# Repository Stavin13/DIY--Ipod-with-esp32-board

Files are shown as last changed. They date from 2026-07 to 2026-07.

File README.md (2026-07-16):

# ESP32-S3 iPod Music Player

A custom-built portable music player with modern touch interface and physical controls.

## Hardware Specifications

- **MCU**: ESP32-S3 (16MB Flash, 8MB PSRAM)
- **Display**: 2.8" ILI9341 capacitive touch (240x320px)
- **Storage**: 256GB microSD card
- **Audio**: USB-C (PCM2912A codec) + 3.5mm jack
- **Power**: USB-C PD (IP2723T) + 18650 LiPo (3500mAh)
- **Input**: Rotary encoder (KY-040) + capacitive touch
- **Connectivity**: Bluetooth 5.0 A2DP

## Key Features

- USB-C Power Delivery (15W charging)
- Simultaneous charging and digital audio output
- Bluetooth wireless streaming
- Touch + rotary encoder navigation
- 24-bit/96kHz audio quality
- 6-8 hours battery life
- OTA updates

## Development Phases

1. **Phase 1**: Core Hardware Setup
2. **Phase 2**: Basic Software (Display, SD, Audio, Encoder)
3. **Phase 3**: Advanced Features (USB-C, Bluetooth, Touch)
4. **Phase 4**: Polish (Album Art, Animations, EQ)

## Budget: ₹3,450 (~$45 USD)

## Timeline: 12 weeks

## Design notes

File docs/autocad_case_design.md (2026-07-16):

# AutoCAD Case Design Tutorial - ESP32-S3 iPod

## Software Options

### **AutoCAD (Professional)**
- **Best for**: Precise 2D drawings, technical documentation
- **Cost**: 
  - **Students**: FREE (3-year license)
  - **Commercial**: ₹15,000/year (subscription)
- **Learning curve**: Moderate to steep
- **Get it**: education.autodesk.com with student email

### **Fusion 360 (Recommended for 3D)**
- **Best for**: 3D modeling, parametric design
- **Cost**: 
  - **Students**: FREE (3-year license)
  - **Personal**: FREE (limited features)
  - **Commercial**: $545/year
- **Learning curve**: Easier than AutoCAD for 3D

### **Free Alternatives**
- **FreeCAD**: Open source, similar to Fusion 360
- **Tinkercad**: Browser-based, very beginner friendly
- **SketchUp**: Easy 3D modeling

## How to Get Free Student Licenses

### **Autodesk Education (AutoCAD + Fusion 360)**

#### **Requirements:**
- **Valid student email** (.edu or institution email)
- **Student ID** or enrollment verification
- **Academic institution** (college, university, trade school)

#### **Steps to Get Free Access:**
1. **Visit**: education.autodesk.com
2. **Create account** with student email
3. **Verify student status** (upload student ID)
4. **Download software**:
   - AutoCAD (2D/3D design)
   - Fusion 360 (3D modeling)
   - Inventor (3D mechanical design)
   - Maya (3D animation)
   - 3ds Max (3D modeling)

#### **What You Get:**
- **3-year license** (renewable)
- **Full professional version** (not limited)
- **All features unlocked**
- **Commercial-grade tools**
- **Free updates**

### **Alternative Student Programs**

#### **SolidWorks Student Edition**
- **Cost**: ₹3,000-5,000/year for students
- **Features**: Full professional CAD suite
- **Best for**: Mechanical engineering projects

#### **Onshape (Browser-based)**
- **Cost**: Free for students and public projects
- **Features**: Cloud-based CAD, collaboration
- **Best for**: Team projects, no installation needed

## Software Comparison for Your iPod Case

### **AutoCAD (Free for Students)**
#### **Pros:**
✅ **Industry standard** - Widely used professionally
✅ **Precise 2D drafting** - Perfect technical drawings
✅ **3D capabilities** - Can create 3D models
✅ **Free for students** - No cost barrier
✅ **Extensive tutorials** - Lots of learning resources

#### **Cons:**
❌ **Steep learning curve** - Takes time to master
❌ **Complex interface** - Many tools and options
❌ **Better for 2D** - 3D modeling is more complex

#### **Best for Your Project:**
- Creating **technical drawings** with precise dimensions
- **2D profiles** that can be exported to other 3D software
- **Professional documentation** of your design

### **Fusion 360 (Free for Students)**
#### **Pros:**
✅ **Modern 3D modeling** - Intuitive parametric design
✅ **Integrated workflow** - Sketch → Model → Simulate → Manufacture
✅ **Built-in 3D printing** - Direct STL export
✅ **Cloud-based** - Access from anywhere
✅ **Easier learning curve** - More user-friendly

#### **Cons:**
❌ **Internet required** - Cloud-based software
❌ **Less precise 2D** - Not as good for technical drawings

#### **Best for Your Project:**
- **3D modeling** the actual case
- **Parametric design** - Easy to modify dimensions
- **3D printing preparation** - Built-in tools

## Recommended Workflow (Using Both)

### **Phase 1: Planning in AutoCAD**
1. **Create precise 2D drawings**
   - Front view with exact dimensions
   - Side view with component layout
   - Bottom view with port positions
2. **Technical documentation**
   - Dimension drawings
   - Assembly instructions
   - Bill of materials

### **Phase 2: 3D Modeling in Fusion 360**
1. **Import 2D profiles** from AutoCAD
2. **Create 3D model** using sketches
3. **Add features** (fillets, chamfers, etc.)
4. **Test fit** with component models
5. **Export STL** for 3D printing

### **Phase 3: Manufacturing**
1. **3D print** prototype from Fusion 360
2. **Test fit** with actual components
3. **Iterate design** based on testing
4. **Final production** files

## Getting Started Steps

### **1. Get Student Licenses (Free)**
```
Visit: education.autodesk.com
Sign up with: your student email
Download: AutoCAD + Fusion 360
Verify: student status (may take 24-48 hours)
```

### **2. Learn the Basics**
#### **AutoCAD (2-3 hours)**
- Basic drawing commands (LINE, RECTANGLE, CIRCLE)
- Modification tools (MOVE, COPY, FILLET)
- Dimensioning and layers
- 2D layout of your iPod case

#### **Fusion 360 (3-4 hours)**
- Sketching basics
- Extrude and revolve features
- Assembly and constraints
- 3D modeling your case

### **3. Design Your Case**
#### **Week 1: AutoCAD**
- Measure all components precisely
- Create 2D technical drawings
- Plan internal layout

#### **Week 2: Fusion 360**
- Build 3D model from 2D drawings
- Add all features and cutouts
- Export STL for printing

## Learning Resources

### **AutoCAD Tutorials**
- **Autodesk University** (free courses)
- **YouTube**: "AutoCAD Basics" by Autodesk
- **LinkedIn Learning**: AutoCAD courses
- **Local colleges**: Often offer CAD courses

### **Fusion 360 Tutorials**
- **Fusion 360 Academy** (official tutorials)
- **YouTube**: "Learn Fusion 360 in 30 Days"
- **Coursera**: Fusion 360 for Beginners
- **Udemy**: Fusion 360 courses (often ₹500-1000)

### **Step 1: Set Up Your Workspace**

#### **Create New Drawing**
```
File → New → acadiso.dwt (metric template)
```

#### **Set Units**
```
Format → Units
- Type: Decimal
- Precision: 0.00
- Insertion scale: Millimeters
```

#### **Set Up Layers**
```
Layer Properties Manager (LA command):
- Layer 1: "OUTLINE" (Red, 0.5mm line)
- Layer 2: "DIMENSIONS" (Blue, 0.25mm line)  
- Layer 3: "COMPONENTS" (Green, 0.35mm line)
- Layer 4: "CUTOUTS" (Magenta, 0.5mm line)
- Layer 5: "CENTERLINES" (Yellow, dashed)
```

### **Step 2: Create the Basic Outline**

#### **Draw Main Rectangle**
```
Command: RECTANGLE (REC)
First corner: 0,0
Other corner: 70,110
```

#### **Add Rounded Corners**
```
Command: FILLET (F)
Radius: 8
Select first line: [click top edge]
Select second line: [click right edge]
Repeat for all 4 corners
```

### **Step 3: Add Component Cutouts**

#### **Display Cutout (Front View)**
```
Command: RECTANGLE
First corner: 10,25
Other corner: 60,85
(Creates 50×60mm display opening)

Command: FILLET
Radius: 2
Apply to all corners of display rectangle
```

#### **USB-C Port (Bottom View)**
```
Command: RECTANGLE  
First corner: 30,0
Other corner: 40,5
(Creates 10×5mm USB-C cutout)

Command: FILLET
Radius: 1
Apply to top corners only
```

#### **Power Button (Bottom View)**
```
Command: CIRCLE
Center: 55,2.5
Radius: 2
(Creates 4mm diameter button hole)
```

#### **SD Card Slot (Side View)**
```
Command: RECTANGLE
First corner: 70,40
Other corner: 75,55
(Creates 5×15mm SD slot)
```

### **Step 4: Add Internal Component Layout**

#### **Switch to "COMPONENTS" Layer**
```
Layer Properties → Set "COMPONENTS" as current
```

#### **ESP32-S3 Footprint**
```
Command: RECTANGLE
First corner: 15,15
Other corner: 40,35
(25×20mm ESP32 module)
```

#### **Display Module**
```
Command: RECTANGLE
First corner: 8,22
Other corner: 62,88
(54×66mm display module)
```

#### **Battery Compartment**
```
Command: CIRCLE
Center: 35,70
Radius: 9
(18mm diameter for 18650 battery)

Command: RECTANGLE
First corner: 26,70
Other corner: 44,95
(18×25mm battery length)
```

#### **USB-C PD Board**
```
Command: RECTANGLE
First corner: 45,15
Other corner: 65,35
(20×20mm PD board)
```

### **Step 5: Create Cross-Section Views**

#### **Side Cross-Section**
```
Command: LINE
Draw vertical line at X=35 (centerline)

Show internal stack:
- Front cover: 0-1mm
- Display: 1-4mm  
- PCB space: 4-6mm
- Components: 6-9mm
- Battery: 9-12mm
- Back cover: 12-15mm
```

### **Step 6: Add Dimensions**

#### **Switch to "DIMENSIONS" Layer**
```
Layer Properties → Set "DIMENSIONS" as current
```

#### **Overall Dimensions**
```
Command: DIMLINEAR (DLI)
- Overall width: 70mm
- Overall height: 110mm
- Overall depth: 15mm
```

#### **Component Dimensions**
```
Command: DIMLINEAR
- Display opening: 50×60mm
- USB-C cutout: 10×5mm
- Button hole: ⌀4mm
- Corner radius: R8mm
```

### **Step 7: Create 3D Model (Optional)**

#### **Extrude the Profile**
```
Command: EXTRUDE (EXT)
Select: Main outline
Height: 15
Taper: 0
```

#### **Subtract Cutouts**
```
Command: SUBTRACT (SU)
Select solids to subtract from: [main body]
Select solids to subtract: [all cutouts]
```

### **Step 8: Create Technical Drawings**

#### **Front View**
```
- Main outline with rounded corners
- Display cutout
- Component positions (dashed lines)
- Dimensions and tolerances
```

#### **Bottom View**
```
- USB-C port cutout
- Power button hole
- Screw hole positions
- Assembly notes
```

#### **Side View**
```
- Internal component stack
- Wall thickness (2mm minimum)
- Ventilation considerations
```

#### **Exploded View**
```
- Front bezel
- Main body
- Internal components
- Back cover
- Assembly sequence
```

## AutoCAD Commands Cheat Sheet

### **Essential Drawing Commands**
```
LINE (L)        - Draw lines
RECTANGLE (REC) - Draw rectangles  
CIRCLE (C)      - Draw circles
ARC (A)         - Draw arcs
POLYLINE (PL)   - Draw connected lines
SPLINE (SPL)    - Draw curves
```

### **Modification Commands**
```
MOVE (M)        - Move objects
COPY (CO)       - Copy objects
ROTATE (RO)     - Rotate objects
SCALE (SC)      - Scale objects
FILLET (F)      - Round corners
CHAMFER (CHA)   - Cut corners
TRIM (TR)       - Trim lines
EXTEND (EX)     - Extend lines
```

### **Precision Tools**
```
OSNAP (F3)      - Object snaps
ORTHO (F8)      - Orthogonal mode
POLAR (F10)     - Polar tracking
OTRACK (F11)    - Object tracking
```

### **View Commands**
```
ZOOM (Z)        - Zoom in/out
PAN (P)         - Pan view
REGEN (RE)      - Regenerate display
```

## Design Tips for 3D Printing

### **Wall Thickness**
- **Minimum**: 1.5mm for structural walls
- **Recommended**: 2-3mm for durability
- **Thick areas**: 4-5mm around screw holes

### **Tolerances**
- **Tight fit**: +0.1mm clearance
- **Sliding fit**: +0.2mm clearance  
- **Loose fit**: +0.3mm clearance
- **Threaded holes**: Tap size -0.2mm

### **Support Considerations**
- **Overhangs**: Keep under 45° angle
- **Bridges**: Maximum 5mm without support
- **Holes**: Vertical holes print better than horizontal

### **Assembly Features**
```
Snap-fit clips:   0.5mm deflection
Screw bosses:     M3 screws, 5mm diameter boss
Press-fit pins:   0.1mm interference fit
Living hinges:    0.8mm thickness
```

## Export for 3D Printing

### **From AutoCAD to STL**
```
1. Create 3D solid model
2. Command: 3DPRINT
3. Select objects
4. Choose STL format
5. Set units to millimeters
6. Export to file
```

### **Alternative Workflow**
```
AutoCAD → Export DWG → Import to Fusion 360 → Create 3D model → Export STL
```

## File Organization

### **Recommended File Structure**
```
iPod_Case_Project/
├── Drawings/
│   ├── iPod_Front_View.dwg
│   ├── iPod_Side_View.dwg
│   ├── iPod_Bottom_View.dwg
│   └── iPod_Assembly.dwg
├── 3D_Models/
│   ├── Front_Bezel.dwg
│   ├── Main_Body.dwg
│   └── Back_Cover.dwg
├── Export/
│   ├── Technical_Drawings.pdf
│   └── 3D_Models.stl
└── Reference/
    ├── Component_Datasheets.pdf
    └── Measurement_Photos.jpg
```

## Next Steps

1. **Practice basic commands** with simple shapes
2. **Measure your actual components** for accurate dimensions
3. **Create 2D technical drawings** first
4. **Build 3D model** from 2D profiles
5. **Export STL files** for 3D printing
6. **Test print** a small section first

Would you like me to create specific AutoCAD command sequences for any particular part of the case design?

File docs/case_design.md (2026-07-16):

# 3D Case Design - ESP32-S3 iPod

## Overall Design Philosophy

**Modern iPod Classic** - Clean, minimalist design inspired by the iconic iPod but with contemporary touches like USB-C and a larger color display.

## Dimensions & Form Factor

### **Overall Size**
```
Width:  70mm (2.75")
Height: 110mm (4.33") 
Depth:  15mm (0.59")
Weight: ~150g (with battery)
```

### **Comparison to Original iPod**
- **iPod Classic**: 62×104×10mm
- **Our iPod**: 70×110×15mm (slightly larger for modern components)

## Front Face Design

```
┌─────────────────────────────────┐ ← 70mm wide
│  ┌─────────────────────────┐   │
│  │                         │   │ ← 2.8" Display
│  │     240×320 Display     │   │   (60×45mm active area)
│  │                         │   │
│  │                         │   │
│  └─────────────────────────┘   │
│                                 │
│        ┌─────────────┐         │ ← Rotary Encoder
│        │      ●      │         │   (if included)
│        │   ┌─────┐   │         │
│        │   │  ○  │   │         │ ← Center button
│        │   └─────┘   │         │
│        └─────────────┘         │
│                                 │
│  ESP32-S3 iPod                 │ ← Branding
└─────────────────────────────────┘ ← 110mm tall
```

## Side Views & Ports

### **Left Side**
```
┌─────────────────┐
│                 │ ← Clean, no ports
│                 │
│                 │
│                 │
└─────────────────┘
```

### **Right Side**  
```
┌─────────────────┐
│                 │
│    ┌──┐         │ ← MicroSD slot
│    └──┘         │   (spring-loaded)
│                 │
└─────────────────┘
```

### **Bottom Edge (Single USB-C)**
```
┌─────────────────────────────────┐
│           ⚡        ○           │
│         USB-C    Power          │
│    (Audio/Charge) Button        │
└─────────────────────────────────┘
```

**Much cleaner!** Just like modern smartphones and tablets.

### **Top Edge**
```
┌─────────────────────────────────┐
│                                 │ ← Clean, minimal
└─────────────────────────────────┘
```

## Internal Layout (Cross-Section)

### **Layer Stack (Front to Back)**
```
Front Glass/Acrylic (1mm)
├─ Display Module (3mm)
├─ Main PCB/Breadboard (2mm)
├─ ESP32-S3 + Components (3mm)
├─ USB-C PD Board (2mm)
├─ 18650 Battery (18mm diameter)
└─ Back Cover (2mm)

Total Depth: ~15mm
```

### **Component Arrangement**
```
Top View (Internal):
┌─────────────────────────────────┐
│ ┌─────────────────────────┐     │
│ │      Display PCB        │     │
│ └─────────────────────────┘     │
│                                 │
│ ┌──────┐  ┌─────────┐          │
│ │ESP32 │  │USB-C PD │          │
│ │ S3   │  │ Board   │          │
│ └──────┘  └─────────┘          │
│                                 │
│ ┌─────────────────────────┐     │
│ │    18650 Battery        │     │
│ │    (3500mAh)           │     │
│ └─────────────────────────┘     │
│                                 │
│ ┌────┐                         │
│ │ SD │  ┌─────────────┐        │
│ │Card│  │  Encoder    │        │
│ └────┘  │  (optional) │        │
│         └─────────────┘        │
└─────────────────────────────────┘
```

## Single USB-C Design Benefits

### **Ultra-Clean Aesthetic** ✨
- **Minimalist bottom edge** - Just one port + power button
- **Symmetrical design** - USB-C centered, power button offset
- **Modern look** - Like iPhone, iPad, MacBook design language
- **No confusion** - One port does everything

### **User Experience**
```
Plug in charger     → Device charges
Plug in headphones  → Audio plays  
Plug in computer    → File transfer
Nothing plugged in  → Battery mode
```

### **Case Design Advantages**
- **Simpler manufacturing** - Fewer cutouts to machine
- **Better structural integrity** - Less material removed
- **Easier sealing** - Fewer openings for dust/water
- **More space inside** - Room for bigger battery or components

### **Port Layout Options**

#### **Option A: Centered USB-C**
```
┌─────────────────────────────────┐
│        ⚡           ○          │
│      USB-C       Power         │
└─────────────────────────────────┘
```

#### **Option B: Off-Center (More Balanced)**
```
┌─────────────────────────────────┐
│     ⚡              ○          │
│   USB-C          Power         │
└─────────────────────────────────┘
```

#### **Option C: Corner Placement**
```
┌─────────────────────────────────┐
│ ⚡                        ○    │
│USB-C                   Power   │
└─────────────────────────────────┘
```

### **Version 1: Touch + Encoder (Classic iPod Style)**
```
Front Face:
┌─────────────────────────────────┐
│  ┌─────────────────────────┐   │
│  │    Touch Display        │   │
│  └─────────────────────────┘   │
│                                 │
│        ┌─────────────┐         │
│        │  Scroll     │         │ ← iPod-style
│        │   Wheel     │         │   click wheel
│        │     ●       │         │
│        └─────────────┘         │
└─────────────────────────────────┘
```

### **Version 2: Touch Only (Modern Style)**
```
Front Face:
┌─────────────────────────────────┐
│  ┌─────────────────────────┐   │
│  │                         │   │
│  │    Large Touch          │   │ ← Bigger display
│  │     Display             │   │   area
│  │                         │   │
│  │                         │   │
│  └─────────────────────────┘   │
│                                 │
│  ┌─┐ ┌─┐ ┌─┐                  │ ← Capacitive
│  │◀│ │●│ │▶│                  │   touch buttons
│  └─┘ └─┘ └─┘                  │
└─────────────────────────────────┘
```

### **Version 3: Minimal (Ultra-Clean)**
```
Front Face:
┌─────────────────────────────────┐
│                                 │
│  ┌─────────────────────────┐   │
│  │                         │   │
│  │     Full Touch          │   │ ← Edge-to-edge
│  │     Display             │   │   display
│  │                         │   │
│  │                         │   │
│  └─────────────────────────┘   │
│                                 │
└─────────────────────────────────┘
```

## Material & Finish Options

### **Budget Version (₹200)**
- **Material**: PLA plastic (3D printed)
- **Finish**: Matte black or white
- **Features**: Basic functionality, simple design

### **Premium Version (₹500)**
- **Material**: ABS plastic with post-processing
- **Finish**: Glossy white (iPod classic style)
- **Features**: Smooth finish, better fit and finish

### **Luxury Version (₹1000)**
- **Material**: Aluminum (CNC machined) or high-quality resin
- **Finish**: Anodized aluminum or polished resin
- **Features**: Premium feel, perfect fit, professional appearance

## Color Options

### **Classic iPod Colors**
- **iPod White** - Glossy white with silver accents
- **Space Gray** - Matte dark gray
- **Product Red** - Glossy red finish
- **Rose Gold** - Light pink/gold metallic

### **Modern Colors**
- **Midnight Black** - Deep matte black
- **Ocean Blue** - Deep blue with metallic finish
- **Forest Green** - Dark green matte
- **Sunset Orange** - Vibrant orange

## Assembly Features

### **Easy Assembly Design**
```
┌─────────────────────────────────┐
│ Front Bezel (clips on)          │
├─────────────────────────────────┤
│ Main Body (screws together)     │
├─────────────────────────────────┤
│ Back Cover (removable)          │
└─────────────────────────────────┘
```

### **Access Points**
- **Battery compartment** - Removable back cover
- **SD card slot** - Side access with spring mechanism
- **USB-C ports** - Bottom cutouts with proper clearance
- **Display** - Front bezel with gasket seal

## Special Features

### **Display Protection**
- **Tempered glass** or **acrylic window** (₹100)
- **Anti-glare coating** option
- **Oleophobic coating** for fingerprint resistance

### **Ergonomics**
- **Rounded edges** for comfortable grip
- **Textured back** for better grip
- **Balanced weight distribution**
- **Pocket-friendly size**

### **Cooling**
- **Ventilation slots** (hidden in design)
- **Heat dissipation channels** for ESP32
- **Thermal pads** for hot components

## 3D Printing Specifications

### **Print Settings**
```
Layer Height: 0.2mm
Infill: 20-30%
Supports: Yes (for overhangs)
Print Speed: 50mm/s
Nozzle Temp: 210°C (PLA) / 250°C (ABS)
Bed Temp: 60°C (PLA) / 100°C (ABS)
```

### **Post-Processing**
1. **Remove supports** carefully
2. **Sand smooth** (220 → 400 → 800 grit)
3. **Prime and paint** (if desired)
4. **Apply clear coat** for durability

## Cost Breakdown

### **DIY 3D Printing**
- **Filament cost**: ₹50-100
- **Print time**: 8-12 hours
- **Post-processing**: 2-4 hours
- **Total**: ₹50-100 + time

### **Professional 3D Printing Service**
- **Basic PLA**: ₹200-300
- **Premium ABS**: ₹400-600
- **Resin (high detail)**: ₹600-1000

### **CNC Aluminum** (Ultimate)
- **Material + machining**: ₹2000-5000
- **Anodizing**: ₹500-1000
- **Total**: ₹2500-6000

## Files Provided

When you're ready to build, I can provide:
- **3D CAD files** (.step, .stl)
- **Technical drawings** with dimensions
- **Assembly instructions** with photos
- **Bill of materials** for hardware (screws, etc.)
- **Print settings** optimized for different printers

The case design balances the iconic iPod aesthetic with modern functionality - clean, minimal, but with all the ports and features you need for a contemporary music player!

Which style appeals to you most? The classic iPod look with the scroll wheel, or a more modern touch-only design?

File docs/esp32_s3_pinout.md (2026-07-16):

# ESP32-S3-N16R8 Pinout & iPod Pin Usag

## ESP32-S3-N16R8 Complete Pinout

```
                    ESP32-S3-N16R8 DevKit-C
                    ┌─────────────────────┐
                    │                     │
                    │        USB-C        │
                    │                     │
    3V3  ●──────────┤ 3V3             EN  ├──────────● EN
    GND  ●──────────┤ GND            IO0  ├──────────● GPIO0 (Boot)
    TX   ●──────────┤ TX             IO1  ├──────────● GPIO1 🎵 ENCODER_CLK
    RX   ●──────────┤ RX             IO2  ├──────────● GPIO2 🎵 ENCODER_DT
    GPIO1●──────────┤ IO1            IO42 ├──────────● GPIO42
    GPIO2●──────────┤ IO2            IO41 ├──────────● GPIO41
    GPIO42●─────────┤ IO42           IO40 ├──────────● GPIO40
    GPIO41●─────────┤ IO41           IO39 ├──────────● GPIO39 🔋 POWER_ENABLE
    GPIO40●─────────┤ IO40           IO38 ├──────────● GPIO38 💾 SD_SCLK
    GPIO39●─────────┤ IO39           IO37 ├──────────● GPIO37 💾 SD_MISO
    GPIO38●─────────┤ IO38           IO36 ├──────────● GPIO36 💾 SD_MOSI
    GPIO37●─────────┤ IO37           IO35 ├──────────● GPIO35 💾 SD_CS
    GPIO36●─────────┤ IO36           IO0  ├──────────● GPIO0 (Boot)
    GPIO35●─────────┤ IO35           IO45 ├──────────● GPIO45
    GPIO0 ●─────────┤ IO0            IO48 ├──────────● GPIO48
    GPIO45●─────────┤ IO45           IO47 ├──────────● GPIO47
    GPIO48●─────────┤ IO48           IO21 ├──────────● GPIO21 🔋 CHARGE_STATUS
    GPIO47●─────────┤ IO47           IO14 ├──────────● GPIO14
    GPIO21●─────────┤ IO21           IO13 ├──────────● GPIO13 📺 TFT_MISO
    GPIO14●─────────┤ IO14           IO12 ├──────────● GPIO12 📺 TFT_SCLK
    GPIO13●─────────┤ IO13           IO11 ├──────────● GPIO11 📺 TFT_MOSI
    GPIO12●─────────┤ IO12           IO10 ├──────────● GPIO10 📺 TFT_CS
    GPIO11●─────────┤ IO11           IO9  ├──────────● GPIO9  📺 TFT_DC
    GPIO10●─────────┤ IO10           IO46 ├──────────● GPIO46
    GPIO9 ●─────────┤ IO9            IO3  ├──────────● GPIO3  👆 TOUCH_IRQ
    GPIO46●─────────┤ IO46           IO8  ├──────────● GPIO8  📺 TFT_RST
    GPIO3 ●─────────┤ IO3            IO18 ├──────────● GPIO18 🎧 USB_AUDIO_DP
    GPIO8 ●─────────┤ IO8            IO17 ├──────────● GPIO17 🎧 USB_AUDIO_EN
    GPIO18●─────────┤ IO18           IO16 ├──────────● GPIO16
    GPIO17●─────────┤ IO17           IO15 ├──────────● GPIO15
    GPIO16●─────────┤ IO16           IO7  ├──────────● GPIO7  👆 TOUCH_CLK
    GPIO15●─────────┤ IO15           IO6  ├──────────● GPIO6  👆 TOUCH_CS
    GPIO7 ●─────────┤ IO7            IO5  ├──────────● GPIO5  👆 TOUCH_DIN
    GPIO6 ●─────────┤ IO6            IO4  ├──────────● GPIO4  👆 TOUCH_DO
    GPIO5 ●─────────┤ IO5            GND  ├──────────● GND
    GPIO4 ●─────────┤ IO4            5V   ├──────────● 5V
                    │                     │
                    └─────────────────────┘
```

## iPod Project Pin Assignments (Pure Touch Interface)

### 📺 TFT Display with Built-in Touch (ILI9341 + XPT2046) - Single Module
```
ESP32-S3    Function    Display Pin    Description
GPIO10  →   TFT_CS   →  CS            Display Chip Select
GPIO9   →   TFT_DC   →  DC/RS         Display Data/Command
GPIO8   →   TFT_RST  →  RST           Display Reset
GPIO11  →   TFT_MOSI →  SDA/MOSI      Display Data Out
GPIO12  →   TFT_SCLK →  SCL/SCLK      Display Clock
GPIO13  →   TFT_MISO →  SDO/MISO      Display Data In (optional)
GPIO6   →   TOUCH_CS →  T_CS          Touch Chip Select
GPIO7   →   TOUCH_CLK→  T_CLK         Touch Clock
GPIO5   →   TOUCH_DIN→  T_DIN         Touch Data In
GPIO4   →   TOUCH_DO →  T_DO          Touch Data Out
GPIO3   →   TOUCH_IRQ→  T_IRQ         Touch Interrupt (optional)
3.3V    →   VCC      →  VCC           Power
3.3V    →   LED      →  LED           Backlight
GND     →   GND      →  GND           Ground
```

### 💾 SD Card Module - SPI3
```
ESP32-S3    Function    SD Module     Description
GPIO35  →   SD_CS    →  CS           Chip Select
GPIO36  →   SD_MOSI  →  MOSI/CMD     Data Out
GPIO37  →   SD_MISO  →  MISO/DAT0    Data In
GPIO38  →   SD_SCLK  →  SCLK/CLK     Clock
3.3V    →   VCC      →  VCC          Power
GND     →   GND      →  GND          Ground
```

### 🎧 USB-C Audio & Power
```
ESP32-S3    Function           Description
GPIO18  →   USB_AUDIO_DP    →  USB Data Plus
GPIO19  →   USB_AUDIO_DN    →  USB Data Minus (built-in)
GPIO17  →   USB_AUDIO_EN    →  Audio Enable Control
GPIO20  →   USB_VBUS_DET    →  USB Power Detection
```

### 🔋 Power Management
```
ESP32-S3    Function           Description
GPIO39  →   POWER_ENABLE    →  Main Power Control
GPIO21  →   CHARGE_STATUS   →  Battery Charge Status
GPIO22  →   BATTERY_ADC     →  Battery Voltage Monitor
```

## Pin Usage Summary

### Used Pins (18 total):
- **GPIO3**: Touch IRQ (optional)
- **GPIO4**: Touch DO
- **GPIO5**: Touch DIN
- **GPIO6**: Touch CS
- **GPIO7**: Touch CLK
- **GPIO8**: TFT Reset
- **GPIO9**: TFT DC
- **GPIO10**: TFT CS
- **GPIO11**: TFT MOSI
- **GPIO12**: TFT SCLK
- **GPIO13**: TFT MISO (optional)
- **GPIO17**: USB Audio Enable
- **GPIO18**: USB Audio DP
- **GPIO19**: USB Audio DN (built-in)
- **GPIO20**: USB VBUS Detect
- **GPIO21**: Charge Status
- **GPIO22**: Battery ADC
- **GPIO35**: SD CS
- **GPIO36**: SD MOSI
- **GPIO37**: SD MISO
- **GPIO38**: SD SCLK
- **GPIO39**: Power Enable

### Available Pins (27 remaining):
- **GPIO0-2**: Available for future expansion
- **GPIO14-16**: Available for I2C devices, LEDs, sensors
- **GPIO40-48**: Available for additional features
- **Massive expansion potential**: Accelerometer, gyroscope, ambient light sensor, wireless charging, etc.

## Important Notes

### ⚠️ Special Pins:
- **GPIO0**: Boot pin - hold LOW during boot to enter download mode
- **GPIO19**: Built-in USB D- (can't be changed)
- **GPIO20**: Built-in USB D+ (can't be changed)
- **GPIO43, GPIO44**: Built-in UART (TX/RX)

### 🔧 Component Count:
- **ESP32-S3**: Main controller
- **TFT Display with Touch**: Single integrated module (your MSP2806)
- **SD Card Module**: Music storage
- **USB-C Components**: Power and audio
- **Battery System**: Power management

### 💡 Pure Touch Interface Benefits:
- **Zero physical buttons** - Completely touch-controlled
- **Single display module** - Built-in touch eliminates separate touch controller
- **Maximum simplicity** - Minimal component count
- **Modern UX** - Full gesture support (swipe, tap, long press)
- **Clean design** - No external buttons or encoders
- **Maximum GPIO availability** - 27 pins free for expansion

This pinout gives you the ultimate minimalist touchscreen iPod - just ESP32-S3, your existing display with built-in touch, SD card, and USB-C. Maximum simplicity with maximum functionality!

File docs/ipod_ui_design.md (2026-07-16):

# iPod UI Design Guide

## 🎨 UI Overview

I've created two versions of the iPod UI for your ESP32-S3:

### **Simple Version** (`src/ipod_ui_simple.cpp`)
- ✅ **Easy to test** - Basic functionality
- ✅ **4 main screens** - Home, Library, Now Playing, Settings
- ✅ **Touch navigation** - Tap to navigate
- ✅ **Clean design** - iPod-inspired interface

### **Advanced Version** (`src/ipod_ui_main.cpp`)
- 🚀 **Full featured** - Complete iPod experience
- 🚀 **8 screens** - Home, Library, Artists, Albums, Songs, Playlists, Now Playing, Settings
- 🚀 **Advanced controls** - Progress bars, volume control, context menus
- 🚀 **Status bar** - Time, battery, iPod branding

## 📱 Screen Layout

```
┌─────────────────────────────────┐ ← Status Bar (20px)
│ iPod        12:34        100% ⚡ │
├─────────────────────────────────┤
│                                 │
│                                 │ ← Content Area (260px)
│         Main Content            │
│                                 │
│                                 │
├─────────────────────────────────┤
│ Back │ Home │ Menu │ Playing    │ ← Navigation Bar (40px)
└─────────────────────────────────┘
```

## 🎯 Screen Flow

```
Home Screen
├── Music Library
│   ├── Artists → Artist Songs
│   ├── Albums → Album Songs  
│   ├── Songs → Now Playing
│   └── Playlists → Playlist Songs
├── Now Playing
│   ├── Play/Pause Controls
│   ├── Previous/Next
│   ├── Progress Bar
│   └── Volume Control
└── Settings
    ├── Display Settings
    ├── Audio Settings
    ├── Touch Calibration
    └── About
```

## 🎨 Color Scheme (iPod Classic Inspired)

```cpp
// Primary Colors
#define COLOR_BG 0x0000          // Black background
#define COLOR_TEXT 0xFFFF        // White text
#define COLOR_ACCENT 0x001F      // Blue accent

// Secondary Colors  
#define COLOR_GRAY 0x8410        // Gray for inactive items
#define COLOR_LIGHT_GRAY 0xC618  // Light gray for borders
#define COLOR_DARK_GRAY 0x4208   // Dark gray for backgrounds

// Status Colors
#define COLOR_GREEN 0x07E0       // Playing, battery good
#define COLOR_RED 0xF800         // Alerts, battery low
#define COLOR_ORANGE 0xFD20      // Warnings, medium battery
```

## 🖱️ Touch Interactions

### **Navigation Gestures:**
- **Tap** - Select item, press button
- **Touch & Hold** - Context menu (advanced version)
- **Swipe** - Scroll through lists (future enhancement)

### **Touch Areas:**

#### **Status Bar (Top 20px):**
- **Left**: iPod logo
- **Center**: Current time
- **Right**: Battery indicator (tap for details)

#### **Content Area (Middle):**
- **Menu Items**: Tap to select and navigate
- **Control Buttons**: Tap to activate
- **Progress Bars**: Tap to set position
- **Volume Bar**: Tap to adjust volume

#### **Navigation Bar (Bottom 40px):**
- **Back**: Return to previous screen
- **Home**: Go to home screen
- **Menu**: Context menu (advanced version)
- **Playing**: Jump to Now Playing screen

## 🎵 Now Playing Screen Features

### **Album Art Area:**
- 120x120 pixel placeholder
- Music note symbol when no art
- Future: Load actual album art from SD card

### **Song Information:**
- Song title (white text)
- Artist name (gray text)
- Album name (gray text, advanced version)

### **Playback Controls:**
- **Previous Button** (<<) - Previous track
- **Play/Pause Button** (>/||) - Toggle playback
- **Next Button** (>>) - Next track

### **Progress Control:**
- Visual progress bar
- Current time / Total time
- Tap to seek (advanced version)

### **Volume Control:**
- Visual volume bar
- Color-coded: Green (low) → Orange (medium) → Red (high)
- Tap to adjust volume level

## 🎛️ Control Feedback

### **Visual Feedback:**
- **Selected items** highlighted in blue
- **Active buttons** show pressed state
- **Progress bars** show current position
- **Status indicators** (playing symbol ♪)

### **Touch Feedback:**
- **Immediate response** to touch
- **Visual confirmation** of selection
- **Screen transitions** between views

## 📊 Sample Data Structure

```cpp
// Music Library Data
const char* artists[] = {
  "The Beatles", "Queen", "Led Zeppelin", "Pink Floyd"
};

const char* songs[] = {
  "Bohemian Rhapsody", "Stairway to Heaven", 
  "Hotel California", "Imagine"
};

// Playback State
struct PlaybackState {
  int currentSong = 0;
  bool isPlaying = false;
  int progress = 0;      // 0-100%
  int volume = 75;       // 0-100%
  bool shuffle = false;
  bool repeat = false;
};
```

## 🚀 Getting Started

### **Step 1: Test Simple Version**
1. Upload `src/ipod_ui_simple.cpp`
2. Calibrate touch if needed
3. Test basic navigation

### **Step 2: Try Advanced Version**
1. Upload `src/ipod_ui_main.cpp`
2. Explore all screens and features
3. Test touch controls

### **Step 3: Customize**
1. Modify colors in color definitions
2. Add your own sample music data
3. Adjust touch sensitivity if needed

## 🎨 Customization Options

### **Colors:**
```cpp
// Change accent color
#define COLOR_ACCENT 0x07E0  // Green instead of blue

// Custom theme colors
#define COLOR_ACCENT 0xF81F  // Magenta theme
#define COLOR_ACCENT 0xFFE0  // Yellow theme
```

### **Layout:**
```cpp
// Adjust bar heights
#define STATUS_BAR_HEIGHT 25    // Taller status bar
#define NAV_BAR_HEIGHT 50       // Taller navigation

// Menu item spacing
int itemHeight = 35;            // More space between items
```

### **Sample Data:**
```cpp
// Add your favorite music
const char* songs[] = {
  "Your Song 1",
  "Your Song 2", 
  "Your Song 3"
};
```

## 🔧 Future Enhancements

### **Phase 1 (Current):**
- ✅ Touch navigation
- ✅ Multiple screens
- ✅ Basic controls
- ✅ Visual feedback

### **Phase 2 (Next):**
- 🔄 SD card music loading
- 🔄 Actual audio playback
- 🔄 Album art display
- 🔄 Gesture recognition

### **Phase 3 (Advanced):**
- 🔄 Smooth animations
- 🔄 Custom fonts
- 🔄 Equalizer visualization
- 🔄 Wireless connectivity

The UI is designed to be modular and expandable - you can easily add new screens, modify existing ones, or integrate with actual audio playback functionality!

## 📱 Screen Previews

### **Home Screen:**
```
┌─────────────────────────┐
│ iPod    12:34    100% ⚡ │
├─────────────────────────┤
│ Music                   │
│                         │
│ > Music Library         │
│   Now Playing           │
│   Playlists            │
│   Artists              │
│   Albums               │
│   Songs                │
│   Settings             │
└─────────────────────────┘
```

### **Now Playing Screen:**
```
┌─────────────────────────┐
│ iPod    12:34    100% ⚡ │
├─────────────────────────┤
│ Now Playing             │
│                         │
│    ┌─────────────┐      │
│    │      ♪      │      │
│    │   Album     │      │
│    │    Art      │      │
│    └─────────────┘      │
│                         │
│ Bohemian Rhapsody       │
│ Queen                   │
│                         │
│ ████████░░░░░░░░ 1:23    │
│                         │
│  <<    ▶️    >>         │
│                         │
│ Volume ████████░░░ 75%  │
└─────────────────────────┘
```

This gives you a complete, functional iPod interface that you can test and expand upon!

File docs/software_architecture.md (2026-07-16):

# Software Architecture

## Overview

The ESP32-S3 iPod software is built using a modular architecture with separate managers for different subsystems. This design allows for easy testing, maintenance, and feature additions.

## Core Managers

### DisplayManager
- **Purpose**: Handles TFT display and LVGL integration
- **Responsibilities**:
  - TFT initialization and configuration
  - LVGL display driver setup
  - Brightness control
  - Sleep/wake functionality
- **Files**: `src/display/display_manager.h/cpp`

### AudioManager
- **Purpose**: Manages audio playback and routing
- **Responsibilities**:
  - I2S audio output
  - MP3/FLAC/WAV decoding
  - Volume control
  - Playback state management
  - Bluetooth A2DP
  - USB audio
- **Files**: `src/audio/audio_manager.h/cpp`

### SDManager
- **Purpose**: Handles file system and music library
- **Responsibilities**:
  - SD card initialization
  - Music file scanning
  - Library organization (artists/albums)
  - File metadata parsing
  - Search functionality
- **Files**: `src/storage/sd_manager.h/cpp`

### InputManager
- **Purpose**: Processes user input from multiple sources
- **Responsibilities**:
  - Rotary encoder handling
  - Capacitive touch processing
  - Input event queuing
  - LVGL input driver
  - Gesture recognition
- **Files**: `src/input/input_manager.h/cpp`

### UIManager
- **Purpose**: Manages user interface and navigation
- **Responsibilities**:
  - Screen management
  - LVGL UI creation
  - Event handling
  - Status updates
  - Theme management
- **Files**: `src/ui/ui_manager.h/cpp`

### PowerManager
- **Purpose**: Handles power management and battery monitoring
- **Responsibilities**:
  - Battery voltage monitoring
  - Charge state detection
  - Power state transitions
  - Sleep/wake control
  - USB-C PD management
- **Files**: `src/power/power_manager.h/cpp`

## Data Flow

```
Input Events -> InputManager -> UIManager -> Audio/Storage Managers
                                    |
Battery/Power -> PowerManager -> UIManager -> Display Updates
                                    |
Audio Data -> SDManager -> AudioManager -> I2S Output
                              |
UI Updates -> UIManager -> DisplayManager -> TFT Display
```

## Key Design Patterns

### Manager Pattern
Each subsystem is encapsulated in a manager class that:
- Provides a clean interface to other components
- Handles initialization and cleanup
- Manages internal state
- Provides update methods for main loop

### Event-Driven Architecture
- Input events are queued and processed asynchronously
- UI updates are triggered by state changes
- Audio playback events drive UI updates

### State Machines
- Audio playback states (stopped/playing/paused)
- Power states (active/idle/sleep)
- UI navigation states

## Configuration

All hardware-specific settings are centralized in `src/config.h`:
- Pin assignments
- Display dimensions
- Audio settings
- File system paths
- UI colors and fonts

## Libraries Used

- **LVGL**: Graphics library for UI
- **TFT_eSPI**: Display driver
- **ESP32-AudioI2S**: Audio processing
- **Arduino-Audio-Tools**: Audio codecs
- **SD**: File system access
- **Wire**: I2C communication

## Build System

Uses PlatformIO for:
- Dependency management
- Cross-platform builds
- Library version control
- Upload and monitoring

## Future Enhancements

### Phase 2 Features
- Album art display
- Equalizer with presets
- Playlist management
- Shuffle/repeat modes

### Phase 3 Features
- Bluetooth A2DP source
- USB audio device mode
- OTA updates
- Web interface

### Phase 4 Features
- Streaming services (Spotify Connect)
- Voice control
- Advanced DSP effects
- Multi-room audio

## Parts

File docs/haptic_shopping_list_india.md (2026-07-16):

# ESP32-S3 iPod Haptic Feedback - Shopping List (India)

## 🛒 **Complete Component List with Indian Suppliers**

### **Core Haptic Components**

#### **1. DRV2605L Haptic Motor Driver Board**
```
Component: DRV2605L Breakout Board
Function: I2C haptic motor controller with 123 built-in effects
Voltage: 3.3V-5V compatible
Current: Up to 250mA output

🇮🇳 Indian Suppliers:
❌ Robu.in: Not available
✅ Amazon.in: ₹800-1200
   - Search: "DRV2605L haptic motor driver"
   - Brands: Adafruit compatible boards
✅ ElectronicsComp.com: ₹900-1100
✅ Electronicscomp.in: ₹850-1050
✅ Ktron.in: ₹950-1150

🌍 International Options:
✅ Adafruit.com: $7.95 + shipping
✅ SparkFun.com: $16.95 + shipping
✅ DigiKey.in: ₹1200-1500 (with customs)
```

#### **2. Linear Resonant Actuator (LRA)**
```
Component: 10mm Coin-type LRA
Specifications:
- Diameter: 10mm
- Height: 3-4mm  
- Resonant Frequency: 150-200Hz
- Operating Voltage: 3.3V
- Force: 0.7-1.2G

🎯 Recommended Models:
1. Precision Microdrives 310-103 (10mm x 3.4mm)
2. Jinlong Machinery C1034B013F (10mm x 3mm)
3. Vybronics VG1040003D (10mm x 4mm)

🇮🇳 Indian Suppliers:
❌ Robu.in: LRAs not available
❌ Most local suppliers: Don't stock LRAs

🌍 International Sources (Best Options):
✅ Precision Microdrives (UK): £3-5 + shipping
   - Website: precisionmicrodrives.com
   - Ships to India: Yes (₹500-800 total)
✅ DigiKey.in: ₹400-600 + GST
   - Part numbers: Various LRA options
✅ Mouser.in: ₹350-550 + GST
✅ AliExpress: ₹200-400 (2-4 weeks shipping)
   - Search: "10mm LRA linear resonant actuator"
   - Quality varies - check reviews

💡 Alternative: Vibration Motor (if LRA unavailable)
✅ Robu.in: ₹50-100
   - 10mm coin vibration motor
   - Less precise than LRA but functional
```

#### **3. Tactile Push Buttons (4x needed)**
```
Component: 6x6x5mm Tactile Switch
Specifications:
- Actuation Force: 160gf
- Travel: 0.25mm
- Life: 1M+ cycles
- Mounting: Through-hole

🇮🇳 Indian Suppliers:
✅ Robu.in: ₹8-15 each
   - Product: "6x6x5mm Tactile Push Button"
   - Pack of 10: ₹80-120
✅ Amazon.in: ₹10-20 each
✅ ElectronicsComp: ₹12-18 each
✅ Ktron.in: ₹10-16 each

Total needed: 4 buttons = ₹40-80
```

### **Display & MCU (Already Have)**
```
✅ ESP32-S3 DevKit: Already owned
✅ MSP2806 Display (2.8" ILI9341): Already owned
```

### **Supporting Components**

#### **4. Breadboard & Prototyping**
```
Half-size Breadboard: ₹80-120
Jumper Wires (M-M, 40pcs): ₹50-80
Jumper Wires (M-F, 40pcs): ₹60-90

🇮🇳 Suppliers:
✅ Robu.in: Complete prototyping kit ₹200-300
✅ Amazon.in: Individual components
✅ Local electronics markets: Cheapest option
```

#### **5. Power & Connectivity**
```
USB-C Cable (if needed): ₹100-200
Micro USB Cable (backup): ₹50-100
Power Bank (portable testing): ₹800-1500

🇮🇳 Suppliers:
✅ Any electronics store
✅ Amazon.in: Wide selection
```

#### **6. Assembly Hardware**
```
M2.5 Screws (8mm, 4pcs): ₹20-40
M3 Screws (6mm, 2pcs): ₹15-30
Double-sided foam tape: ₹50-100
Heat shrink tubing: ₹30-60

🇮🇳 Suppliers:
✅ Local hardware stores
✅ Amazon.in: Hardware kits
✅ Robu.in: Electronics hardware
```

## 💰 **Total Cost Breakdown**

### **Minimum Setup (Basic Haptic)**
```
DRV2605L Board: ₹800-1200
LRA (AliExpress): ₹200-400
Tactile Buttons (4x): ₹40-80
Breadboard Kit: ₹200-300
Hardware: ₹100-200

Total: ₹1,340-2,180 (~₹1,800 average)
```

### **Premium Setup (Best Components)**
```
DRV2605L Board: ₹1,000-1,200
LRA (Precision Microdrives): ₹500-800
Tactile Buttons (4x): ₹60-80
Breadboard Kit: ₹250-350
Hardware: ₹150-250
PCB (custom): ₹300-500

Total: ₹2,260-3,180 (~₹2,700 average)
```

## 🚚 **Ordering Strategy**

### **Phase 1: Local Components (1-2 days)**
```
✅ Order from Robu.in:
- 4x Tactile buttons (6x6x5mm)
- Breadboard and jumper wires
- Basic hardware (screws, tape)

✅ Order from Amazon.in:
- DRV2605L haptic driver board
- USB cables if needed
```

### **Phase 2: International LRA (1-4 weeks)**
```
Option A: Fast but expensive
✅ DigiKey.in or Mouser.in
- 1x 10mm LRA
- 2-5 days delivery
- ₹400-600 + GST

Option B: Economical but slower  
✅ AliExpress
- 2-3x 10mm LRAs (backup)
- 2-4 weeks delivery
- ₹200-400 total
```

### **Phase 3: Backup Plan**
```
If LRA unavailable/delayed:
✅ Use vibration motor from Robu.in
- 10mm coin vibration motor: ₹50-100
- Less precise but functional
- Can upgrade to LRA later
```

## 🔍 **Specific Product Recommendations**

### **DRV2605L Boards on Amazon.in**
```
Search Terms:
- "DRV2605L haptic motor driver"
- "Adafruit DRV2605L"
- "Haptic feedback controller"

Look for:
✅ I2C interface clearly mentioned
✅ 3.3V/5V compatibility
✅ Breakout board format
✅ Good seller ratings (4+ stars)
❌ Avoid: Generic boards without clear specs
```

### **LRA on AliExpress**
```
Search Terms:
- "10mm LRA linear resonant actuator"
- "Coin vibration motor LRA"
- "Haptic feedback actuator 10mm"

Look for:
✅ 10mm diameter, 3-4mm height
✅ 150-200Hz resonant frequency
✅ Wire leads (not solder pads)
✅ Seller with good feedback
❌ Avoid: ERM motors (different technology)
```

## 📦 **Recommended Order Sequence**

### **Week 1: Place Orders**
```
Day 1: Order DRV2605L + buttons from India
Day 2: Order LRA from international supplier
Day 3: Gather existing components (ESP32, display)
```

### **Week 2: Start Development**
```
Day 8: Receive Indian components
Day 9: Build basic circuit, test I2C
Day 10: Upload haptic test code
Day 11-14: Develop UI integration
```

### **Week 3-4: Complete Integration**
```
Day 15-21: Receive LRA
Day 22: Complete haptic system
Day 23-28: Test and refine
```

## 🎯 **Money-Saving Tips**

### **Budget Optimization**
```
💡 Start with vibration motor (₹50) instead of LRA (₹500)
💡 Buy button packs (10pcs) for future projects
💡 Use existing breadboard if available
💡 Order multiple LRAs from AliExpress for backup
💡 Check local electronics markets first
```

### **Quality vs Cost**
```
Spend More On:
✅ DRV2605L board (core functionality)
✅ Quality tactile buttons (user experience)

Save Money On:
✅ Breadboard (any brand works)
✅ Jumper wires (basic ones sufficient)
✅ Hardware screws (local hardware store)
```

## 🚨 **Important Notes**

### **Import Considerations**
```
⚠️ LRA Import: May attract customs duty (18-28%)
⚠️ Delivery Time: International orders 2-4 weeks
⚠️ Minimum Order: Some suppliers have minimum quantities
⚠️ Shipping Cost: Can double the component cost
```

### **Local Alternatives**
```
💡 Check local electronics markets:
- SP Road, Bangalore
- Lamington Road, Mumbai  
- Nehru Place, Delhi
- Ritchie Street, Chennai

💡 Contact local distributors:
- Many carry specialized components
- Bulk pricing available
- Immediate availability
```

## 🎵 **Final Recommendation**

**Best Approach for India:**
1. **Order DRV2605L + buttons locally** (₹900-1300)
2. **Start development with vibration motor** (₹50 from Robu.in)
3. **Order LRA from AliExpress** (₹200-400, as upgrade)
4. **Test everything with basic motor first**
5. **Upgrade to LRA when it arrives**

This gives you **immediate progress** while waiting for the premium LRA component! 🚀

**Total Budget: ₹1,200-1,800** for a fully functional haptic iPod interface.

The haptic feedback will make your iPod feel **premium and responsive** - every button press will have that satisfying tactile response! 🎯

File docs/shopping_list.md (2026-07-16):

# Complete Hardware Shopping List

## Core Components

### 1. **ESP32-S3 Development Board**
- **Part**: ESP32-S3-DevKitC-1 (16MB Flash, 8MB PSRAM)
- **Price**: ₹800-1200
- **Where**: Amazon, Robu.in, ElectronicsComp
- **Notes**: Make sure it has PSRAM for smooth UI

### 2. **Display Module** ✅ (You have this)
- **Part**: 2.8" ILI9341 TFT Display (240x320)
- **Price**: ₹600-900 (already purchased)
- **Notes**: Your MSP2806 module

### 3. **MicroSD Card Module**
- **Part**: MicroSD Card Reader Module (SPI)
- **Price**: ₹80-150
- **Where**: Amazon, local electronics
- **Notes**: Get one with 3.3V logic level

### 4. **MicroSD Card**
- **Part**: 256GB MicroSD Card (Class 10, U3)
- **Price**: ₹1200-1800
- **Where**: Amazon, Flipkart
- **Brands**: SanDisk, Samsung, Kingston

### 5. **Power & Audio Only**
- **Note**: No additional input components needed!
- **Your display**: Already has built-in touch controller
- **Interface**: 100% touchscreen - no buttons, no encoder, no extra modules

## Power System

### 6. **18650 Battery**
- **Part**: 18650 Li-ion Battery (3500mAh, Protected)
- **Price**: ₹400-600
- **Where**: Amazon, battery stores
- **Brands**: Panasonic, Samsung, LG

### 7. **18650 Battery Holder**
- **Part**: 18650 Single Cell Holder with Wires
- **Price**: ₹50-100
- **Where**: Amazon, local electronics

### 8. **USB-C Charging Module**
- **Part**: TP4056 USB-C Charging Board with Protection
- **Price**: ₹150-250
- **Where**: Amazon, AliExpress
- **Notes**: Must have over-discharge protection

## USB-C Audio System (Replaces 3.5mm jack)

### 9. **USB-C Connector Breakout**
- **Part**: USB-C Female Breakout Board
- **Price**: ₹100-200
- **Where**: Amazon, AliExpress
- **Notes**: Need access to D+, D-, VBUS, GND, CC pins

### 10. **USB Audio DAC IC**
- **Part**: PCM2912A USB Audio Codec IC
- **Price**: ₹300-500
- **Where**: Mouser, DigiKey, AliExpress
- **Alternative**: Use USB-C to 3.5mm DAC dongle (₹200-400)

### 11. **Audio Amplifier** (Optional - for built-in speaker)
- **Part**: MAX98357A I2S Audio Amplifier
- **Price**: ₹200-300
- **Where**: Amazon, AliExpress
- **Notes**: Only if you want internal speaker

## Additional Components

### 12. **Voltage Regulators**
- **Part**: AMS1117-3.3V Linear Regulator
- **Price**: ₹30-50 each
- **Quantity**: 2 pieces
- **Where**: Local electronics, Amazon

### 13. **Capacitors**
- **Parts**: 
  - 100nF Ceramic (10 pieces) - ₹20
  - 10µF Electrolytic (5 pieces) - ₹30
  - 22µF Electrolytic (2 pieces) - ₹20
- **Total**: ₹70
- **Where**: Local electronics

### 14. **Resistors**
- **Parts**: 
  - 10kΩ (5 pieces) - Pull-ups
  - 4.7kΩ (2 pieces) - I2C pull-ups
  - 1kΩ (3 pieces) - LEDs
- **Price**: ₹30-50
- **Where**: Local electronics

### 15. **Breadboard/PCB**
- **Option A**: Large Breadboard (₹200-300)
- **Option B**: Perfboard/Veroboard (₹100-150)
- **Option C**: Custom PCB (₹500-1000)

### 16. **Jumper Wires**
- **Part**: Male-Male, Male-Female Jumper Wires
- **Price**: ₹100-200
- **Where**: Amazon, local electronics

### 17. **Case/Enclosure**
- **Option A**: 3D Print Custom Case (₹200-400)
- **Option B**: Plastic Project Box (₹150-300)
- **Where**: Local electronics, 3D printing service

## USB-C Audio Options

### **Option 1: Simple USB-C DAC Dongle (Recommended)**
- **Part**: USB-C to 3.5mm DAC Adapter
- **Price**: ₹200-400
- **Pros**: Plug and play, high quality, compact
- **Cons**: External dongle required

### **Option 2: Integrated USB-C Audio**
- **Parts**: PCM2912A + USB-C connector + supporting components
- **Price**: ₹600-1000
- **Pros**: Built-in, professional
- **Cons**: Complex circuit, harder to implement

## Total Cost Breakdown

### **Minimalist Version (₹2,600-3,300)**
```
ESP32-S3 DevKit:        ₹800
Display (owned):        ₹0    ← Your MSP2806 with built-in touch
SD Module:              ₹100
256GB SD Card:          ₹1200
18650 Battery:          ₹500
Battery Holder:         ₹80
USB-C Charging:         ₹200
USB-C DAC Dongle:       ₹300
Components:             ₹200
Breadboard:             ₹200
Case:                   ₹200
------------------------
Total:                  ₹3,580
```

### **Premium Version (₹4,000-5,000)**
```
All above components plus:
Custom PCB:             ₹800
Premium case:           ₹400
Internal speaker:       ₹300
Premium battery:        ₹200
Wireless charging:      ₹400
------------------------
Total:                  ₹5,680
```

## Shopping Strategy

### **Phase 1: Core Functionality (₹1,300)**
1. ESP32-S3 DevKit
2. SD Card module + card
3. Basic components
4. Your display already has touch!

### **Phase 2: Power System (₹800)**
1. 18650 battery + holder
2. USB-C charging module
3. Voltage regulators

### **Phase 3: Audio & Case (₹600)**
1. USB-C DAC solution
2. Case/enclosure
3. Final assembly

## Where to Buy (India)

### **Online Stores**
- **Amazon India**: ESP32, SD cards, batteries, cases
- **Robu.in**: ESP32 modules, sensors, development boards
- **ElectronicsComp**: Electronic components, ICs
- **Flipkart**: SD cards, accessories
- **AliExpress**: Specialized modules (longer shipping)

### **Local Stores**
- **SP Road, Bangalore**: Electronics components
- **Lamington Road, Mumbai**: Electronics market
- **Nehru Place, Delhi**: Electronics hub
- **Ritchie Street, Chennai**: Electronics components

### **Specialized Suppliers**
- **Mouser/DigiKey**: High-quality ICs (for PCM2912A)
- **Element14**: Professional components
- **Digi-Key India**: Electronic components

## USB-C Audio Implementation

### **Simple Approach (Recommended)**
```
ESP32-S3 → USB-C Port (Data) → USB-C DAC Dongle → Headphones
         ↓
    USB-C Port (Power) → Charging Circuit → Battery
```

### **Advanced Approach**
```
ESP32-S3 → USB-C Controller → Audio DAC → Headphones
         ↓                 ↓
    Power Management ← USB-C PD Controller
```

The simple approach using a USB-C DAC dongle is much easier to implement and gives you professional audio quality immediately!

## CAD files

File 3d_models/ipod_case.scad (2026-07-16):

/*
ESP32-S3 iPod Case - OpenSCAD Model
Generate STL files for 3D printing
*/

// =====================================================
// PARAMETERS - Adjust these for your specific needs
// =====================================================

// Case dimensions
case_length = 110;
case_width = 65;
case_height = 18;
wall_thickness = 2;

// Display dimensions (MSP2806)
display_length = 52;
display_width = 39;
display_recess = 1;
display_offset_y = 15; // Distance from top

// ESP32-S3 dimensions
esp32_length = 55;
esp32_width = 25.5;
esp32_height = 15;

// Rotary encoder
encoder_diameter = 20;
encoder_hole = 7;
encoder_offset_y = 25; // Distance from display

// Button positions (relative to encoder center)
button_diameter = 4;
button_spacing = 15; // Distance from encoder center

// USB-C cutout
usb_width = 10;
usb_height = 4.5;

// =====================================================
// MAIN ASSEMBLY
// =====================================================

// Uncomment the part you want to generate:
top_shell();
//bottom_shell();

// =====================================================
// TOP SHELL (Front with display and buttons)
// =====================================================

module top_shell() {
    difference() {
        // Main shell body
        shell_body();
        
        // Display window
        translate([case_width/2 - display_width/2, display_offset_y, case_height - display_recess]) {
            cube([display_width, display_length, display_recess + 1]);
        }
        
        // Rotary encoder hole
        translate([case_width/2, display_offset_y + display_length + encoder_offset_y, -1]) {
            cylinder(d=encoder_hole, h=case_height + 2);
        }
        
        // Button holes
        button_positions();
        
        // Snap-fit receptacles
        snap_fit_holes();
    }
    
    // Display mounting posts
    display_mounting_posts();
    
    // Encoder mounting ring
    encoder_mounting_ring();
}

// =====================================================
// BOTTOM SHELL (Back with component mounts)
// =====================================================

module bottom_shell() {
    difference() {
        // Main shell body
        shell_body();
        
        // USB-C cutout
        translate([case_width/2 - usb_width/2, -1, case_height - usb_height - 2]) {
            cube([usb_width, wall_thickness + 2, usb_height]);
        }
        
        // Ventilation holes
        ventilation_holes();
        
        // Component cavity
        translate([wall_thickness, wall_thickness, wall_thickness]) {
            cube([case_width - 2*wall_thickness, case_length - 2*wall_thickness, case_height]);
        }
    }
    
    // ESP32-S3 mounting channel
    esp32_mount();
    
    // Snap-fit tabs
    snap_fit_tabs();
    
    // Alignment posts
    alignment_posts();
}

// =====================================================
// BASIC SHELL SHAPE
// =====================================================

module shell_body() {
    // Rounded rectangle shell
    hull() {
        translate([5, 5, 0]) cylinder(r=5, h=case_height);
        translate([case_width-5, 5, 0]) cylinder(r=5, h=case_height);
        translate([5, case_length-5, 0]) cylinder(r=5, h=case_height);
        translate([case_width-5, case_length-5, 0]) cylinder(r=5, h=case_height);
    }
}

// =====================================================
// DISPLAY MOUNTING
// =====================================================

module display_mounting_posts() {
    // 4 mounting posts for M2.5 screws
    post_positions = [
        [case_width/2 - 25, display_offset_y + 5],
        [case_width/2 + 25, display_offset_y + 5],
        [case_width/2 - 25, display_offset_y + display_length - 5],
        [case_width/2 + 25, display_offset_y + display_length - 5]
    ];
    
    for (pos = post_positions) {
        translate([pos[0], pos[1], wall_thickness]) {
            difference() {
                cylinder(d=4.5, h=4);
                cylinder(d=2, h=5); // M2.5 hole
            }
        }
    }
}

// =====================================================
// ROTARY ENCODER MOUNTING
// =====================================================

module encoder_mounting_ring() {
    translate([case_width/2, display_offset_y + display_length + encoder_offset_y, wall_thickness]) {
        difference() {
            cylinder(d=encoder_diameter, h=1);
            cylinder(d=encoder_hole, h=2);
        }
    }
}

// =====================================================
// BUTTON POSITIONS
// =====================================================

module button_positions() {
    encoder_center_x = case_width/2;
    encoder_center_y = display_offset_y + display_length + encoder_offset_y;
    
    // Menu button (top-left)
    translate([encoder_center_x - button_spacing, encoder_center_y - button_spacing, -1]) {
        cylinder(d=button_diameter, h=case_height + 2);
    }
    
    // Play button (top-right)
    translate([encoder_center_x + button_spacing, encoder_center_y - button_spacing, -1]) {
        cylinder(d=button_diameter, h=case_height + 2);
    }
    
    // Previous button (left)
    translate([encoder_center_x - button_spacing*1.3, encoder_center_y, -1]) {
        cylinder(d=button_diameter, h=case_height + 2);
    }
    
    // Next button (right)
    translate([encoder_center_x + button_spacing*1.3, encoder_center_y, -1]) {
        cylinder(d=button_diameter, h=case_height + 2);
    }
}

// =====================================================
// ESP32-S3 MOUNTING
// =====================================================

module esp32_mount() {
    // Friction fit channel for ESP32-S3
    translate([case_width/2 - esp32_width/2 - 1, case_length - esp32_length - 10, wall_thickness]) {
        difference() {
            cube([esp32_width + 2, esp32_length + 2, esp32_height/2]);
            translate([1, 1, -1]) {
                cube([esp32_width, esp32_length, esp32_height/2 + 2]);
            }
        }
    }
}

// =====================================================
// SNAP-FIT MECHANISM
// =====================================================

module snap_fit_tabs() {
    // 4 snap-fit tabs around perimeter
    tab_positions = [
        [case_width/2, 5, 0],
        [case_width/2, case_length-5, 0],
        [5, case_length/2, 90],
        [case_width-5, case_length/2, 90]
    ];
    
    for (pos = tab_positions) {
        translate([pos[0], pos[1], case_height/2]) {
            rotate([0, 0, pos[2]]) {
                snap_fit_tab();
            }
        }
    }
}

module snap_fit_tab() {
    translate([0, 0, 0]) {
        cube([8, 1, 4], center=true);
        translate([0, 1.5, 0]) {
            cube([6, 1, 3], center=true);
        }
    }
}

module snap_fit_holes() {
    // Corresponding holes for snap-fit tabs
    tab_positions = [
        [case_width/2, 5, 0],
        [case_width/2, case_length-5, 0],
        [5, case_length/2, 90],
        [case_width-5, case_length/2, 90]
    ];
    
    for (pos = tab_positions) {
        translate([pos[0], pos[1], case_height/2 - 2]) {
            rotate([0, 0, pos[2]]) {
                cube([10, 3, 6], center=true);
            }
        }
    }
}

// =====================================================
// ALIGNMENT POSTS
// =====================================================

module alignment_posts() {
    // 2 alignment posts to prevent misalignment
    translate([15, 15, case_height - 5]) {
        cylinder(d=3, h=5);
    }
    translate([case_width-15, case_length-15, case_height - 5]) {
        cylinder(d=3, h=5);
    }
}

// =====================================================
// VENTILATION
// =====================================================

module ventilation_holes() {
    // 4 ventilation holes in back panel
    hole_positions = [
        [15, case_length - 15],
        [case_width - 15, case_length - 15],
        [15, case_length - 35],
        [case_width - 15, case_length - 35]
    ];
    
    for (pos = hole_positions) {
        translate([pos[0], pos[1], -1]) {
            cylinder(d=3, h=wall_thickness + 2);
        }
    }
}

// =====================================================
// UTILITY FUNCTIONS
// =====================================================

// Rounded cube
module rounded_cube(size, radius) {
    hull() {
        translate([radius, radius, 0]) 
            cylinder(r=radius, h=size[2]);
        translate([size[0]-radius, radius, 0]) 
            cylinder(r=radius, h=size[2]);
        translate([radius, size[1]-radius, 0]) 
            cylinder(r=radius, h=size[2]);
        translate([size[0]-radius, size[1]-radius, 0]) 
            cylinder(r=radius, h=size[2]);
    }
}

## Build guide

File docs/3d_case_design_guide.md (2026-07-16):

# ESP32-S3 iPod Case - 3D Design Guide

## 📐 **Component Measurements & Specifications**

### **ESP32-S3 DevKit Dimensions:**
```
Length: 55.0mm
Width:  25.5mm  
Height: 8.0mm (without headers)
Height: 15.0mm (with headers soldered)

USB-C Port: 
- Width: 8.5mm
- Height: 3.2mm
- Position: Center of short edge

Mounting Holes: None (use friction fit or clips)
```

### **MSP2806 Display (2.8" ILI9341) Dimensions:**
```
PCB Size:
Length: 56.0mm
Width:  40.0mm
Height: 3.2mm (PCB only)
Height: 8.5mm (with components)

Display Area:
Length: 49.0mm
Width:  36.8mm
Diagonal: 2.8" (71.1mm)

Mounting Holes: 4x M2.5 holes
- Hole spacing: 50.0mm x 34.0mm
- Hole diameter: 2.5mm
- Corner radius from PCB edge: 3.0mm
```

### **KY-040 Rotary Encoder Dimensions:**
```
PCB Size:
Length: 26.0mm
Width:  18.0mm
Height: 15.0mm (with knob)

Shaft:
Diameter: 6.0mm
Length: 15.0mm (protruding)
Knob diameter: 15.0mm

Mounting: 2x M3 holes or friction fit
```

### **Tactile Push Buttons (6x6x5mm):**
```
Body: 6.0mm x 6.0mm x 5.0mm
Button cap: 3.5mm diameter
Travel: 0.25mm
Mounting: Through-hole or surface mount
```

## 🎨 **iPod-Inspired Case Design**

### **Overall Case Dimensions:**
```
External Dimensions:
Length: 110.0mm (classic iPod proportions)
Width:  65.0mm
Depth:  18.0mm

Internal Cavity:
Length: 106.0mm
Width:  61.0mm  
Depth:  15.0mm

Wall Thickness: 2.0mm (minimum for 3D printing)
```

### **Front Panel Layout:**
```
Display Window:
- Position: Centered, 15mm from top
- Size: 52.0mm x 39.0mm (2mm margin around display)
- Depth: 1.0mm recess for flush mounting

Haptic Button Layout:
- Menu: Top-left, 20mm from display (6x6mm tactile)
- Play: Top-right, 20mm from display (6x6mm tactile)  
- Prev: Bottom-left, 15mm from bottom (6x6mm tactile)
- Next: Bottom-right, 15mm from bottom (6x6mm tactile)
- Button holes: 4.0mm diameter with 0.5mm chamfer

LRA Mounting Area:
- Position: Center bottom, between Prev/Next buttons
- Recess: 12mm diameter x 5mm deep
- Isolation: Foam padding around perimeter
- Access: Small hole for wire routing
```

### **Back Panel:**
```
ESP32-S3 Access:
- USB-C cutout: 10.0mm x 4.5mm
- Position: Top edge, centered
- Programming access window: 30mm x 15mm (optional)

Ventilation:
- 4x 3mm holes for airflow
- Positioned away from components

Text/Branding Area:
- 40mm x 20mm flat area for labels
- Position: Lower back panel
```

## 🔧 **3D Modeling Specifications**

### **Fusion 360 / SolidWorks Parameters:**
```
Units: Millimeters (mm)
Tolerance: ±0.2mm for fit parts
Print Resolution: 0.2mm layer height
Infill: 20% minimum
Support: Required for overhangs >45°
```

### **Key Design Features:**

#### **1. Two-Part Shell Design:**
```
Top Shell (Front):
- Display window with 1mm recess
- Button holes with 0.5mm chamfer
- Encoder hole with retention ring
- Snap-fit tabs (4x around perimeter)

Bottom Shell (Back):
- Component mounting posts
- USB-C access cutout
- Ventilation holes
- Snap-fit receptacles
```

#### **2. Component Mounting System:**
```
ESP32-S3 Mount:
- Friction fit channel: 26.0mm x 56.0mm x 9.0mm
- Side walls: 1.5mm thick
- Entry chamfer: 45° x 1mm

Display Mount:
- 4x M2.5 mounting posts
- Post height: 4.0mm
- Post diameter: 4.5mm (outer), 2.0mm (inner)
- Countersink: 1.0mm for screw heads

DRV2605L Mount:
- PCB recess: 20.0mm x 15.0mm x 2.0mm deep
- Snap-fit clips: 2x flexible tabs
- Wire routing channel: 3.0mm wide

LRA Mount:
- Circular recess: 12.0mm diameter x 5.0mm deep
- Isolation ring: Foam padding groove
- Wire channel: 2.0mm diameter to DRV2605L
- Vibration isolation: Suspended mounting

Button Mounts:
- Through-holes: 4.0mm diameter
- Countersink: 6.5mm diameter x 1.0mm deep
- Internal clearance: 8.0mm x 8.0mm x 6.0mm
- Tactile feedback: Direct contact with case
```

#### **3. Assembly Features:**
```
Snap-Fit Tabs:
- Tab width: 8.0mm
- Tab thickness: 1.0mm
- Deflection: 2.0mm
- Retention force: ~5N

Alignment Posts:
- 2x cylindrical posts: 3.0mm diameter x 5.0mm height
- Matching holes in opposite shell
- Prevents misalignment during assembly

Cable Management:
- Internal channels: 3.0mm wide x 2.0mm deep
- Rounded corners: 1.0mm radius
- Strain relief for USB cable
```

## 📏 **Detailed Technical Drawings**

### **Front View (Top Shell):**
```
    ┌─────────────────────────────────────────────────────────────┐
    │                         65.0mm                              │
    │  ┌─────────────────────────────────────────────────────┐    │
    │  │                                                     │    │ 15.0mm
    │  │              Display Window                         │    │
    │  │              52.0 x 39.0mm                         │    │
    │  │                                                     │    │
    │  └─────────────────────────────────────────────────────┘    │
    │                                                             │
    │           ○ Menu                    Play ○                  │ 20.0mm
    │                                                             │
    │                                                             │
    │      ○ Prev        [LRA Mount]         Next ○              │ 15.0mm
    │                   (12mm recess)                            │
    │                                                             │
    └─────────────────────────────────────────────────────────────┘
                              110.0mm
```

### **Side View (Cross-Section):**
```
    ┌─────────────────────────────────────────────────────────────┐
    │  Display (8.5mm)                                           │ 2.0mm
    │  ┌─────────────┐                                           │
    │  │             │    ESP32-S3 (15.0mm)                      │
    │  │             │    ┌─────────────┐                        │
    │  │             │    │             │                        │ 15.0mm
    │  │             │    │             │                        │
    │  │             │    │             │                        │
    │  └─────────────┘    └─────────────┘                        │
    └─────────────────────────────────────────────────────────────┘ 2.0mm
                              110.0mm                    Total: 18.0mm
```

### **Back View (Bottom Shell):**
```
    ┌─────────────────────────────────────────────────────────────┐
    │                    USB-C Cutout                            │
    │                   ┌─────────────┐                          │
    │                   │  10x4.5mm   │                          │
    │                   └─────────────┘                          │
    │                                                             │
    │  ○     ESP32-S3 Programming Access     ○                   │
    │        (Optional 30x15mm window)                           │
    │                                                             │
    │                                                             │
    │  ○           Ventilation Holes          ○                  │
    │              (4x 3mm diameter)                             │
    │                                                             │
    │                   iPod ESP32-S3                            │
    │                  Custom Build v1.0                         │
    └─────────────────────────────────────────────────────────────┘
```

## 🖨️ **3D Printing Guidelines**

### **Print Settings:**
```
Layer Height: 0.2mm (0.15mm for fine details)
Infill: 20% (gyroid or cubic)
Print Speed: 50mm/s (30mm/s for first layer)
Nozzle Temperature: 210°C (PLA) / 240°C (PETG)
Bed Temperature: 60°C (PLA) / 80°C (PETG)
```

### **Support Requirements:**
```
Top Shell:
- Supports needed for button holes
- Support angle: 45°
- Support density: 15%

Bottom Shell:
- Supports for mounting posts
- Minimal supports for USB cutout
- Support interface: 0.2mm gap
```

### **Post-Processing:**
```
1. Remove supports carefully
2. Test-fit all components before assembly
3. Light sanding on snap-fit tabs if tight
4. Drill out holes if undersized:
   - Display mounting: 2.5mm drill
   - Encoder shaft: 7.0mm drill
   - Button holes: 4.0mm drill
```

## 📦 **Assembly Instructions**

### **Component Installation Order:**
```
1. Install ESP32-S3 in bottom shell
2. Route wires through internal channels
3. Mount display to top shell with M2.5 screws
4. Install rotary encoder (friction fit or screws)
5. Install tactile buttons in holes
6. Connect all wiring
7. Test functionality
8. Snap shells together
```

### **Hardware Required:**
```
- 4x M2.5 x 8mm screws (display mounting)
- 2x M3 x 6mm screws (encoder mounting, optional)
- Heat-set inserts (optional, for removable assembly)
```

## 🎨 **Design Variations**

### **Classic iPod Style:**
- Rounded corners (5mm radius)
- White or silver finish
- Minimalist button layout
- Apple-inspired proportions

### **Modern Style:**
- Sharp edges
- Black matte finish
- LED-illuminated buttons
- USB-C visible on side

### **Retro Style:**
- Thick bezels
- Textured surface
- Vintage color schemes
- Physical volume wheel

## 📁 **File Formats to Export**

### **For 3D Printing:**
```
- STL files (high resolution, 0.1mm tolerance)
- 3MF files (with print settings embedded)
```

### **For Sharing/Modification:**
```
- STEP files (universal CAD format)
- Fusion 360 .f3d files
- SolidWorks .sldprt files
```

### **For Documentation:**
```
- Technical drawings (PDF)
- Assembly instructions (PDF with images)
- Bill of materials (Excel/CSV)
```

## 🔧 **Design Tips**

### **For Beginners:**
1. **Start simple** - Basic rectangular case first
2. **Test fit frequently** - Print small test pieces
3. **Add tolerances** - Components should slide in easily
4. **Consider assembly** - How will you put it together?

### **Advanced Features:**
1. **Heat-set inserts** - For removable assembly
2. **Living hinges** - For flip-open design
3. **Gaskets** - For water resistance
4. **Light pipes** - For LED indicators

This comprehensive guide gives you everything needed to create a professional-looking iPod case! The measurements are based on standard component sizes and proven 3D printing practices. 🎯

Would you like me to create specific CAD files or focus on any particular aspect of the design?

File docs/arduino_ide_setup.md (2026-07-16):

# Arduino IDE Setup for ESP32-S3 iPod

## Step 1: Install ESP32 Board Package

### 1.1 Add ESP32 Board Manager URL
1. Open Arduino IDE
2. Go to **File → Preferences**
3. In "Additional Board Manager URLs", add:
   ```
   https://espressif.github.io/arduino-esp32/package_esp32_index.json
   ```
4. Click **OK**

### 1.2 Install ESP32 Boards
1. Go to **Tools → Board → Boards Manager**
2. Search for "ESP32"
3. Install **"esp32" by Espressif Systems** (latest version)
4. Wait for installation to complete

### 1.3 Select Your Board
1. Go to **Tools → Board → ESP32 Arduino**
2. Select **"ESP32S3 Dev Module"**
3. Configure board settings:
   - **CPU Frequency**: 240MHz
   - **Flash Mode**: QIO
   - **Flash Size**: 16MB
   - **Partition Scheme**: Huge APP (3MB No OTA/1MB SPIFFS)
   - **PSRAM**: Enabled

## Step 2: Install Required Libraries

### 2.1 Open Library Manager
1. Go to **Tools → Manage Libraries**
2. Search and install each library below

### 2.2 Install These Libraries (in order):

#### **Library 1: Adafruit BusIO**
- Search: "Adafruit BusIO"
- Install: **"Adafruit BusIO" by Adafruit**
- Version: Latest

#### **Library 2: Adafruit GFX Library**
- Search: "Adafruit GFX"
- Install: **"Adafruit GFX Library" by Adafruit**
- Version: Latest

#### **Library 3: Adafruit ILI9341**
- Search: "Adafruit ILI9341"
- Install: **"Adafruit ILI9341" by Adafruit**
- Version: Latest

#### **Library 4: XPT2046 Touchscreen**
- Search: "XPT2046"
- Install: **"XPT2046_Touchscreen" by Paul Stoffregen**
- Version: Latest

### 2.3 Verify Installation
After installing, you should see these in **Sketch → Include Library**:
- ✅ Adafruit GFX Library
- ✅ Adafruit ILI9341
- ✅ XPT2046_Touchscreen
- ✅ Adafruit BusIO

## Step 3: Upload Test Code

### 3.1 Create New Sketch
1. **File → New** (create new sketch)
2. Copy the contents of `src/arduino_display_test.cpp`
3. Paste into the Arduino IDE
4. **File → Save As** → Name it "ESP32_iPod_Test"

### 3.2 Connect ESP32-S3
1. Connect ESP32-S3 to computer via USB-C cable
2. **Tools → Port** → Select your ESP32 port (usually `/dev/cu.usbmodem...` on Mac)

### 3.3 Upload Code
1. Click **Upload** button (→)
2. If upload fails, hold **BOOT** button on ESP32-S3 while clicking upload
3. Wait for "Done uploading" message

### 3.4 Open Serial Monitor
1. **Tools → Serial Monitor**
2. Set baud rate to **115200**
3. You should see initialization messages

## Step 4: Wiring Your Display

### 4.1 Power Off ESP32-S3
Disconnect USB cable before wiring

### 4.2 Connect Display to ESP32-S3
```
ESP32-S3    →    MSP2806 Display
GPIO10      →    CS
GPIO9       →    DC
GPIO8       →    RST
GPIO11      →    SDA/MOSI
GPIO12      →    SCL/SCLK
GPIO13      →    SDO/MISO (optional)
GPIO6       →    T_CS
GPIO7       →    T_CLK
GPIO5       →    T_DIN
GPIO4       →    T_DO
GPIO3       →    T_IRQ (optional)
3.3V        →    VCC
3.3V        →    LED (backlight)
GND         →    GND
```

### 4.3 Double-Check Connections
- **Power**: 3.3V and GND connected
- **Display SPI**: CS, DC, RST, MOSI, SCLK
- **Touch SPI**: T_CS, T_CLK, T_DIN, T_DO

## Step 5: Test Your Setup

### 5.1 Power On
1. Reconnect USB cable
2. ESP32-S3 should boot
3. Display backlight should turn on

### 5.2 Expected Results
**Serial Monitor should show:**
```
=== ESP32-S3 iPod Display Test ===
MSP2806 - 2.8" ILI9341 + Touch

Wiring Check:
ESP32-S3 → MSP2806
...

Initializing display...
Display initialized!
Initializing touch...
Touch initialized!
Running display tests...
```

**Display should show:**
1. **Color screens**: Black → Red → Green → Blue
2. **Text**: "ESP32-S3 iPod Test" with status messages
3. **Shapes**: Rectangles, circles, lines
4. **Color bars**: 6 colored vertical bars
5. **iPod interface**: Mock music player interface

### 5.3 Touch Test
- Touch anywhere on screen
- Should see red circles where you touch
- Serial Monitor shows touch coordinates

## 🚨 Troubleshooting

### Issue 1: Upload Failed
```
Failed to connect to ESP32-S3
```
**Solutions:**
- Hold **BOOT** button while clicking upload
- Try different USB cable (data cable, not charge-only)
- Check port selection in Tools → Port

### Issue 2: Library Not Found
```
fatal error: Adafruit_ILI9341.h: No such file or directory
```
**Solutions:**
- Install libraries via Library Manager (Step 2)
- Restart Arduino IDE after installing
- Check library installation in Sketch → Include Library

### Issue 3: White Screen Only
```
Display shows backlight but no content
```
**Solutions:**
- Check wiring connections
- Verify 3.3V power supply
- Try different jumper wires
- Check breadboard connections

### Issue 4: Compilation Errors
```
Multiple definition errors
```
**Solutions:**
- Use only one .cpp file at a time
- Don't mix Arduino IDE with PlatformIO files
- Create fresh sketch with only the test code

### Issue 5: Touch Not Working
```
Touch coordinates not showing
```
**Solutions:**
- Check touch wiring (T_CS, T_CLK, T_DIN, T_DO)
- Verify XPT2046_Touchscreen library installed
- Try touching different areas of screen

## 📋 Quick Checklist

Before asking for help, verify:
- ✅ ESP32 board package installed
- ✅ All 4 libraries installed via Library Manager
- ✅ Board set to "ESP32S3 Dev Module"
- ✅ Port selected correctly
- ✅ All wiring connections secure
- ✅ 3.3V power connected to VCC and LED
- ✅ GND connected properly
- ✅ Serial Monitor at 115200 baud

## 🎯 Success Indicators

**You're ready for the next step when:**
- Display shows colors and text clearly
- Touch responds with red circles
- Serial Monitor shows "All tests complete!"
- No compilation or upload errors

Once this basic test works, you can move on to the full iPod software!

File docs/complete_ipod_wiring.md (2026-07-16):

# 🎵 Complete iPod Wiring Guide
## ESP32-S3 + Display + TTP229 + SD Card + Audio + Battery

---

## 📦 **Components You Need**

1. **ESP32-S3-N16R8** DevKit
2. **MSP2806 Display** (2.8" ILI9341)
3. **TTP229 16-Key Touch Module**
4. **SD Card Module** (SPI)
5. **PCM5102 DAC Module** (I2S audio)
6. **TP4056 USB-C Charging Module**
7. **3.7V LiPo Battery** (2000-3000mAh)
8. **3.5mm Headphone Jack**
9. **Jumper wires**

---

## 🔌 **Complete Pin Mapping**

### **Power Distribution**
```
TP4056 Module:
  USB-C Input → Charging
  B+ → Battery Positive
  B- → Battery Negative
  OUT+ → ESP32 5V/VIN
  OUT- → Common GND

Battery:
  3.7V LiPo (2000mAh+)
  Red → TP4056 B+
  Black → TP4056 B-
```

### **ESP32-S3 Connections**

#### **Display (MSP2806) - SPI**
```
Display Pin    ESP32-S3 Pin    Function
-----------    ------------    --------
VCC            3.3V            Power
GND            GND             Ground
CS             GPIO10          Chip Select
RST            GPIO8           Reset
DC             GPIO9           Data/Command
SDA/MOSI       GPIO11          SPI Data Out
SCL/SCLK       GPIO12          SPI Clock
SDO/MISO       GPIO13          SPI Data In
LED            3.3V            Backlight
```

#### **TTP229 Touch - Serial Mode**
```
TTP229 Pin     ESP32-S3 Pin    Function
----------     ------------    --------
VCC            3.3V            Power
GND            GND             Ground
SCL            GPIO2           Clock
SDO            GPIO1           Data
```

#### **SD Card Module - SPI (Shared with Display)**
```
SD Card Pin    ESP32-S3 Pin    Function
-----------    ------------    --------
VCC            3.3V            Power
GND            GND             Ground
CS             GPIO5           Chip Select
MOSI           GPIO11          SPI Data Out (shared)
SCK            GPIO12          SPI Clock (shared)
MISO           GPIO13          SPI Data In (shared)
```

#### **PCM5102 DAC - I2S Audio**
```
PCM5102 Pin    ESP32-S3 Pin    Function
-----------    ------------    --------
VCC            3.3V            Power
GND            GND             Ground
BCK            GPIO4           Bit Clock
DIN            GPIO3           Data In
LCK            GPIO6           Left/Right Clock
SCK            GND             System Clock (tie to GND)
FMT            GND             Format (I2S mode)
XMT            3.3V            Mute control (HIGH = unmuted)
```

#### **Headphone Jack**
```
PCM5102 → 3.5mm Jack:
  LOUT → Left Channel (Tip)
  ROUT → Right Channel (Ring)
  GND  → Ground (Sleeve)
```

---

## 📊 **GPIO Pin Summary**

```
ESP32-S3 Pin Usage:
━━━━━━━━━━━━━━━━━━━━━━━━━━━━━━━━━━━━━━━━━━━━
GPIO1  - TTP229 SDO (Touch Data)
GPIO2  - TTP229 SCL (Touch Clock)
GPIO3  - PCM5102 DIN (Audio Data)
GPIO4  - PCM5102 BCK (Audio Bit Clock)
GPIO5  - SD Card CS (Chip Select)
GPIO6  - PCM5102 LCK (Audio L/R Clock)
GPIO8  - Display RST (Reset)
GPIO9  - Display DC (Data/Command)
GPIO10 - Display CS (Chip Select)
GPIO11 - SPI MOSI (Display + SD Card)
GPIO12 - SPI SCK (Display + SD Card)
GPIO13 - SPI MISO (Display + SD Card)
━━━━━━━━━━━━━━━━━━━━━━━━━━━━━━━━━━━━━━━━━━━━
Total: 13 GPIO pins used
```

---

## 🎨 **Visual Wiring Diagram**

```
                    ┌─────────────────────────────────┐
                    │       ESP32-S3 DevKit           │
                    │                                 │
    ┌───────────────┤ 3.3V (multiple connections)    │
    │               │ GND  (common ground)            │
    │               │                                 │
    │               │ GPIO1  ←─────────────────────┐  │
    │               │ GPIO2  ←───────────────────┐ │  │
    │               │ GPIO3  ─────────────────┐  │ │  │
    │               │ GPIO4  ───────────────┐ │  │ │  │
    │               │ GPIO5  ─────────────┐ │ │  │ │  │
    │               │ GPIO6  ───────────┐ │ │ │  │ │  │
    │               │ GPIO8  ─────────┐ │ │ │ │  │ │  │
    │               │ GPIO9  ───────┐ │ │ │ │ │  │ │  │
    │               │ GPIO10 ─────┐ │ │ │ │ │ │  │ │  │
    │               │ GPIO11 ───┐ │ │ │ │ │ │ │  │ │  │
    │               │ GPIO12 ─┐ │ │ │ │ │ │ │ │  │ │  │
    │               │ GPIO13 ┐│ │ │ │ │ │ │ │ │  │ │  │
    │               │        ││ │ │ │ │ │ │ │ │  │ │  │
    │               │ VIN ←──┼┼─┼─┼─┼─┼─┼─┼─┼─┼──┼─┼──┤
    │               └────────┼┼─┼─┼─┼─┼─┼─┼─┼─┼──┼─┼──┘
    │                        ││ │ │ │ │ │ │ │ │  │ │
    │  ┌─────────────────────┼┼─┼─┼─┼─┼─┼─┼─┼─┼──┘ │
    │  │  ┌──────────────────┼┼─┼─┼─┼─┼─┼─┼─┼─┘    │
    │  │  │  ┌───────────────┼┼─┼─┼─┼─┼─┼─┼─┘      │
    │  │  │  │  ┌────────────┼┼─┼─┼─┼─┼─┼─┘        │
    │  │  │  │  │  ┌─────────┼┼─┼─┼─┼─┼─┘          │
    │  │  │  │  │  │  ┌──────┼┼─┼─┼─┼─┘            │
    │  │  │  │  │  │  │  ┌───┼┼─┼─┼─┘              │
    │  │  │  │  │  │  │  │   ││ │ │                │
    │  │  │  │  │  │  │  │   ││ │ │                │
    ▼  ▼  ▼  ▼  ▼  ▼  ▼  ▼   ▼▼ ▼ ▼                ▼
┌──────────────────────┐  ┌──────────┐  ┌────────────────┐
│   MSP2806 Display    │  │ SD Card  │  │   TTP229 Touch │
│   (2.8" ILI9341)     │  │  Module  │  │   16-Key Pad   │
├──────────────────────┤  ├──────────┤  ├────────────────┤
│ VCC  GND  CS  RST DC │  │VCC GND CS│  │ VCC GND SCL SDO│
│ MOSI SCK MISO LED    │  │MOSI SCK  │  └────────────────┘
└──────────────────────┘  │MISO      │
                          └──────────┘

         ┌──────────────────────────┐
         │   PCM5102 DAC Module     │
         ├──────────────────────────┤
         │ VCC GND BCK DIN LCK      │
         │ SCK FMT XMT LOUT ROUT    │
         └──────────────────────────┘
                    │
                    ▼
         ┌──────────────────────────┐
         │   3.5mm Headphone Jack   │
         │   Tip Ring Sleeve        │
         └──────────────────────────┘

┌────────────────────────────────────────┐
│         Power System                   │
├────────────────────────────────────────┤
│  USB-C → [TP4056] → Battery (3.7V)    │
│              ↓                         │
│          OUT+ OUT-                     │
│              ↓                         │
│          ESP32 VIN                     │
└────────────────────────────────────────┘
```

---

## 🔧 **Step-by-Step Wiring**

### **Step 1: Power System**
```
1. Connect battery to TP4056:
   Battery Red → TP4056 B+
   Battery Black → TP4056 B-

2. Connect TP4056 to ESP32:
   TP4056 OUT+ → ESP32 VIN (or 5V)
   TP4056 OUT- → ESP32 GND

3. Create common ground rail on breadboard
   Connect all GND pins together
```

### **Step 2: Display (Already Working)**
```
Display → ESP32-S3:
  VCC → 3.3V
  GND → GND
  CS → GPIO10
  RST → GPIO8
  DC → GPIO9
  MOSI → GPIO11
  SCK → GPIO12
  MISO → GPIO13
  LED → 3.3V
```

### **Step 3: TTP229 Touch (Already Working)**
```
TTP229 → ESP32-S3:
  VCC → 3.3V
  GND → GND
  SCL → GPIO2
  SDO → GPIO1
```

### **Step 4: SD Card Module**
```
SD Card → ESP32-S3:
  VCC → 3.3V
  GND → GND
  CS → GPIO5
  MOSI → GPIO11 (shared with display)
  SCK → GPIO12 (shared with display)
  MISO → GPIO13 (shared with display)
```

### **Step 5: PCM5102 DAC**
```
PCM5102 → ESP32-S3:
  VCC → 3.3V
  GND → GND
  BCK → GPIO4
  DIN → GPIO3
  LCK → GPIO6
  SCK → GND (tie to ground)
  FMT → GND (I2S mode)
  XMT → 3.3V (unmute)

PCM5102 → Headphone Jack:
  LOUT → Jack Tip (Left)
  ROUT → Jack Ring (Right)
  GND → Jack Sleeve (Ground)
```

---

## ⚠️ **Important Notes**

### **SPI Bus Sharing**
The display and SD card share the same SPI bus (MOSI, SCK, MISO). They use different CS pins:
- Display CS: GPIO10
- SD Card CS: GPIO5

This is normal and works perfectly!

### **Power Considerations**
```
Component Power Draw:
- ESP32-S3: ~80-240mA (WiFi active)
- Display: ~100mA (backlight on)
- SD Card: ~50-100mA (reading)
- DAC: ~10mA
- TTP229: ~3mA
━━━━━━━━━━━━━━━━━━━━━━━━━━━━━━━
Total: ~250-450mA typical

Recommended Battery: 2000-3000mAh
Battery Life: 4-8 hours
```

### **PCM5102 Configuration**
The PCM5102 has configuration pins:
- **SCK → GND**: Use ESP32 as master clock
- **FMT → GND**: I2S format (not left-justified)
- **XMT → 3.3V**: Unmute (always on)

Some PCM5102 modules have these pre-configured with solder bridges on the back.

---

## 💻 **Code Configuration**

Update `src/config.h`:

```cpp
// Display pins (already configured)
#define TFT_CS   10
#define TFT_RST  8
#define TFT_DC   9
#define TFT_MOSI 11
#define TFT_SCLK 12
#define TFT_MISO 13

// TTP229 Touch pins (already configured)
#define TTP_SDO  1
#define TTP_SCL  2

// SD Card pins
#define SD_CS    5
#define SD_MOSI  11  // Shared with display
#define SD_SCK   12  // Shared with display
#define SD_MISO  13  // Shared with display

// I2S Audio pins (PCM5102)
#define I2S_BCLK 4   // Bit clock
#define I2S_LRC  6   // Left/Right clock
#define I2S_DOUT 3   // Data out

// Battery monitoring (optional)
#define BATTERY_PIN 7  // ADC pin for voltage monitoring
```

---

## 🧪 **Testing Each Component**

### **1. Test SD Card**
```cpp
#include <SD.h>
#include <SPI.h>

void setup() {
  Serial.begin(115200);
  
  if (!SD.begin(5)) {  // GPIO5 = CS
    Serial.println("SD Card failed!");
    return;
  }
  
  Serial.println("SD Card OK!");
  Serial.print("Size: ");
  Serial.print(SD.cardSize() / 1024 / 1024);
  Serial.println(" MB");
}
```

### **2. Test Audio (I2S)**
```cpp
#include "driver/i2s.h"

void setup() {
  i2s_config_t i2s_config = {
    .mode = (i2s_mode_t)(I2S_MODE_MASTER | I2S_MODE_TX),
    .sample_rate = 44100,
    .bits_per_sample = I2S_BITS_PER_SAMPLE_16BIT,
    .channel_format = I2S_CHANNEL_FMT_RIGHT_LEFT,
    .communication_format = I2S_COMM_FORMAT_I2S,
    .intr_alloc_flags = ESP_INTR_FLAG_LEVEL1,
    .dma_buf_count = 8,
    .dma_buf_len = 64
  };
  
  i2s_pin_config_t pin_config = {
    .bck_io_num = 4,    // BCK
    .ws_io_num = 6,     // LRC
    .data_out_num = 3,  // DIN
    .data_in_num = -1
  };
  
  i2s_driver_install(I2S_NUM_0, &i2s_config, 0, NULL);
  i2s_set_pin(I2S_NUM_0, &pin_config);
  
  Serial.println("I2S Audio initialized!");
}
```

---

## 📝 **Shopping List (India)**

```
Component              Price (₹)    Link/Store
━━━━━━━━━━━━━━━━━━━━━━━━━━━━━━━━━━━━━━━━━━━━━━━━━━━━
ESP32-S3-N16R8         800-1200     Robu.in, Amazon
MSP2806 Display        400-600      Already have
TTP229 16-Key          300-400      Already have
SD Card Module         50-100       Robu.in, local
PCM5102 DAC            300-500      Robu.in, Amazon
TP4056 USB-C           14-50        Already have
3.7V LiPo 2500mAh      300-500      Robu.in, Amazon
3.5mm Jack             10-20        Local electronics
Jumper Wires (40pcs)   50-100       Local/Amazon
━━━━━━━━━━━━━━━━━━━━━━━━━━━━━━━━━━━━━━━━━━━━━━━━━━━━
Total (new items):     ~₹700-1200
```

---

## 🎯 **Final Checklist**

Before powering on:

**Power:**
- [ ] Battery connected to TP4056 (correct polarity!)
- [ ] TP4056 OUT+ to ESP32 VIN
- [ ] All GND connected together

**Display:**
- [ ] All 9 wires connected
- [ ] CS on GPIO10

**Touch:**
- [ ] SCL on GPIO2
- [ ] SDO on GPIO1

**SD Card:**
- [ ] CS on GPIO5
- [ ] MOSI/SCK/MISO shared with display

**Audio:**
- [ ] BCK on GPIO4
- [ ] DIN on GPIO3
- [ ] LCK on GPIO6
- [ ] SCK tied to GND
- [ ] FMT tied to GND
- [ ] XMT tied to 3.3V

**Safety:**
- [ ] No short circuits
- [ ] Battery polarity correct
- [ ] All connections secure

---

## 🚀 **You're Ready!**

You now have a complete iPod with:
- ✅ Touch gesture control (16 keys)
- ✅ Color display
- ✅ SD card for music storage
- ✅ High-quality audio output
- ✅ Rechargeable battery
- ✅ USB-C charging

Enjoy your custom iPod! 🎵

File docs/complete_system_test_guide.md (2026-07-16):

# 🎵 Complete iPod System Test Guide
## Full Integration: Display + Touch + SD Card + Audio Ready

---

## 📋 **What This Tests**

This is the **complete integrated system** that brings everything together:

✅ **ILI9341 Display** - Full color UI with iPod interface  
✅ **TTP229 16-Key Touch** - Gesture controls and navigation  
✅ **SD Card Module** - Music library scanning and file management  
✅ **Audio System Ready** - I2S output prepared for DAC module  
✅ **Complete UI** - Home, Library, Now Playing, SD Info screens  

---

## 🔌 **Hardware Requirements**

### Components Needed:
1. **ESP32-S3-N16R8** DevKit
2. **MSP2806 Display** (2.8" ILI9341) - Already working
3. **TTP229 16-Key Touch Module** - Already working
4. **MicroSD Card Module** - Your new module
5. **16GB MicroSD Card** - Formatted as FAT32
6. **Jumper wires**

### Complete Wiring:
```
Display (ILI9341):
  VCC  → 3.3V
  GND  → GND
  CS   → GPIO10
  RST  → GPIO8
  DC   → GPIO9
  MOSI → GPIO11
  SCK  → GPIO12
  MISO → GPIO13
  LED  → 3.3V

TTP229 Touch:
  VCC  → 3.3V
  GND  → GND
  SCL  → GPIO2
  SDO  → GPIO1

SD Card Module:
  VCC  → 3.3V
  GND  → GND
  CS   → GPIO5
  MOSI → GPIO11 (shared with display)
  SCK  → GPIO12 (shared with display)
  MISO → GPIO13 (shared with display)
```

---

## 💾 **SD Card Preparation**

### Step 1: Format Card
```
Format: FAT32
Size: 16GB (or 32GB)
Label: IPOD (optional)
```

**Windows:** Right-click drive → Format → FAT32  
**Mac:** Disk Utility → Erase → MS-DOS (FAT)  
**Linux:** `sudo mkfs.vfat -F 32 /dev/sdX1`

### Step 2: Add Music Files
Create this folder structure:
```
SD Card Root:
├── Music/
│   ├── Artist - Song1.mp3
│   ├── Artist - Song2.mp3
│   └── Artist - Song3.mp3
└── (or any folder structure you like)
```

### Supported Formats:
- ✅ `.mp3` - MP3 audio
- ✅ `.wav` - WAV audio
- ✅ `.flac` - FLAC lossless
- ✅ `.m4a` - AAC audio

### File Naming Tips:
```
Good formats:
- "Artist - Title.mp3"
- "Song Name.mp3"
- "01 - Track Name.mp3"

The system will parse:
- "Queen - Bohemian Rhapsody.mp3"
  → Artist: Queen
  → Title: Bohemian Rhapsody
```

---

## 🚀 **Upload and Test**

### Step 1: Update platformio.ini
Make sure you have the required libraries:
```ini
lib_deps = 
    bodmer/TFT_eSPI@^2.5.43
```

### Step 2: Compile and Upload
```bash
# In PlatformIO
pio run -t upload -t monitor

# Or use the PlatformIO IDE upload button
```

### Step 3: Watch Serial Monitor
You should see:
```
╔════════════════════════════════════════╗
║  Complete iPod System Test            ║
║  Display + Touch + SD + Audio Ready    ║
╚════════════════════════════════════════╝

🔧 Initializing components...

📺 Display... ✅
👆 TTP229 Touch... ✅
💾 SD Card... ✅
   Type: SDHC
   Size: 15360 MB
   Used: 245 MB / 15360 MB

📂 Scanning for music files...
   🎵 Bohemian Rhapsody
   🎵 Stairway to Heaven
   🎵 Hotel California
✅ Found 3 music files

✅ System Ready!
```

---

## 🎮 **Touch Controls**

### 16-Key Layout:
```
┌────┬────┬────┬────┐
│ 1  │ 2  │ 3  │ 4  │
├────┼────┼────┼────┤
│ 5  │ 6  │ 7  │ 8  │
├────┼────┼────┼────┤
│ 9  │ 10 │ 11 │ 12 │
├────┼────┼────┼────┤
│ 13 │ 14 │ 15 │ 16 │
└────┴────┴────┴────┘
```

### Key Functions:
```
Key 1:  Menu/Back
Key 2:  Navigate Up
Key 3:  Volume Up
Key 4:  Play/Pause

Key 6:  Previous Track
Key 7:  Next Track
Key 8:  SD Card Info

Key 10: Navigate Down
Key 11: Select/Enter

Key 15: Volume Down

Long Press (any key): Back to Menu
```

---

## 📱 **UI Screens**

### 1. Home Screen
```
┌─────────────────────────┐
│ iPod        Complete    │
│                         │
│  ► Music Library        │
│    Now Playing          │
│    SD Card Info         │
│                         │
│ Songs: 12               │
│ Vol: 50%                │
│ Key 1:Menu 11:Select    │
└─────────────────────────┘
```

### 2. Music Library
```
┌─────────────────────────┐
│ Library                 │
│ 12 songs                │
├─────────────────────────┤
│ ► Bohemian Rhapsody     │
│   Queen                 │
│   4.2 MB                │
│                         │
│   Stairway to Heaven    │
│   Led Zeppelin          │
│   5.8 MB                │
├─────────────────────────┤
│ 2/10:Nav 11:Play 1:Back │
└─────────────────────────┘
```

### 3. Now Playing
```
┌─────────────────────────┐
│ Now Playing             │
├─────────────────────────┤
│   ┌─────────────┐       │
│   │             │       │
│   │      ♪      │       │
│   │             │       │
│   └─────────────┘       │
│                         │
│ Bohemian Rhapsody       │
│ Queen                   │
│                         │
│ Playing        Vol:50%  │
│ Track 1/12              │
│ 4.2 MB                  │
├─────────────────────────┤
│ 4:Play 6/7:Prev/Next    │
└─────────────────────────┘
```

### 4. SD Card Info
```
┌─────────────────────────┐
│ SD Card                 │
├─────────────────────────┤
│ Card Type:    SDHC      │
│ Total Size:   15360 MB  │
│ Used:         245 MB    │
│ Free:         15115 MB  │
│                         │
│ Usage:                  │
│ ┌──────────────────┐    │
│ │█░░░░░░░░░░░░░░░░│1.6%│
│ └──────────────────┘    │
│                         │
│ Music Files:  12        │
│ Supported:              │
│ .mp3 .wav .flac .m4a    │
├─────────────────────────┤
│ Press 1 for Menu        │
└─────────────────────────┘
```

---

## 🧪 **Testing Checklist**

### Display Test:
- [ ] Splash screen appears
- [ ] Home menu displays
- [ ] Text is readable
- [ ] Colors are correct
- [ ] Screen updates on touch

### Touch Test:
- [ ] Key 2 navigates up
- [ ] Key 10 navigates down
- [ ] Key 11 selects items
- [ ] Key 1 goes back
- [ ] Long press works
- [ ] All 16 keys respond

### SD Card Test:
- [ ] Card detected on boot
- [ ] Card type displayed correctly
- [ ] Size shown accurately
- [ ] Music files found
- [ ] File names parsed correctly
- [ ] Artist/title extracted

### Navigation Test:
- [ ] Can browse library
- [ ] Scrolling works
- [ ] Selection highlights
- [ ] Can enter/exit screens
- [ ] Back button works

### Music Control Test:
- [ ] Can select songs
- [ ] Play/pause toggles
- [ ] Next/previous track works
- [ ] Track info displays
- [ ] Volume controls work

---

## 🐛 **Troubleshooting**

### Problem: "SD Card initialization failed"
**Solutions:**
1. Check wiring (especially CS on GPIO5)
2. Ensure card is inserted fully
3. Verify card is FAT32 formatted
4. Try a different SD card
5. Check 3.3V power connection

### Problem: "No music files found"
**Solutions:**
1. Check file extensions (.mp3, .wav, .flac, .m4a)
2. Files must be in root or subdirectories
3. File names should be ASCII (no special characters)
4. Try copying files again
5. Check SD card isn't write-protected

### Problem: Touch not responding
**Solutions:**
1. Verify TTP229 wiring (GPIO1, GPIO2)
2. Check serial monitor for key presses
3. Ensure TTP229 is powered (3.3V)
4. Try different keys
5. Check for loose connections

### Problem: Display shows garbage
**Solutions:**
1. Check TFT_eSPI User_Setup.h configuration
2. Verify display wiring
3. Ensure SPI pins are correct
4. Check display power (3.3V)
5. Try lower SPI speed

### Problem: System crashes/reboots
**Solutions:**
1. Check power supply (needs 500mA+)
2. Verify all GND connections
3. Check for short circuits
4. Reduce SPI speed
5. Check PSRAM settings in platformio.ini

---

## 🎯 **What's Working**

After successful upload, you should have:

✅ **Full iPod UI** - Beautiful color interface  
✅ **Touch Navigation** - 16-key gesture controls  
✅ **Music Library** - Automatic scanning and organization  
✅ **File Management** - Browse songs, artists, file info  
✅ **Playback Controls** - Play/pause, next/prev, volume  
✅ **SD Card Info** - Storage stats and usage  
✅ **System Integration** - All components working together  

---

## 🔜 **Next Steps: Audio Playback**

This system is **audio-ready**. To add actual playback:

### Option 1: I2S DAC (Recommended)
Add a PCM5102 or MAX98357A DAC module:
```cpp
#include "Audio.h"

Audio audio;

void setup() {
  // ... existing code ...
  
  // Initialize I2S audio
  audio.setPinout(I2S_BCLK, I2S_LRC, I2S_DOUT);
  audio.setVolume(volume);
}

void playTrack(int index) {
  String filename = musicLibrary[index].filename;
  audio.connecttoFS(SD, filename.c_str());
}
```

### Option 2: USB Audio
Use ESP32-S3's built-in USB for audio output to computer/speakers.

### Option 3: Bluetooth
Stream audio via Bluetooth A2DP to wireless speakers/headphones.

---

## 📊 **Performance**

**Expected behavior:**
- Boot time: ~2-3 seconds
- SD scan: ~1 second per 100 files
- Touch response: <50ms
- Screen refresh: ~60fps
- Memory usage: ~200KB RAM

**Capacity:**
- 16GB card: ~4,000 songs (128kbps MP3)
- 32GB card: ~8,000 songs
- Library limit: ~1,000 files (RAM dependent)

---

## 🎉 **Success!**

If everything works, you now have a **fully functional iPod** with:
- Beautiful touch interface
- Music library management
- SD card storage
- Ready for audio playback

This is the foundation for a complete music player. Add audio decoding next, and you'll have a real working iPod!

---

## 💡 **Tips**

1. **Organize your music** - Use folders for artists/albums
2. **Use good file names** - "Artist - Title.mp3" format
3. **Keep library under 500 songs** - For best performance
4. **Use 128-256kbps MP3** - Balance quality and size
5. **Backup your SD card** - Before making changes

Enjoy your custom iPod! 🎵

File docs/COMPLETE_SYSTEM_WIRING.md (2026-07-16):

# 🔌 Complete ESP32-S3 iPod System Wiring Guide
## ESP32-S3 + TFT Display + SD Card + 16-Key Keypad

---

## 📦 **Components Required**

1. **ESP32-S3 DevKit** (main controller)
2. **MSP2806 Display** (2.8" ILI9341 TFT with touch)
3. **SD Card Module** (separate SPI module)
4. **TTP229 16-Key Touch Keypad** (capacitive touch)
5. **Breadboard** (for prototyping)
6. **Jumper Wires** (approximately 25 wires)
7. **USB-C Cable** (for power and programming)

---

## 🎯 **Quick Pin Summary**

```
╔═══════════════════════════════════════════════════════════════╗
║  Component        Pin Name    ESP32-S3 GPIO    Function       ║
╠═══════════════════════════════════════════════════════════════╣
║  TFT Display      CS          GPIO10           Chip Select    ║
║  (VSPI Bus)       DC          GPIO9            Data/Command   ║
║                   RST         GPIO8            Reset          ║
║                   MOSI        GPIO11           SPI Data Out   ║
║                   SCK         GPIO12           SPI Clock      ║
║                   MISO        GPIO13           SPI Data In    ║
║                   LED         3.3V             Backlight      ║
║                   VCC         3.3V             Power          ║
║                   GND         GND              Ground         ║
╠═══════════════════════════════════════════════════════════════╣
║  SD Card Module   CS          GPIO15           Chip Select    ║
║  (HSPI Bus)       MOSI        GPIO35           SPI Data Out   ║
║                   SCK         GPIO36           SPI Clock      ║
║                   MISO        GPIO37           SPI Data In    ║
║                   VCC         3.3V             Power          ║
║                   GND         GND              Ground         ║
╠═══════════════════════════════════════════════════════════════╣
║  TTP229 Keypad    SCL         GPIO2            I2C Clock      ║
║  (I2C Bus)        SDO         GPIO1            I2C Data       ║
║                   VCC         3.3V             Power          ║
║                   GND         GND              Ground         ║
╚═══════════════════════════════════════════════════════════════╝

Total GPIO Pins Used: 12
Total Wires: 25 (including power/ground)
```

---

## 🔌 **Detailed Connection Tables**

### **1. TFT Display (MSP2806) - 9 Wires**

```
Display Pin    →    ESP32-S3 Pin    Wire Color    Notes
───────────────────────────────────────────────────────────────
VCC            →    3.3V            Red           Power supply
GND            →    GND             Black         Ground
CS             →    GPIO10          Orange        Chip Select
RST            →    GPIO8           White         Reset (required!)
DC             →    GPIO9           Gray          Data/Command
SDA/MOSI       →    GPIO11          Blue          SPI Data Out
SCL/SCLK       →    GPIO12          Purple        SPI Clock
SDO/MISO       →    GPIO13          Brown         SPI Data In
LED            →    3.3V            Red           Backlight (always on)
```

**Important Notes:**
- Uses default VSPI bus (SPI2)
- RST pin MUST be connected (not optional)
- LED to 3.3V for full brightness
- MISO is optional but recommended

---

### **2. SD Card Module - 6 Wires**

```
SD Card Pin    →    ESP32-S3 Pin    Wire Color    Notes
───────────────────────────────────────────────────────────────
VCC            →    3.3V            Red           3.3V only!
GND            →    GND             Black         Ground
CS             →    GPIO15          Yellow        Chip Select
MOSI           →    GPIO35          Green         SPI Data Out
SCK            →    GPIO36          Blue          SPI Clock
MISO           →    GPIO37          White         SPI Data In
```

**Important Notes:**
- Uses HSPI bus (SPI3) - separate from display!
- Must use 3.3V (NOT 5V!)
- Different pins than display to avoid conflicts
- All 6 wires required for SD card operation

---

### **3. TTP229 16-Key Keypad - 4 Wires**

```
TTP229 Pin     →    ESP32-S3 Pin    Wire Color    Notes
───────────────────────────────────────────────────────────────
VCC            →    3.3V            Red           Power supply
GND            →    GND             Black         Ground
SCL            →    GPIO2           Yellow        I2C Clock
SDO            →    GPIO1           Green         I2C Data (SDA)
```

**Important Notes:**
- Uses I2C bus (Wire)
- I2C address: 0x57
- GPIO1/GPIO2 are standard I2C pins for ESP32-S3
- Built-in pull-up resistors (no external needed)

---

## 🎨 **Visual Wiring Diagram**

```
                         ESP32-S3 DevKit
                         
                           [USB-C Port]
              ┌────────────────────────────────────┐
              │                                    │
Power Rails:  │  3.3V ●─────────────────────┐      │
              │                             │      │
              │  GND  ●───────────────┐     │      │
              │                       │     │      │
I2C (Keypad): │  IO1  ●─────────┐     │     │      │
              │  IO2  ●───────┐ │     │     │      │
              │               │ │     │     │      │
Display:      │  IO8  ●─────┐ │ │     │     │      │
              │  IO9  ●───┐ │ │ │     │     │      │
              │  IO10 ●─┐ │ │ │ │     │     │      │
              │  IO11 ●─│─│─│─│─│─────│─────│───┐  │
              │  IO12 ●─│─│─│─│─│─────│─────│─┐ │  │
              │  IO13 ●─│─│─│─│─│─────│─────│─│─│─┐│
              │         │ │ │ │ │     │     │ │ │ ││
SD Card:      │  IO15 ●─│─│─│─│─│─────│─────│─│─│─││
              │  IO35 ●─│─│─│─│─│─────│─────│─│─│─││
              │  IO36 ●─│─│─│─│─│─────│─────│─│─│─││
              │  IO37 ●─│─│─│─│─│─────│─────│─│─│─││
              │         │ │ │ │ │     │     │ │ │ ││
              └─────────┼─┼─┼─┼─┼─────┼─────┼─┼─┼─┼┼
                        │ │ │ │ │     │     │ │ │ ││
                        │ │ │ │ │     │     │ │ │ ││
        ┌───────────────┘ │ │ │ │     │     │ │ │ ││
        │   ┌─────────────┘ │ │ │     │     │ │ │ ││
        │   │               │ │ │     │     │ │ │ ││
        ▼   ▼               ▼ ▼ ▼     ▼     ▼ ▼ ▼ ▼▼
    ┌─────────────┐   ┌──────────┐   ┌────────────────┐
    │  TTP229     │   │ MSP2806  │   │   SD Card      │
    │  16-Key     │   │ Display  │   │   Module       │
    │  Keypad     │   │ 2.8" TFT │   │                │
    ├─────────────┤   ├──────────┤   ├────────────────┤
    │ VCC  GND    │   │ VCC  GND │   │ VCC  GND       │
    │ SCL  SDO    │   │ CS   RST │   │ CS   MOSI      │
    │             │   │ DC   MOSI│   │ SCK  MISO      │
    │ [1][2][3][4]│   │ SCK  MISO│   │                │
    │ [5][6][7][8]│   │ LED      │   │                │
    │ [9][10][11] │   │          │   │                │
    │ [13][14][15]│   │          │   │                │
    └─────────────┘   └──────────┘   └────────────────┘
         I2C Bus         VSPI Bus         HSPI Bus
```

---

## 📐 **Breadboard Layout**

```
                    Breadboard Top View
                    
    Power Rails (Left Side):
    [+] ←─── ESP32-S3 3.3V (Red wire)
    [-] ←─── ESP32-S3 GND (Black wire)

    Component Placement:
    
    ┌────────────────────────────────────────────────────┐
    │                                                    │
    │  [+] Power Rail                                    │
    │  [-] Ground Rail                                   │
    │                                                    │
    │  ┌──────────┐         ┌──────────┐                │
    │  │ TTP229   │         │ SD Card  │                │
    │  │ Keypad   │         │ Module   │                │
    │  └──────────┘         └──────────┘                │
    │                                                    │
    │                                                    │
    │  ┌────────────────────────────────┐               │
    │  │      ESP32-S3 DevKit           │               │
    │  │         [USB-C]                │               │
    │  └────────────────────────────────┘               │
    │                                                    │
    │                                                    │
    │  ┌────────────────────────────────┐               │
    │  │     MSP2806 Display            │               │
    │  │     (2.8" TFT Screen)          │               │
    │  └────────────────────────────────┘               │
    │                                                    │
    └────────────────────────────────────────────────────┘
    
    Wire Routing Tips:
    - Keep I2C wires (keypad) short and twisted together
    - Route display wires on one side
    - Route SD card wires on opposite side
    - Use breadboard power rails for all VCC/GND connections
```

---

## 🔧 **Step-by-Step Wiring Instructions**

### **Phase 1: Power Distribution (5 minutes)**

1. **Connect ESP32-S3 to breadboard power rails:**
   ```
   ESP32-S3 3.3V → Breadboard + rail (Red wire)
   ESP32-S3 GND  → Breadboard - rail (Black wire)
   ```

2. **Verify power rails:**
   - Use multimeter to check 3.3V on + rail
   - Check continuity on - rail

---

### **Phase 2: TFT Display (10 minutes)**

3. **Connect display power:**
   ```
   Display VCC → Breadboard + rail (Red)
   Display GND → Breadboard - rail (Black)
   Display LED → Breadboard + rail (Red) - backlight
   ```

4. **Connect display SPI signals:**
   ```
   Display CS   → ESP32-S3 GPIO10 (Orange)
   Display RST  → ESP32-S3 GPIO8  (White)
   Display DC   → ESP32-S3 GPIO9  (Gray)
   Display MOSI → ESP32-S3 GPIO11 (Blue)
   Display SCK  → ESP32-S3 GPIO12 (Purple)
   Display MISO → ESP32-S3 GPIO13 (Brown)
   ```

5. **Test display:**
   - Power on ESP32-S3
   - Display backlight should illuminate
   - If no light, check LED connection

---

### **Phase 3: SD Card Module (5 minutes)**

6. **Connect SD card power:**
   ```
   SD VCC → Breadboard + rail (Red)
   SD GND → Breadboard - rail (Black)
   ```

7. **Connect SD card SPI signals (HSPI bus):**
   ```
   SD CS   → ESP32-S3 GPIO15 (Yellow)
   SD MOSI → ESP32-S3 GPIO35 (Green)
   SD SCK  → ESP32-S3 GPIO36 (Blue)
   SD MISO → ESP32-S3 GPIO37 (White)
   ```

8. **Insert SD card:**
   - Format as FAT32
   - Insert into module
   - Ensure card clicks into place

---

### **Phase 4: TTP229 Keypad (5 minutes)**

9. **Connect keypad power:**
   ```
   TTP229 VCC → Breadboard + rail (Red)
   TTP229 GND → Breadboard - rail (Black)
   ```

10. **Connect keypad I2C signals:**
    ```
    TTP229 SCL → ESP32-S3 GPIO2 (Yellow)
    TTP229 SDO → ESP32-S3 GPIO1 (Green)
    ```

11. **Verify keypad:**
    - Check for power LED (if present)
    - Touch pads should be clean and dry

---

## ✅ **Connection Verification Checklist**

### **Before Powering On:**

**Power Connections:**
- [ ] ESP32-S3 3.3V connected to breadboard + rail
- [ ] ESP32-S3 GND connected to breadboard - rail
- [ ] All component VCC pins connected to + rail
- [ ] All component GND pins connected to - rail
- [ ] No short circuits between + and - rails

**TFT Display (9 wires):**
- [ ] VCC → 3.3V
- [ ] GND → GND
- [ ] LED → 3.3V (backlight)
- [ ] CS → GPIO10
- [ ] RST → GPIO8
- [ ] DC → GPIO9
- [ ] MOSI → GPIO11
- [ ] SCK → GPIO12
- [ ] MISO → GPIO13

**SD Card Module (6 wires):**
- [ ] VCC → 3.3V (NOT 5V!)
- [ ] GND → GND
- [ ] CS → GPIO15
- [ ] MOSI → GPIO35
- [ ] SCK → GPIO36
- [ ] MISO → GPIO37
- [ ] SD card inserted and formatted (FAT32)

**TTP229 Keypad (4 wires):**
- [ ] VCC → 3.3V
- [ ] GND → GND
- [ ] SCL → GPIO2
- [ ] SDO → GPIO1

**Final Checks:**
- [ ] All connections secure (no loose wires)
- [ ] Correct GPIO pins used
- [ ] No crossed wires
- [ ] Multimeter check: 3.3V on power rails
- [ ] Visual inspection complete

---

## 🧪 **Testing Procedure**

### **Test 1: Power Test**
```
1. Connect USB-C to ESP32-S3
2. Check display backlight (should glow)
3. Check keypad power LED (if equipped)
4. Measure voltage on breadboard rails (should be 3.3V)
```

### **Test 2: Display Test**
```
Upload: src/tft_espi_test.cpp

Expected Output:
- Display shows color bars
- Text appears clearly
- No flickering or artifacts

If blank: Check RST, DC, CS connections
If white: Check MOSI, SCK connections
```

### **Test 3: SD Card Test**
```
Upload: src/hspi_sd_test.cpp

Expected Serial Output:
✅ SD Card initialized
   Type: SDHC
   Size: XXXXX MB
   Files found: X

If fails: Check CS, MOSI, SCK, MISO connections
If "Card Mount Failed": Check power and card format
```

### **Test 4: Keypad Test**
```
Upload: src/ttp229_simple_test.cpp

Expected Serial Output:
✅ TTP229 module found at 0x57
✅ I2C initialized on GPIO1/GPIO2

Touch any key:
👆 Key X pressed

If not found: Check SCL/SDO connections
If wrong keys: Verify I2C address (0x57)
```

### **Test 5: Complete System Test**
```
Upload: src/complete_ipod_hspi.cpp

Expected Result:
- Display shows iPod interface
- Touch keys to navigate
- SD card music files listed
- All components working together

This confirms everything is wired correctly!
```

---

## 🚨 **Troubleshooting Guide**

### **Display Issues**

**Problem: Display backlight off**
```
Check:
1. LED pin connected to 3.3V
2. VCC connected to 3.3V
3. GND connected properly
4. Try different USB cable (power issue)
```

**Problem: Display white/blank**
```
Check:
1. RST pin connected to GPIO8 (critical!)
2. DC pin connected to GPIO9
3. CS pin connected to GPIO10
4. MOSI/SCK connections
5. Upload correct test code
```

**Problem: Display garbled/artifacts**
```
Check:
1. Loose connections on SPI pins
2. Wires too long (keep < 15cm)
3. Power supply stable
4. Correct pin definitions in code
```

---

### **SD Card Issues**

**Problem: "Card Mount Failed"**
```
Check:
1. SD card formatted as FAT32
2. Card inserted correctly (clicks in)
3. VCC is 3.3V (NOT 5V!)
4. All 6 wires connected
5. CS pin on GPIO15
```

**Problem: "Card Not Found"**
```
Check:
1. HSPI pins correct (35, 36, 37)
2. Not using display SPI pins (11, 12, 13)
3. CS pin not floating
4. Card module has power
5. Try different SD card
```

**Problem: Files not reading**
```
Check:
1. Card formatted as FAT32 (not exFAT)
2. Files in root directory
3. Filenames 8.3 format or long name support
4. Card not corrupted
5. Sufficient power supply
```

---

### **Keypad Issues**

**Problem: "TTP229 not found"**
```
Check:
1. VCC connected to 3.3V (NOT 5V!)
2. GND connected properly
3. SCL on GPIO2 (not GPIO1)
4. SDO on GPIO1 (not GPIO2)
5. I2C address is 0x57
```

**Problem: Keys not responding**
```
Check:
1. Touch pads clean and dry
2. Firm touch required
3. Module has power LED on
4. I2C communication working (check serial)
5. No interference from other devices
```

**Problem: Wrong keys detected**
```
Check:
1. I2C address correct (0x57)
2. Module in correct mode (16-key)
3. Jumpers on module (if present)
4. Code key mapping correct
5. Serial output for actual key numbers
```

---

### **General Issues**

**Problem: ESP32-S3 won't boot**
```
Check:
1. No short circuits
2. Power supply adequate (500mA+)
3. USB cable good quality
4. No pins shorted to ground
5. Try without peripherals connected
```

**Problem: Intermittent failures**
```
Check:
1. All connections secure
2. Breadboard contacts clean
3. Wires not damaged
4. Power supply stable
5. No loose jumper wires
```

**Problem: Multiple components not working**
```
Check:
1. Power rails have 3.3V
2. Ground connections solid
3. No pin conflicts
4. Correct code uploaded
5. Serial monitor for error messages
```

---

## 💡 **Pro Tips**

### **For Reliable Connections:**
```
✅ Use solid-core wire for breadboard (22-24 AWG)
✅ Keep all wires under 15cm length
✅ Twist I2C wires together (reduces noise)
✅ Use breadboard power rails for distribution
✅ Double-check every connection before power-on
✅ Take photos of your wiring for reference
```

### **For Clean Wiring:**
```
✅ Use color-coded wires consistently
✅ Route wires neatly along breadboard edges
✅ Label wires with tape if needed
✅ Keep similar signals grouped together
✅ Avoid crossing wires when possible
```

### **For Best Performance:**
```
✅ Use quality jumper wires (not cheap ones)
✅ Ensure good breadboard contact
✅ Keep high-speed signals (SPI) short
✅ Separate power wires from signal wires
✅ Use common ground point
✅ Check connections with multimeter
```

### **For Easy Debugging:**
```
✅ Test one component at a time
✅ Use serial monitor for diagnostics
✅ Keep test code simple initially
✅ Document any wiring changes
✅ Mark working configurations
```

---

## 📊 **Bus Architecture**

```
ESP32-S3 Bus Usage:
━━━━━━━━━━━━━━━━━━━━━━━━━━━━━━━━━━━━━━━━━━━━━━━━━━━━━━━━━━

I2C Bus (Wire):
  GPIO1  - SDA (TTP229 SDO)
  GPIO2  - SCL (TTP229 SCL)
  Speed: 100kHz (standard mode)
  Devices: TTP229 Keypad (0x57)

VSPI Bus (SPI2) - Default SPI:
  GPIO11 - MOSI (Display SDA)
  GPIO12 - SCK  (Display SCL)
  GPIO13 - MISO (Display SDO)
  GPIO10 - CS   (Display CS)
  Speed: 40MHz
  Devices: ILI9341 Display

HSPI Bus (SPI3) - Secondary SPI:
  GPIO35 - MOSI (SD Card MOSI)
  GPIO36 - SCK  (SD Card SCK)
  GPIO37 - MISO (SD Card MISO)
  GPIO15 - CS   (SD Card CS)
  Speed: 20MHz
  Devices: SD Card Module

Additional Pins:
  GPIO8  - Display Reset
  GPIO9  - Display Data/Command

━━━━━━━━━━━━━━━━━━━━━━━━━━━━━━━━━━━━━━━━━━━━━━━━━━━━━━━━━━

Why This Configuration?
✅ No pin conflicts between components
✅ Separate SPI buses prevent interference
✅ Standard I2C pins for keypad
✅ All pins available on ESP32-S3
✅ Optimal performance for each bus
```

---

## 📦 **Bill of Materials**

### **Required Components:**
```
□ ESP32-S3 DevKit (1x)                    ~$10-15
□ MSP2806 Display 2.8" ILI9341 (1x)       ~$8-12
□ SD Card Module (SPI interface) (1x)     ~$2-5
□ TTP229 16-Key Touch Keypad (1x)         ~$5-8
□ Breadboard 830 points (1x)              ~$3-5
□ Jumper wires M-M 20cm (30x)             ~$3-5
□ USB-C cable (1x)                        ~$3-5
□ MicroSD card 8-32GB (1x)                ~$5-10

Total Cost: ~$40-65
```

### **Optional Tools:**
```
□ Multimeter (for testing)                ~$15-30
□ Wire stripper/cutter                    ~$10-15
□ Label maker or tape                     ~$5-10
□ Helping hands/PCB holder                ~$10-20
□ Soldering iron (for permanent build)    ~$20-40
```

---

## 🎯 **Quick Start Summary**

1. **Gather all components** and verify you have everything
2. **Set up breadboard** with power rails connected
3. **Wire display first** (9 wires) and test
4. **Wire SD card** (6 wires) and test
5. **Wire keypad** (4 wires) and test
6. **Upload complete system code** and enjoy!

Total wiring time: ~30 minutes
Total testing time: ~15 minutes

---

## 🚀 **Next Steps**

After successful wiring:

1. **Upload complete system:** `src/complete_ipod_hspi.cpp`
2. **Add music files** to SD card (MP3 format)
3. **Test all features:** navigation, playback, gestures
4. **Design enclosure:** See `docs/case_design.md`
5. **Create PCB:** See `docs/pcb_design_guide.md`

---

## 📝 **Configuration File**

Your `src/config.h` should match these pin assignments:

```cpp
// Display - VSPI Bus
#define TFT_CS 10
#define TFT_DC 9
#define TFT_RST 8
#define TFT_MOSI 11
#define TFT_SCLK 12
#define TFT_MISO 13

// SD Card - HSPI Bus
#define SD_CS 15
#define SD_MOSI 35
#define SD_SCK 36
#define SD_MISO 37

// TTP229 Keypad - I2C Bus
#define I2C_SDA 1
#define I2C_SCL 2
#define TTP229_ADDR 0x57
```

---

## ✨ **You're All Set!**

With these connections, you have a complete iPod system:
- ✅ 2.8" color touchscreen display
- ✅ SD card for music storage
- ✅ 16-key capacitive touch keypad
- ✅ Gesture recognition
- ✅ Full iPod interface

Total: **25 wires, 12 GPIO pins, 3 buses**

Now go build something awesome! 🎵🚀

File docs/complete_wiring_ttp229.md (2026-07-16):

# Complete Wiring Guide - ESP32-S3 + TTP229 + Display

## 🔌 **Complete System Connections**

### **Components:**
1. ESP32-S3 DevKit
2. TTP229 16-Key Touch Module
3. MSP2806 Display (2.8" ILI9341)

---

## 📋 **Quick Connection Summary**

### **TTP229 Touch Module (4 wires)**
```
TTP229 Pin    →    ESP32-S3 Pin
----------         ------------
VCC           →    3.3V
GND           →    GND
SCL           →    GPIO2 (I2C Clock)
SDO           →    GPIO1 (I2C Data/SDA)
```

### **MSP2806 Display (9 wires)**
```
Display Pin   →    ESP32-S3 Pin
-----------        ------------
VCC           →    3.3V
GND           →    GND
CS            →    GPIO10
RST           →    GPIO8
DC            →    GPIO9
SDA/MOSI      →    GPIO11
SCL/SCLK      →    GPIO12
SDO/MISO      →    GPIO13
LED           →    3.3V
```

---

## 🎨 **Visual Wiring Diagram**

```
                    ESP32-S3 DevKit
                    
                      [USB-C Port]
         ┌─────────────────────────────────┐
         │                                 │
         │  3.3V ●─────────────────┐       │
         │   GND ●───────────┐     │       │
         │                   │     │       │
         │  IO21 ●───────┐   │     │       │
         │  IO22 ●─────┐ │   │     │       │
         │             │ │   │     │       │
         │   IO8 ●───┐ │ │   │     │       │
         │   IO9 ●─┐ │ │ │   │     │       │
         │  IO10 ●─│─│─│─│───│─────│───┐   │
         │  IO11 ●─│─│─│─│───│─────│─┐ │   │
         │  IO12 ●─│─│─│─│───│─────│─│─│─┐ │
         │  IO13 ●─│─│─│─│───│─────│─│─│─│─│
         │         │ │ │ │   │     │ │ │ │ │
         └─────────│─│─│─│───│─────│─│─│─│─│
                   │ │ │ │   │     │ │ │ │ │
                   │ │ │ │   │     │ │ │ │ │
    ┌──────────────│─│─│─│───│─────┘ │ │ │ │
    │              │ │ │ │   │       │ │ │ │
    │  TTP229      │ │ │ │   │       │ │ │ │
    │  Module      │ │ │ │   │       │ │ │ │
    │              │ │ │ │   │       │ │ │ │
    │  ┌────────┐  │ │ │ │   │       │ │ │ │
    │  │ Header │  │ │ │ │   │       │ │ │ │
    │  │  Pins  │  │ │ │ │   │       │ │ │ │
    │  └────────┘  │ │ │ │   │       │ │ │ │
    │   │ │ │ │    │ │ │ │   │       │ │ │ │
    │  VCC│ │ │    │ │ │ │   │       │ │ │ │
    │  GND│ │ │    │ │ │ │   │       │ │ │ │
    │  SCL│ │ │    │ │ │ │   │       │ │ │ │
    │  SDO│ │ │    │ │ │ │   │       │ │ │ │
    │     │ │ │    │ │ │ │   │       │ │ │ │
    └─────┼─┼─┼────┘ │ │ │   │       │ │ │ │
          │ │ │      │ │ │   │       │ │ │ │
          │ │ └──────┘ │ │   │       │ │ │ │
          │ └──────────┘ │   │       │ │ │ │
          │              │   │       │ │ │ │
          └──────────────┘   │       │ │ │ │
                             │       │ │ │ │
                             │       │ │ │ │
    ┌────────────────────────┘       │ │ │ │
    │                                │ │ │ │
    │  MSP2806 Display               │ │ │ │
    │  (2.8" ILI9341)                │ │ │ │
    │                                │ │ │ │
    │  ┌──────────────────────┐      │ │ │ │
    │  │                      │      │ │ │ │
    │  │    240 x 320 px      │      │ │ │ │
    │  │      Display         │      │ │ │ │
    │  │                      │      │ │ │ │
    │  └──────────────────────┘      │ │ │ │
    │                                │ │ │ │
    │  Pin Header:                   │ │ │ │
    │  VCC ──────────────────────────┘ │ │ │
    │  GND ────────────────────────────┘ │ │
    │  CS  ──────────────────────────────┘ │
    │  RST ────────────────────────────────┘
    │  DC  ──────────────────────────────┐
    │  SDA ────────────────────────────┐ │
    │  SCL ──────────────────────────┐ │ │
    │  SDO ────────────────────────┐ │ │ │
    │  LED ──────────────────────┐ │ │ │ │
    │                            │ │ │ │ │
    └────────────────────────────┼─┼─┼─┼─┼─┐
                                 │ │ │ │ │ │
                    To 3.3V ─────┘ │ │ │ │ │
                    To GPIO9 ───────┘ │ │ │
                    To GPIO11 ─────────┘ │ │
                    To GPIO12 ───────────┘ │
                    To GPIO13 ─────────────┘
```

---

## 📸 **Breadboard Layout**

```
                    Breadboard View
                    
    Power Rails:
    [+] ←─── ESP32-S3 3.3V
    [-] ←─── ESP32-S3 GND

    TTP229 Module:                    ESP32-S3:
    ┌──────────────┐                 ┌──────────┐
    │   [Header]   │                 │          │
    │   VCC ●──────┼─────────────────┤ 3.3V     │
    │   GND ●──────┼─────────────────┤ GND      │
    │   SCL ●──────┼─────────────────┤ GPIO22   │
    │   SDO ●──────┼─────────────────┤ GPIO21   │
    │              │                 │          │
    │  [1][2][3][4]│                 │          │
    │  [5][6][7][8]│                 │          │
    │  [9][10][11] │                 │          │
    │  [13][14][15]│                 │          │
    └──────────────┘                 └──────────┘

    Display Module:                   ESP32-S3:
    ┌──────────────┐                 ┌──────────┐
    │  [Display]   │                 │          │
    │   VCC ●──────┼─────────────────┤ 3.3V     │
    │   GND ●──────┼─────────────────┤ GND      │
    │   CS  ●──────┼─────────────────┤ GPIO10   │
    │   RST ●──────┼─────────────────┤ GPIO8    │
    │   DC  ●──────┼─────────────────┤ GPIO9    │
    │   SDA ●──────┼─────────────────┤ GPIO11   │
    │   SCL ●──────┼─────────────────┤ GPIO12   │
    │   SDO ●──────┼─────────────────┤ GPIO13   │
    │   LED ●──────┼─────────────────┤ 3.3V     │
    └──────────────┘                 └──────────┘
```

---

## 🔧 **Step-by-Step Wiring Instructions**

### **Step 1: Power Connections**
```
1. Connect ESP32-S3 3.3V to breadboard + rail
2. Connect ESP32-S3 GND to breadboard - rail
3. Connect TTP229 VCC to + rail
4. Connect TTP229 GND to - rail
5. Connect Display VCC to + rail
6. Connect Display GND to - rail
7. Connect Display LED to + rail (backlight)
```

### **Step 2: TTP229 I2C Connections**
```
1. TTP229 SCL → ESP32-S3 GPIO2 (yellow wire)
2. TTP229 SDO → ESP32-S3 GPIO1 (green wire)
```

### **Step 3: Display SPI Connections**
```
1. Display CS   → ESP32-S3 GPIO10 (orange wire)
2. Display RST  → ESP32-S3 GPIO8  (white wire)
3. Display DC   → ESP32-S3 GPIO9  (gray wire)
4. Display SDA  → ESP32-S3 GPIO11 (blue wire)
5. Display SCL  → ESP32-S3 GPIO12 (purple wire)
6. Display SDO  → ESP32-S3 GPIO13 (brown wire)
```

---

## 📊 **Pin Assignment Table**

### **ESP32-S3 Pin Usage**
```
GPIO Pin    Function        Connected To
--------    --------        ------------
GPIO1       I2C SDA         TTP229 SDO
GPIO2       I2C SCL         TTP229 SCL
GPIO8       Display RST     MSP2806 RST
GPIO9       Display DC      MSP2806 DC
GPIO10      Display CS      MSP2806 CS
GPIO11      SPI MOSI        MSP2806 SDA
GPIO12      SPI CLK         MSP2806 SCL
GPIO13      SPI MISO        MSP2806 SDO
3.3V        Power           TTP229 VCC, Display VCC, Display LED
GND         Ground          TTP229 GND, Display GND
```

### **Available GPIO Pins (for future expansion)**
```
GPIO0, GPIO3, GPIO4, GPIO5, GPIO6, GPIO7
GPIO14, GPIO15, GPIO16, GPIO17, GPIO18, GPIO19, GPIO20
GPIO35, GPIO36, GPIO37, GPIO38, GPIO39, GPIO40, GPIO41, GPIO42
GPIO43, GPIO44, GPIO45, GPIO46, GPIO47, GPIO48

Note: GPIO21 and GPIO22 are used for USB on ESP32-S3
```

---

## 🎨 **Color-Coded Wire Recommendations**

```
Power:
  Red    → 3.3V connections
  Black  → GND connections

TTP229 (I2C):
  Yellow → SCL (GPIO2)
  Green  → SDA (GPIO1)

Display (SPI):
  Orange → CS (GPIO10)
  White  → RST (GPIO8)
  Gray   → DC (GPIO9)
  Blue   → MOSI (GPIO11)
  Purple → CLK (GPIO12)
  Brown  → MISO (GPIO13)
```

---

## ✅ **Connection Checklist**

### **Before Powering On:**
```
□ TTP229 VCC connected to 3.3V
□ TTP229 GND connected to GND
□ TTP229 SCL connected to GPIO2
□ TTP229 SDO connected to GPIO1

□ Display VCC connected to 3.3V
□ Display GND connected to GND
□ Display LED connected to 3.3V
□ Display CS connected to GPIO10
□ Display RST connected to GPIO8
□ Display DC connected to GPIO9
□ Display SDA connected to GPIO11
□ Display SCL connected to GPIO12
□ Display SDO connected to GPIO13

□ No short circuits between power and ground
□ All connections are secure
□ Correct GPIO pins used
```

---

## 🔍 **Testing Connections**

### **Test 1: Power Test**
```
1. Connect USB-C to ESP32-S3
2. Check TTP229 power LED (if present)
3. Check Display backlight (should glow)
4. If no backlight, check LED connection
```

### **Test 2: TTP229 I2C Test**
```
1. Upload: src/ttp229_keypad_test.cpp
2. Open Serial Monitor (115200 baud)
3. Should see: "✅ TTP229 module found!"
4. Touch any key (1-16)
5. Should see: "👆 Key X pressed"
```

### **Test 3: Display Test**
```
1. Upload: src/simple_tft_test.cpp
2. Display should show colors
3. If blank: Check RST, DC, CS connections
4. If white: Check SPI connections (MOSI, CLK)
```

### **Test 4: Complete System Test**
```
1. Upload: src/ttp229_gesture_ipod.cpp
2. Display should show iPod interface
3. Touch keys to navigate
4. Try gestures (swipe, scroll)
5. Check Serial Monitor for gesture detection
```

---

## 🚨 **Troubleshooting**

### **TTP229 Not Detected**
```
Problem: "❌ TTP229 not found!"
Check:
1. VCC connected to 3.3V (not 5V!)
2. GND connected properly
3. SCL on GPIO2 (not GPIO1)
4. SDO on GPIO1 (not GPIO2)
5. Module has power LED on (if equipped)
```

### **Display Not Working**
```
Problem: Blank or white screen
Check:
1. LED connected to 3.3V (backlight)
2. VCC connected to 3.3V
3. All SPI pins connected correctly
4. RST not floating (must be connected)
5. Try different USB cable (power issue)
```

### **Touch Not Responding**
```
Problem: Keys don't register
Check:
1. I2C address correct (0x57)
2. Pull-up resistors (usually built-in)
3. Touch pads clean and dry
4. Firmware uploaded correctly
5. Serial Monitor shows I2C communication
```

---

## 💡 **Pro Tips**

### **For Reliable Connections:**
```
✅ Use solid core wire for breadboard
✅ Keep wires short (< 15cm)
✅ Twist I2C wires together (reduce noise)
✅ Use breadboard power rails
✅ Double-check all connections before power-on
```

### **For Clean Wiring:**
```
✅ Use color-coded wires
✅ Route wires neatly
✅ Label wires with tape
✅ Take photos for reference
✅ Document any changes
```

### **For Best Performance:**
```
✅ Keep TTP229 away from display
✅ Use short I2C wires
✅ Ensure good ground connection
✅ Use quality jumper wires
✅ Check for loose connections
```

---

## 📦 **Required Materials**

```
Hardware:
□ ESP32-S3 DevKit (1x)
□ TTP229 16-Key Touch Module (1x)
□ MSP2806 Display 2.8" (1x)
□ Breadboard (1x)
□ Jumper wires M-M (20x)
□ USB-C cable (1x)

Optional:
□ Wire stripper
□ Multimeter
□ Label tape
□ Cable ties
```

---

## 🎯 **Quick Start**

1. **Wire everything** following the diagram above
2. **Double-check** all connections with checklist
3. **Upload test code** `src/ttp229_keypad_test.cpp`
4. **Verify** TTP229 detection in Serial Monitor
5. **Upload gesture code** `src/ttp229_gesture_ipod.cpp`
6. **Try gestures** - swipe, scroll, tap!

That's it! You now have a **complete gesture-controlled iPod** with your TTP229 module! 🎵

The wiring is simple - just **13 wires total** (4 for TTP229, 9 for display), and you're ready to go! 🚀

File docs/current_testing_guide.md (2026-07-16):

# Current Testing Guide - ESP32-S3 iPod Project

## 🎯 Current Status

We've fixed the intermittent touch issues and created an integrated iPod UI. Here's how to test the current state:

## 📋 Testing Sequence

### **Step 1: Test Fixed Touch Configuration**

Upload **`src/touch_config_test_fixed.cpp`** first:

```cpp
// This tests the fixed touch handling with:
// ✅ ESP32 Arduino Core 3.x compatibility (fs::File namespace)
// ✅ Improved debouncing and filtering
// ✅ Touch quality metrics
// ✅ Gesture detection
// ✅ Calibration storage in SPIFFS
```

**Expected Results:**
- ✅ Touch calibration loads/saves properly
- ✅ Touch coordinates are stable and accurate
- ✅ Swipe gestures work (left, right, up, down)
- ✅ Long press detection works
- ✅ No false touches or missed touches

### **Step 2: Run Complete System Test**

Upload **`src/complete_ipod_test.cpp`** for comprehensive validation:

```cpp
// This provides a test suite with:
// 1. Touch Diagnostic (30-second reliability test)
// 2. Touch Calibration
// 3. UI Demo placeholder
// 4. Performance Test
// 5. Complete System Test
```

**Touch Diagnostic Results to Look For:**
- ✅ **Success Rate > 95%**
- ✅ **Average Response Time < 100ms**
- ✅ **Max Consecutive Misses < 5**
- ✅ **Consistent coordinate accuracy**

### **Step 3: Test Integrated iPod UI**

Upload **`src/ipod_ui_integrated.cpp`** for the full experience:

```cpp
// Features:
// ✅ Reliable touch handling with debouncing
// ✅ Gesture support (swipe, long press)
// ✅ Multiple screens (Home, Library, Now Playing, Settings)
// ✅ Visual feedback for all interactions
// ✅ Touch quality indicators
// ✅ Context menus and advanced features
```

## 🔧 Hardware Requirements

### **Wiring (ESP32-S3 + MSP2806):**

```
Display (ILI9341):
ESP32-S3    MSP2806
GPIO10  →   CS
GPIO9   →   DC  
GPIO8   →   RST
GPIO11  →   SDA/MOSI
GPIO12  →   SCL/SCLK
GPIO13  →   SDO/MISO
3.3V    →   VCC
3.3V    →   LED (backlight)
GND     →   GND

Touch (XPT2046):
ESP32-S3    MSP2806
GPIO6   →   T_CS
GPIO7   →   T_CLK
GPIO5   →   T_DIN
GPIO4   →   T_DO
GPIO3   →   T_IRQ (optional)
3.3V    →   VCC (shared)
GND     →   GND (shared)
```

### **Required Files:**

Make sure you have the correct **`User_Setup.h`** in your TFT_eSPI library folder. Use **`src/User_Setup_Complete.h`** as your template.

## 🚀 Quick Start Instructions

### **1. Arduino IDE Setup:**
```bash
1. Install ESP32 board package (version 3.x)
2. Select "ESP32S3 Dev Module" 
3. Set partition scheme to "Default 4MB with spiffs"
4. Install TFT_eSPI library
5. Copy User_Setup_Complete.h to TFT_eSPI/User_Setup.h
```

### **2. Test Sequence:**
```bash
1. Upload touch_config_test_fixed.cpp
   - Verify touch works reliably
   - Calibrate if needed
   
2. Upload complete_ipod_test.cpp  
   - Run diagnostic test (should show >95% success)
   - Run complete system test (all should PASS)
   
3. Upload ipod_ui_integrated.cpp
   - Test all UI screens
   - Verify gestures work
   - Test touch responsiveness
```

## 📊 Success Criteria

### **Touch Performance:**
- ✅ Success rate > 95%
- ✅ Response time < 100ms
- ✅ No dead zones on screen
- ✅ Accurate coordinate mapping
- ✅ Gesture recognition works

### **UI Functionality:**
- ✅ All screens accessible
- ✅ Smooth transitions
- ✅ Visual feedback on touch
- ✅ No UI freezing or crashes
- ✅ Settings and controls work

### **System Stability:**
- ✅ No memory leaks
- ✅ Consistent performance
- ✅ Proper calibration storage
- ✅ Error handling works

## 🔍 Troubleshooting

### **If Touch is Still Intermittent:**

1. **Check Hardware:**
   ```bash
   - Push all breadboard connections firmly
   - Measure 3.3V power supply stability
   - Try shorter jumper wires
   - Clean the display screen
   ```

2. **Adjust Software Settings:**
   ```cpp
   // In your code, try:
   #define TOUCH_DEBOUNCE_MS 100     // Increase debounce
   #define MIN_CONSECUTIVE_READS 5   // Require more confirmations
   #define SPI_TOUCH_FREQUENCY 1000000  // Reduce SPI speed
   ```

3. **Check Serial Output:**
   ```bash
   - Look for "Touch started/ended" messages
   - Check success rates in diagnostic
   - Monitor for error messages
   ```

### **If UI is Unresponsive:**

1. **Verify Calibration:**
   ```bash
   - Run touch calibration test
   - Check if coordinates map correctly
   - Try recalibrating with stylus
   ```

2. **Check Memory:**
   ```bash
   - Monitor free heap in serial output
   - Look for memory allocation errors
   - Restart if memory gets low
   ```

## 🎵 Next Steps

Once all tests pass:

1. **Add SD Card Support** - Load actual music files
2. **Implement Audio Playback** - ESP32 I2S audio output
3. **Add Bluetooth** - Wireless audio streaming
4. **Create Case Design** - 3D printed enclosure
5. **Battery Management** - Portable power system

## 📝 Current File Status

### **Ready to Test:**
- ✅ `src/touch_config_test_fixed.cpp` - Fixed touch test
- ✅ `src/complete_ipod_test.cpp` - Comprehensive test suite  
- ✅ `src/ipod_ui_integrated.cpp` - Full iPod UI with reliable touch
- ✅ `src/User_Setup_Complete.h` - Complete TFT configuration

### **Documentation:**
- ✅ `docs/touch_troubleshooting.md` - Detailed troubleshooting guide
- ✅ `docs/ipod_ui_design.md` - UI design specifications
- ✅ All hardware setup and wiring guides

The system should now work reliably with proper touch handling and a complete iPod-style interface! 🎉

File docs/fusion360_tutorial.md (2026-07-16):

# Fusion 360 iPod Case Tutorial

## 🎯 **Step-by-Step Guide to Create Your iPod Case**

### **Prerequisites:**
- Fusion 360 installed (free for personal use)
- Basic knowledge of sketching and extrusion
- Component measurements from the design guide

## 📐 **Step 1: Create New Design**

1. **Open Fusion 360**
2. **File → New Design**
3. **Set Units:**
   - Right-click on document name
   - Properties → Units → Millimeters

## 🏗️ **Step 2: Create Main Shell Body**

### **2.1 Base Sketch:**
```
1. Create Sketch on XY Plane
2. Rectangle: 65mm x 110mm (centered on origin)
3. Fillet corners: 5mm radius
4. Finish Sketch
```

### **2.2 Extrude Shell:**
```
1. Extrude: 18mm height
2. Operation: New Body
3. Name: "Shell_Body"
```

### **2.3 Shell Out:**
```
1. Select top face
2. Shell: -2mm thickness (inward)
3. Remove top face (leave open)
```

## 📱 **Step 3: Display Window**

### **3.1 Display Sketch:**
```
1. Create Sketch on top face
2. Rectangle: 52mm x 39mm
3. Position: 15mm from top edge, centered
4. Finish Sketch
```

### **3.2 Display Recess:**
```
1. Extrude: -1mm (into body)
2. Operation: Cut
3. This creates the display window recess
```

## 🔄 **Step 4: Rotary Encoder**

### **4.1 Encoder Position:**
```
1. Create Sketch on top face
2. Circle: 7mm diameter
3. Position: Center, 25mm below display window
4. Finish Sketch
```

### **4.2 Encoder Hole:**
```
1. Extrude: Through All
2. Operation: Cut
3. This creates the encoder shaft hole
```

### **4.3 Encoder Ring:**
```
1. Create Sketch on top face (around encoder hole)
2. Circle: 20mm diameter (concentric with hole)
3. Extrude: 0.5mm upward
4. Operation: Join
5. This creates the decorative encoder ring
```

## 🔘 **Step 5: Navigation Buttons**

### **5.1 Button Layout Sketch:**
```
1. Create Sketch on top face
2. Create 4 circles: 4mm diameter each
3. Positions relative to encoder center:
   - Menu: -15mm X, -15mm Y
   - Play: +15mm X, -15mm Y  
   - Prev: -20mm X, 0mm Y
   - Next: +20mm X, 0mm Y
4. Finish Sketch
```

### **5.2 Button Holes:**
```
1. Extrude: Through All
2. Operation: Cut
3. Creates holes for tactile switches
```

## 📦 **Step 6: Display Mounting Posts**

### **6.1 Mounting Post Sketch:**
```
1. Create Sketch on inside bottom face
2. Create 4 circles: 4.5mm diameter
3. Positions (M2.5 screw pattern):
   - 25mm spacing from display center
   - 5mm from display edges
4. Finish Sketch
```

### **6.2 Create Posts:**
```
1. Extrude: 4mm upward
2. Operation: Join
3. Creates mounting posts for display
```

### **6.3 Screw Holes:**
```
1. Create Sketch on top of posts
2. Circles: 2mm diameter (M2.5 clearance)
3. Extrude: Through posts
4. Operation: Cut
```

## 🔧 **Step 7: Snap-Fit Mechanism**

### **7.1 Tab Positions:**
```
1. Create Sketch on shell perimeter
2. Mark 4 positions:
   - Top center
   - Bottom center  
   - Left center
   - Right center
3. Rectangles: 8mm x 1mm
```

### **7.2 Create Tabs:**
```
1. Extrude: 2mm outward
2. Add 0.5mm taper for flexibility
3. Round edges: 0.5mm fillet
```

## 🔌 **Step 8: USB-C Cutout**

### **8.1 USB Cutout Sketch:**
```
1. Create Sketch on back face
2. Rectangle: 10mm x 4.5mm
3. Position: Top center
4. Round corners: 1mm radius
```

### **8.2 Cut USB Opening:**
```
1. Extrude: Through wall thickness
2. Operation: Cut
```

## 💨 **Step 9: Ventilation Holes**

### **9.1 Ventilation Pattern:**
```
1. Create Sketch on back face
2. 4 circles: 3mm diameter
3. Pattern in corners (avoid components)
4. Finish Sketch
```

### **9.2 Cut Holes:**
```
1. Extrude: Through wall
2. Operation: Cut
```

## 🏠 **Step 10: ESP32-S3 Mount**

### **10.1 ESP32 Channel:**
```
1. Create Sketch on inside bottom
2. Rectangle: 26mm x 56mm
3. Position: Back area, centered
4. Finish Sketch
```

### **10.2 Create Channel:**
```
1. Extrude: 9mm upward
2. Operation: Join (creates walls)
3. Shell: -1.5mm to create channel
```

## 🔄 **Step 11: Create Bottom Shell**

### **11.1 Mirror Top Shell:**
```
1. Copy shell body
2. Remove display features
3. Add component mounts
4. Add snap-fit receptacles
```

### **11.2 Snap-Fit Receptacles:**
```
1. Create matching cuts for tabs
2. Size: 10mm x 3mm x 6mm deep
3. Position to match top shell tabs
```

## ✅ **Step 12: Final Details**

### **12.1 Fillets and Chamfers:**
```
1. Add 0.5mm fillets to sharp edges
2. Chamfer button holes: 0.5mm
3. Round internal corners: 1mm
```

### **12.2 Text/Branding:**
```
1. Create Sketch on back face
2. Add text: "iPod ESP32-S3"
3. Emboss: 0.2mm depth
```

## 🖨️ **Step 13: Prepare for 3D Printing**

### **13.1 Check Design:**
```
1. Inspect → Section Analysis
2. Check wall thickness (minimum 2mm)
3. Verify clearances
4. Test snap-fit flexibility
```

### **13.2 Export STL:**
```
1. Right-click body → Save as STL
2. Resolution: High
3. Format: Binary
4. Units: Millimeters
```

## 🎨 **Step 14: Advanced Features (Optional)**

### **14.1 Heat-Set Inserts:**
```
1. Replace screw holes with insert holes
2. Diameter: 3.2mm for M2.5 inserts
3. Depth: 4mm
```

### **14.2 Light Pipes:**
```
1. Create channels for LED indicators
2. Transparent material inserts
3. Connect to ESP32 status LEDs
```

### **14.3 Gasket Grooves:**
```
1. Create groove around shell perimeter
2. Width: 2mm, Depth: 1mm
3. For O-ring weather sealing
```

## 📋 **Design Checklist**

### **Before Printing:**
```
□ All dimensions verified against components
□ Clearances adequate (0.2mm minimum)
□ No overhangs >45° without support
□ Wall thickness ≥2mm everywhere
□ Snap-fits have proper taper
□ Mounting holes aligned correctly
□ USB cutout properly positioned
□ Ventilation adequate
□ Assembly sequence verified
□ STL files exported and checked
```

### **Print Settings Verification:**
```
□ Layer height: 0.2mm
□ Infill: 20% minimum
□ Support: Auto-generated
□ Adhesion: Brim or raft
□ Material: PLA or PETG
□ Print orientation optimized
```

## 🔧 **Troubleshooting Common Issues**

### **Fit Problems:**
- **Too tight:** Increase clearances by 0.1-0.2mm
- **Too loose:** Decrease clearances or add friction features
- **Warping:** Increase bed adhesion, reduce print speed

### **Assembly Issues:**
- **Snap-fits break:** Add more taper, reduce thickness
- **Components don't fit:** Verify measurements, check tolerances
- **Misalignment:** Add alignment features, check symmetry

## 📁 **File Organization**

### **Recommended Structure:**
```
iPod_Case_Project/
├── Fusion360/
│   ├── iPod_Case_v1.f3d
│   ├── Top_Shell.f3d
│   └── Bottom_Shell.f3d
├── STL_Files/
│   ├── iPod_Top_Shell.stl
│   └── iPod_Bottom_Shell.stl
├── Documentation/
│   ├── Assembly_Instructions.pdf
│   └── BOM.xlsx
└── Photos/
    ├── CAD_Screenshots/
    └── Printed_Parts/
```

This tutorial will guide you through creating a professional-quality iPod case in Fusion 360. Take your time with each step and test-fit components as you go! 🎯

## 🎓 **Learning Resources**

- **Fusion 360 Basics:** Autodesk's free tutorials
- **3D Printing Design:** Prusa's design guidelines  
- **Snap-Fit Design:** McMaster-Carr's technical guides
- **Component Libraries:** GrabCAD for standard parts

Happy designing! Your custom iPod case will be both functional and stylish. 🚀

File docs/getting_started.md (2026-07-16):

# Getting Started

## Prerequisites

### Software Requirements
- [PlatformIO IDE](https://platformio.org/platformio-ide) or PlatformIO Core
- [Git](https://git-scm.com/) for version control
- [Python 3.7+](https://python.org/) (for PlatformIO)

### Hardware Requirements
- ESP32-S3 development board
- USB-C cable for programming
- Breadboard and jumper wires for prototyping
- Components listed in [hardware_setup.md](hardware_setup.md)

## Quick Start

### 1. Clone the Repository
```bash
git clone <repository-url>
cd esp32-ipod-player
```

### 2. Install PlatformIO
If using VS Code:
```bash
# Install PlatformIO extension from VS Code marketplace
```

If using command line:
```bash
pip install platformio
```

### 3. Build the Project
```bash
# Navigate to project directory
cd esp32-ipod-player

# Build the project
pio run

# Upload to ESP32-S3
pio run --target upload

# Monitor serial output
pio device monitor
```

### 4. Basic Hardware Setup
For initial testing, you only need:
1. ESP32-S3 board
2. USB-C cable
3. Optional: LED on GPIO2 for status indication

## Development Phases

### Phase 1: Core Hardware (Weeks 1-3)
**Goal**: Get basic hardware working

**Tasks**:
- [ ] Order all components
- [ ] Design PCB or breadboard layout
- [ ] 3D print or design case
- [ ] Assemble core components
- [ ] Test power supply
- [ ] Verify pin connections

**Deliverables**:
- Working hardware prototype
- Power management functional
- Basic connectivity verified

### Phase 2: Basic Software (Weeks 4-6)
**Goal**: Implement core functionality

**Tasks**:
- [ ] Display initialization and LVGL setup
- [ ] SD card reading and file system
- [ ] Basic audio playback (MP3)
- [ ] Rotary encoder input
- [ ] Simple UI navigation

**Deliverables**:
- Basic music player functionality
- File browsing and selection
- Play/pause/stop controls
- Volume adjustment

### Phase 3: Advanced Features (Weeks 7-9)
**Goal**: Add advanced audio and connectivity

**Tasks**:
- [ ] USB-C charging and audio
- [ ] Bluetooth A2DP implementation
- [ ] Capacitive touch input
- [ ] Music library scanning and organization
- [ ] Album art display

**Deliverables**:
- Multi-source audio (SD, Bluetooth, USB)
- Touch navigation
- Organized music library
- Visual enhancements

### Phase 4: Polish and Testing (Weeks 10-12)
**Goal**: Finalize and optimize

**Tasks**:
- [ ] UI animations and transitions
- [ ] Equalizer implementation
- [ ] Power optimization
- [ ] Final case assembly
- [ ] Comprehensive testing
- [ ] Documentation completion

**Deliverables**:
- Production-ready device
- Complete documentation
- User manual
- Source code cleanup

## Testing Strategy

### Unit Testing
Each manager class should be testable independently:
```cpp
// Example test structure
void test_audio_manager() {
    AudioManager audio;
    assert(audio.init() == true);
    assert(audio.getVolume() == 50); // Default volume
    // Add more tests...
}
```

### Integration Testing
Test manager interactions:
- UI -> Audio control
- Input -> UI navigation
- Power -> System sleep/wake

### Hardware Testing
- Pin connectivity verification
- Power consumption measurement
- Audio quality testing
- Battery life testing

## Troubleshooting

### Common Issues

**Display not working**:
- Check SPI connections
- Verify power supply (3.3V)
- Check TFT_eSPI configuration

**SD card not detected**:
- Verify SPI connections
- Check SD card format (FAT32)
- Ensure proper power supply

**Audio not playing**:
- Check I2S connections
- Verify audio file format
- Test with simple WAV file first

**Touch not responding**:
- Check I2C connections
- Verify touch controller power
- Test I2C communication

### Debug Tools
- Serial monitor for logging
- Logic analyzer for signal verification
- Multimeter for power measurements
- Oscilloscope for audio signals

## Next Steps

1. **Start with Phase 1**: Order components and plan hardware
2. **Set up development environment**: Install PlatformIO and test basic build
3. **Begin prototyping**: Start with display and basic UI
4. **Iterate quickly**: Test each component as you add it
5. **Document progress**: Keep notes on what works and what doesn't

## Resources

- [ESP32-S3 Datasheet](https://www.espressif.com/sites/default/files/documentation/esp32-s3_datasheet_en.pdf)
- [LVGL Documentation](https://docs.lvgl.io/)
- [PlatformIO Documentation](https://docs.platformio.org/)
- [TFT_eSPI Library](https://github.com/Bodmer/TFT_eSPI)
- [ESP32-AudioI2S Library](https://github.com/pschatzmann/ESP32-A2DP)

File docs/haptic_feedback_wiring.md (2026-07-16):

# ESP32-S3 iPod Haptic Feedback System - Wiring Guide

## 🎯 **Haptic Feedback Overview**

Since touch isn't working reliably, we're implementing **haptic feedback buttons** to create an authentic iPod experience with tactile response. This uses the **DRV2605L Haptic Motor Driver** with a **Linear Resonant Actuator (LRA)** to provide precise vibration patterns.

## 🔌 **Required Components**

### **1. DRV2605L Haptic Motor Driver Board**
- **I2C Interface** - Easy ESP32-S3 integration
- **Built-in Effects Library** - 123 pre-programmed waveforms
- **Real-time Playback** - Custom vibration patterns
- **Auto-calibration** - Optimizes for connected LRA
- **Operating Voltage** - 3.3V compatible

### **2. Linear Resonant Actuator (LRA)**
**Recommended Models:**
- **Precision Microdrives 310-103** (10mm diameter, 3.4mm height)
- **Jinlong Machinery C1034B013F** (10mm diameter, 3mm height)  
- **Vybronics VG1040003D** (10mm diameter, 4mm height)

**Specifications:**
- **Resonant Frequency:** 150-200Hz
- **Operating Voltage:** 3.3V
- **Current:** 60-100mA peak
- **Force:** 0.7-1.2G

### **3. Tactile Push Buttons (4x)**
- **6x6x5mm tactile switches** - Standard breadboard compatible
- **Actuation Force:** 160gf (1.6N)
- **Travel Distance:** 0.25mm
- **Life Cycle:** 1,000,000+ actuations

## 📋 **Complete Wiring Diagram**

### **ESP32-S3 to DRV2605L Connections:**

```
ESP32-S3    →    DRV2605L Board
--------         --------------
3.3V        →    VCC
GND         →    GND
GPIO21      →    SDA (I2C Data)
GPIO22      →    SCL (I2C Clock)
```

### **DRV2605L to LRA Connections:**

```
DRV2605L    →    LRA (Linear Resonant Actuator)
--------         -------------------------------
OUT+        →    LRA Positive Terminal
OUT-        →    LRA Negative Terminal
```

### **ESP32-S3 to Tactile Buttons:**

```
ESP32-S3    →    Tactile Button
--------         --------------
GPIO14      →    Menu Button (one terminal)
GPIO15      →    Play Button (one terminal)
GPIO16      →    Previous Button (one terminal)
GPIO17      →    Next Button (one terminal)
GND         →    All buttons (other terminal)
```

### **Display Connections (unchanged):**

```
ESP32-S3    →    MSP2806 Display
--------         ---------------
GPIO10      →    CS
GPIO9       →    DC
GPIO8       →    RST
GPIO11      →    SDA/MOSI
GPIO12      →    SCL/SCLK
GPIO13      →    SDO/MISO
3.3V        →    VCC
3.3V        →    LED (backlight)
GND         →    GND
```

## 🔧 **Breadboard Layout**

```
ESP32-S3 DevKit Haptic Layout:

     [USB-C]
   ┌─────────────┐
   │ 3V3     GND │ ← Power rails
   │ EN      IO0 │
   │ IO36    IO1 │
   │ IO37    IO2 │
   │ IO38    IO3 │
   │ IO39    IO4 │
   │ IO40    IO5 │
   │ IO41    IO6 │
   │ IO42    IO7 │
   │ RXD0    IO8 │ ← Display RST
   │ TXD0    IO9 │ ← Display DC
   │ IO44   IO10 │ ← Display CS
   │ IO43   IO11 │ ← Display MOSI
   │ IO44   IO12 │ ← Display SCLK
   │ IO45   IO13 │ ← Display MISO
   │ IO46   IO14 │ ← Menu Button
   │ IO47   IO15 │ ← Play Button
   │ IO48   IO16 │ ← Previous Button
   │        IO17 │ ← Next Button
   │        IO18 │
   │        IO19 │
   │        IO20 │
   │        IO21 │ ← I2C SDA (Haptic)
   │        IO22 │ ← I2C SCL (Haptic)
   │        5V   │
   │        GND  │
   └─────────────┘

DRV2605L Board:
┌─────────────────┐
│ VCC  SCL  SDA   │
│                 │
│    DRV2605L     │
│                 │
│ GND  OUT+ OUT-  │
└─────────────────┘
      │    │
      │    └─── LRA (-)
      └──────── LRA (+)
```

## 🎮 **Haptic Button Layout**

### **Physical Button Arrangement:**
```
    ┌─────────────────────────────────────────────────────────────┐
    │                         Display                             │
    │                      (240x320px)                           │
    │                                                             │
    │                                                             │
    │                                                             │
    │                                                             │
    └─────────────────────────────────────────────────────────────┘
    
           ○ Menu                    Play ○
                                                    
      ○ Previous              [LRA]              Next ○
                         (Center mounted)
```

### **Button Functions:**
- **Menu Button (GPIO14)** - Navigate back/up, main menu
- **Play Button (GPIO15)** - Play/pause current track
- **Previous Button (GPIO16)** - Previous track or navigate up
- **Next Button (GPIO17)** - Next track or navigate down

### **LRA Placement:**
- **Position:** Center of device, between buttons
- **Mounting:** Double-sided tape or small bracket
- **Orientation:** Vibration axis perpendicular to screen
- **Effect:** Whole-device haptic feedback

## 🎵 **Haptic Feedback Patterns**

### **Navigation Feedback:**
```cpp
// Button press confirmation
Effect: Sharp Click 100% (Effect #1)
Duration: 10ms
Intensity: 80%

// Menu navigation
Effect: Soft Bump 100% (Effect #10)  
Duration: 15ms
Intensity: 60%

// Selection confirmation
Effect: Double Click 100% (Effect #2)
Duration: 20ms
Intensity: 90%
```

### **Music Control Feedback:**
```cpp
// Play button
Effect: Strong Click 100% (Effect #1)
Duration: 12ms
Intensity: 100%

// Track change
Effect: Triple Click 100% (Effect #3)
Duration: 30ms
Intensity: 70%

// Volume change
Effect: Soft Fuzz 60% (Effect #15)
Duration: 8ms
Intensity: 50%
```

### **System Feedback:**
```cpp
// Error/invalid action
Effect: Buzz 100% (Effect #47)
Duration: 100ms
Intensity: 60%

// Success/completion
Effect: Pulsing Sharp 100% (Effect #12)
Duration: 50ms
Intensity: 80%

// Low battery warning
Effect: Alert 750ms (Effect #25)
Duration: 750ms
Intensity: 90%
```

## 🔧 **Assembly Instructions**

### **Step 1: Mount DRV2605L Board**
```
1. Place DRV2605L on breadboard
2. Connect power: 3.3V and GND
3. Connect I2C: SDA to GPIO21, SCL to GPIO22
4. Verify connections with multimeter
```

### **Step 2: Install LRA**
```
1. Choose central mounting location
2. Use double-sided foam tape for isolation
3. Connect LRA wires to OUT+ and OUT-
4. Secure wires to prevent fatigue
5. Test LRA movement (should be free)
```

### **Step 3: Install Tactile Buttons**
```
1. Mount 4 buttons in desired layout
2. Connect one side of each to respective GPIO
3. Connect other sides to common GND
4. Test each button with multimeter
```

### **Step 4: Integration Test**
```
1. Upload haptic test code
2. Verify I2C communication with DRV2605L
3. Test each button triggers haptic response
4. Calibrate LRA for optimal performance
5. Adjust feedback intensity as needed
```

## 📊 **Technical Specifications**

### **DRV2605L Features:**
```
I2C Address: 0x5A (default)
Supply Voltage: 2.5V to 5.2V
Output Voltage: Up to 5V
Max Current: 250mA
PWM Frequency: 24.4kHz
Effects Library: 123 built-in waveforms
```

### **Power Consumption:**
```
Idle: 1mA (standby mode)
Active: 60-100mA (during haptic feedback)
Peak: 250mA (maximum output)
Average: 5-10mA (typical usage)
```

### **Performance Characteristics:**
```
Response Time: <5ms (effect start)
Precision: ±1ms timing accuracy
Frequency Range: 50Hz to 300Hz
Force Output: 0.5G to 2.0G (depends on LRA)
```

## 🎯 **Advantages of Haptic Buttons**

### **vs Touch Screen:**
- ✅ **Reliable operation** - No calibration issues
- ✅ **Tactile feedback** - Feel every interaction
- ✅ **Works in all conditions** - No sensitivity problems
- ✅ **Authentic iPod feel** - Physical button experience
- ✅ **Lower power** - No touch controller needed
- ✅ **Precise control** - Exact button mapping

### **vs Rotary Encoder:**
- ✅ **Simpler wiring** - Fewer connections
- ✅ **More intuitive** - Direct button functions
- ✅ **Faster navigation** - Immediate response
- ✅ **Better for music** - Dedicated play controls
- ✅ **Haptic enhancement** - Vibration feedback

## 🛠️ **Troubleshooting**

### **No Haptic Response:**
```
1. Check I2C connections (SDA/SCL)
2. Verify DRV2605L power (3.3V)
3. Test I2C communication (address 0x5A)
4. Check LRA connections (OUT+/OUT-)
5. Verify LRA is not mechanically blocked
```

### **Weak Vibration:**
```
1. Check LRA specifications (resonant frequency)
2. Run auto-calibration routine
3. Increase drive voltage (up to 5V)
4. Verify LRA mounting (should be isolated)
5. Check for loose connections
```

### **Buttons Not Responding:**
```
1. Test button continuity with multimeter
2. Check GPIO pin assignments in code
3. Verify pull-up resistors (internal enabled)
4. Check for short circuits to GND
5. Test individual buttons separately
```

### **Erratic Behavior:**
```
1. Add debouncing delays (50ms minimum)
2. Check power supply stability
3. Verify breadboard connections
4. Add decoupling capacitors (0.1µF)
5. Check for electromagnetic interference
```

## 📦 **Shopping List (India)**

### **Core Components:**
```
1. DRV2605L Haptic Driver Board
   - Robu.in: Not available
   - Alternative: Amazon.in, ElectronicsComp
   - Price: ₹800-1200

2. Linear Resonant Actuator (LRA)
   - Precision Microdrives 310-103
   - Alternative sources: Digi-Key, Mouser (international)
   - Price: ₹300-500

3. Tactile Push Buttons (4x)
   - 6x6x5mm tactile switches
   - Robu.in: Available
   - Price: ₹10-20 each

4. Breadboard & Jumper Wires
   - Standard prototyping supplies
   - Robu.in: Available
   - Price: ₹200-300
```

### **Optional Components:**
```
1. PCB for permanent assembly
2. 3D printed case with haptic mounting
3. Battery pack for portable operation
4. Heat-shrink tubing for wire management
```

This haptic feedback system will give you **authentic iPod-style tactile response** with reliable button operation! The DRV2605L provides professional-grade haptic effects that make every interaction feel premium. 🎯

## 🎵 **Next Steps**

1. **Order components** - DRV2605L + LRA + tactile buttons
2. **Wire breadboard** - Follow the diagram above
3. **Upload haptic code** - Test basic functionality
4. **Integrate with UI** - Add haptic to existing iPod interface
5. **Design 3D case** - Include LRA mounting provisions
6. **Fine-tune effects** - Customize vibration patterns

The haptic approach gives you the **best of both worlds** - reliable physical buttons with modern tactile feedback! 🚀

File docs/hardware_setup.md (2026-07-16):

# Hardware Setup Guide

## Components Required

### Core Components
- ESP32-S3 DevKit (16MB Flash, 8MB PSRAM)
- 2.8" ILI9341 TFT Display (240x320, SPI)
- Capacitive Touch Controller (FT6236 or similar)
- MicroSD Card Module
- Rotary Encoder (KY-040)
- 18650 LiPo Battery (3500mAh)

## USB-C Audio + Charging System

### **Approach 1: USB-C DAC Dongle (Recommended)**
```
ESP32-S3 USB Host → USB-C DAC Dongle → Headphones/Speakers
ESP32-S3 ← USB-C Charging Port ← Power Adapter
```

**Advantages:**
- Simple implementation
- High-quality DAC (24-bit/96kHz)
- Plug-and-play compatibility
- Separate charging and audio ports

### **Approach 2: Single USB-C Port (Advanced)**
```
ESP32-S3 ← USB-C Controller (IP2723T) ← USB-C Port
         ↓                           ↓
    Audio DAC (PCM2912A)        Charging Circuit
```

**Advantages:**
- Single port for everything
- More compact design
- Professional implementation

**Disadvantages:**
- Complex circuit design
- Cannot charge while using wired audio
- Requires USB-C PD controller

## Recommended: Dual USB-C Design

For the best user experience, use **two USB-C ports**:

1. **USB-C Audio Port**: Connect USB-C DAC dongle or USB-C headphones
2. **USB-C Charging Port**: Dedicated charging (can use while listening)

### **Pin Connections (Dual USB-C)**
```
ESP32-S3    USB-C Audio    USB-C Charging
GPIO18  ->  D+ (Data)      -
GPIO19  ->  D- (Data)      -
GPIO20  ->  VBUS_DETECT    -
-       ->  -              VBUS (5V)
-       ->  -              GND
GPIO21  ->  -              CHG_STATUS
```

## Pin Connections

### Display + Touch Pins (Test Required)
```
ESP32-S3    ILI9341
GPIO10  ->  CS (Display)
GPIO9   ->  DC
GPIO8   ->  RST
GPIO11  ->  MOSI (SDI)
GPIO12  ->  SCLK (SCK)
GPIO13  ->  MISO (SDO)
3.3V    ->  VCC
GND     ->  GND
GPIO2   ->  LED (Backlight)

# Touch Pins (if functional - test required)
GPIO6   ->  T_CS
GPIO7   ->  T_CLK  
GPIO5   ->  T_DIN
GPIO4   ->  T_DO
GPIO3   ->  T_IRQ (optional)
```

**Note**: Label says "Touch: N" but pins are present. Test to confirm if touch controller is actually populated and functional.

### SD Card (SPI)
```
ESP32-S3    SD Card
GPIO35  ->  CS
GPIO36  ->  MOSI
GPIO37  ->  MISO
GPIO38  ->  SCLK
3.3V    ->  VCC
GND     ->  GND
```

### Rotary Encoder
```
ESP32-S3    Encoder
GPIO1   ->  CLK
GPIO2   ->  DT
GPIO3   ->  SW
3.3V    ->  VCC
GND     ->  GND
```

### USB-C Audio Port
```
ESP32-S3    USB-C Audio
GPIO18  ->  D+ (Data)
GPIO19  ->  D- (Data)  
GPIO20  ->  VBUS_DETECT
GPIO17  ->  AUDIO_ENABLE
5V      ->  VBUS
GND     ->  GND
```

### USB-C Charging Port
```
ESP32-S3    USB-C Charge
GPIO21  ->  CHG_STATUS
GPIO39  ->  POWER_ENABLE
5V      ->  VBUS (to TP4056)
GND     ->  GND
```

### Power Management
```
ESP32-S3    Power
GPIO22  ->  Battery ADC
3.3V    ->  System Power
GND     ->  System Ground
```

## Assembly Notes

1. **Power Supply**: Use 3.3V for logic, 5V for display backlight
2. **Decoupling**: Add 100nF capacitors near each IC
3. **Pull-ups**: I2C lines need 4.7kΩ pull-ups
4. **Audio**: Keep audio traces short and away from digital signals
5. **Shielding**: Consider copper pour for ground plane

## Case Design

- 3D printable case with access to:
  - **Two USB-C ports** (Audio + Charging)
  - SD card slot
  - Rotary encoder
  - Power button
- Display window with touch access (if functional)
- Battery compartment
- Ventilation for heat dissipation
- **No 3.5mm jack needed** - USB-C audio only

## Testing Checklist

- [ ] Power rails (3.3V, 5V)
- [ ] Display initialization
- [ ] Touch response
- [ ] SD card detection
- [ ] Rotary encoder rotation/click
- [ ] Audio output
- [ ] Battery charging
- [ ] USB-C connection
- [ ] Bluetooth pairing

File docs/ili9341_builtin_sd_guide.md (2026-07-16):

# 🎴 ILI9341 Built-in SD Card Slot Guide

## 📌 What is This?

Many ILI9341 display modules (including MSP2806) have a **built-in microSD card slot** on the back. This is much better than using a separate SD module because:

✅ **Shares the same SPI bus** - No conflicts!  
✅ **Fewer wires** - Just one extra CS pin  
✅ **More reliable** - Designed to work together  
✅ **Saves space** - No separate module needed  

---

## 🔍 Step 1: Check Your Display

### Look at the Back of Your MSP2806 Display

```
Front (Screen Side):          Back (Component Side):
┌─────────────────┐          ┌─────────────────┐
│                 │          │  [SD Card Slot] │ ← Look for this!
│                 │          │   ┌─────────┐   │
│     Screen      │          │   │ ▼ ▼ ▼ ▼ │   │
│                 │          │   └─────────┘   │
│                 │          │                 │
└─────────────────┘          │  Pin Headers    │
  │││││││││││││││            │  │││││││││││││  │
  └─────────────┘            └─────────────────┘
```

### What to Look For:

1. **MicroSD Card Slot** - Small slot that fits a microSD card
2. **SD_CS Pin** - Extra pin labeled one of these:
   - `SD_CS`
   - `SDCS`
   - `CS_SD`
   - `SD-CS`
   - Sometimes just `CS` (separate from TFT_CS)

### Common ILI9341 Module Types:

**Type A: Separate SD_CS Pin**
```
Display Pins:
VCC  GND  CS  RST  DC  MOSI  SCK  MISO  LED  [SD_CS]
                                                 ↑
                                        Extra pin for SD!
```

**Type B: SD_CS on Pin Header**
```
Main Pins:          Extra Pins:
VCC  GND  CS        SD_CS
RST  DC   MOSI      (or SDCS)
SCK  MISO LED
```

**Type C: No Built-in SD**
```
Only these pins:
VCC  GND  CS  RST  DC  MOSI  SCK  MISO  LED
(No SD slot on back)
```

---

## 🔌 Step 2: Wiring

### If Your Display HAS Built-in SD Slot:

**Current Wiring (Already Connected):**
```
Display Pin    ESP32-S3 Pin
-----------    ------------
VCC            3.3V
GND            GND
CS             GPIO10
RST            GPIO8
DC             GPIO9
MOSI           GPIO11
SCK            GPIO12
MISO           GPIO13
LED            3.3V
```

**Add ONE More Wire:**
```
SD_CS          GPIO4  ← Add this!
```

### Visual Diagram:

```
ESP32-S3                    MSP2806 Display (Back View)
┌──────────┐               ┌─────────────────────────┐
│          │               │   [MicroSD Card Slot]   │
│  GPIO4 ──┼───────────────┼→ SD_CS pin              │
│  GPIO8 ──┼───────────────┼→ RST                    │
│  GPIO9 ──┼───────────────┼→ DC                     │
│  GPIO10 ─┼───────────────┼→ CS (TFT)               │
│  GPIO11 ─┼───────────────┼→ MOSI (shared)          │
│  GPIO12 ─┼───────────────┼→ SCK (shared)           │
│  GPIO13 ─┼───────────────┼→ MISO (shared)          │
│  3.3V ───┼───────────────┼→ VCC                    │
│  GND ────┼───────────────┼→ GND                    │
└──────────┘               └─────────────────────────┘
```

---

## 🧪 Step 3: Run the Test

### Upload the Test Code

1. Open `src/ili9341_builtin_sd_test.cpp`
2. Upload to your ESP32-S3
3. Open Serial Monitor (115200 baud)

### What the Test Does:

```
1. Tries GPIO4 first (most common)
   ├─ If works → Success! Use GPIO4
   └─ If fails → Try GPIO5

2. Tries GPIO5 (alternative)
   ├─ If works → Success! Use GPIO5
   └─ If fails → No built-in SD slot
```

### Expected Output (Success):

```
╔════════════════════════════════════════╗
║   ILI9341 Built-in SD Card Test       ║
╚════════════════════════════════════════╝

📌 Testing SD card slot on display module
   SD_CS: GPIO4 (trying first)
   Shared SPI with display

━━━━━━━━━━━━━━━━━━━━━━━━━━━━━━━━━━━━━━━━
TEST 1: SD Card on GPIO4
━━━━━━━━━━━━━━━━━━━━━━━━━━━━━━━━━━━━━━━━
Trying CS pin: GPIO4
Initializing... ✅ Detected!
📇 Type: SDHC
💾 Size: 15200 MB
📊 Used: 374 MB / 15200 MB
📝 Testing write... ✅
📖 Testing read... ILI9341 SD Test
✅

✅ SUCCESS! SD card works on GPIO4
```

### Expected Output (No Built-in SD):

```
❌ SD card not detected on GPIO4 or GPIO5

🔍 Possible issues:
   1. Your ILI9341 module doesn't have SD slot
   2. SD card not inserted in display module
   3. SD_CS pin is different (check module label)
   4. Need to connect SD_CS wire to ESP32
```

---

## 📋 Troubleshooting

### Problem: "SD card not detected"

**Check 1: Is there an SD slot?**
- Look at the back of the display
- Some ILI9341 modules don't have SD slots

**Check 2: Is the SD card inserted?**
- Insert into the **display module**, not a separate SD module
- Push until it clicks

**Check 3: Is SD_CS connected?**
- Find the SD_CS pin on your display
- Connect it to GPIO4 on ESP32

**Check 4: Try different CS pins**
- Some modules use GPIO5 instead of GPIO4
- The test tries both automatically

**Check 5: SD card format**
- Must be FAT32 (not exFAT)
- 32GB or smaller (SDHC)

---

## ✅ If Built-in SD Works

### Update Your Complete System Code

Change the SD_CS pin in your code:

```cpp
// OLD (separate SD module):
#define SD_CS 5

// NEW (built-in SD on display):
#define SD_CS 4  // or GPIO5 if that's what worked
```

### Benefits:

✅ **No SPI conflicts** - Display and SD designed to work together  
✅ **Simpler wiring** - Just one extra wire  
✅ **More reliable** - Tested by manufacturer  
✅ **Saves space** - No separate SD module needed  

---

## ❌ If No Built-in SD Slot

### Option 1: Use Demo Mode (Recommended for Now)

Use `src/ipod_no_sd.cpp` which has:
- 9 demo songs built-in
- Full UI working
- No SD card needed
- Perfect for testing and development

### Option 2: Wait for PCB Design

When you design the PCB, you can:
- Use a dedicated SPI bus for SD card
- Add proper level shifters
- Design for reliability

### Option 3: Try SDMMC Mode (Advanced)

ESP32-S3 has a 4-bit SDMMC interface that's faster and more reliable than SPI. This requires different wiring and is better suited for PCB design.

---

## 🎯 Next Steps

### If Built-in SD Works:

1. ✅ Run `ili9341_builtin_sd_test.cpp`
2. ✅ Note which GPIO works (4 or 5)
3. ✅ Update `complete_ipod_system.cpp` with correct SD_CS pin
4. ✅ Test complete system with real music files
5. ✅ Add audio playback (I2S DAC)

### If No Built-in SD:

1. ✅ Use `ipod_no_sd.cpp` for now (demo mode)
2. ✅ Continue developing UI and features
3. ✅ Plan for PCB design with proper SD support
4. ✅ Consider SDMMC interface for final design

---

## 📸 Photo Guide

### What to Photograph:

1. **Back of your display** - Show the SD slot (if present)
2. **Pin labels** - Show all pin names clearly
3. **SD_CS pin** - Close-up of the SD_CS pin location

This will help identify your exact module type!

---

## 💡 Pro Tips

1. **Built-in SD is better** - Always use it if available
2. **GPIO4 is most common** - Try this first
3. **Check both sides** - Some modules have pins on both sides
4. **Read the labels** - Pin names are usually printed on PCB
5. **Demo mode works great** - Don't wait for SD to continue development

---

## 🔗 Related Files

- `src/ili9341_builtin_sd_test.cpp` - Test code (run this first!)
- `src/ipod_no_sd.cpp` - Demo mode without SD
- `src/complete_ipod_system.cpp` - Full system (needs SD_CS update)
- `docs/sd_card_troubleshooting.md` - General SD troubleshooting

---

**Ready to test? Upload `ili9341_builtin_sd_test.cpp` and let's see if your display has a built-in SD slot!** 🎴

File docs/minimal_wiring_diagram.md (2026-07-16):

# Minimal iPod Wiring - Pure Touch Interface

## Ultra-Clean System Layout

```
                    ┌─────────────────────────────────────────┐
                    │           ESP32-S3-N16R8                │
                    │                                         │
                    │  ┌─────┐                               │
                    │  │USB-C│  ← Built-in USB for programming│
                    │  └─────┘     & power during development │
                    │                                         │
    ┌───────────────┼─ GPIO10 (TFT_CS)                       │
    │   ┌───────────┼─ GPIO9  (TFT_DC)                       │
    │   │   ┌───────┼─ GPIO8  (TFT_RST)                      │
    │   │   │   ┌───┼─ GPIO11 (TFT_MOSI)                     │
    │   │   │   │ ┌─┼─ GPIO12 (TFT_SCLK)                     │
    │   │   │   │ │ └─ GPIO13 (TFT_MISO) [optional]          │
    │   │   │   │ │                                           │
    │   │   │   │ │   ┌───────┼─ GPIO6  (TOUCH_CS)           │
    │   │   │   │ │   │   ┌───┼─ GPIO7  (TOUCH_CLK)          │
    │   │   │   │ │   │   │ ┌─┼─ GPIO5  (TOUCH_DIN)          │
    │   │   │   │ │   │   │ │ └─ GPIO4  (TOUCH_DO)           │
    │   │   │   │ │   │   │ │                                 │
    │   │   │   │ │   │   │ │   ┌───────┼─ GPIO35 (SD_CS)    │
    │   │   │   │ │   │   │ │   │   ┌───┼─ GPIO36 (SD_MOSI)  │
    │   │   │   │ │   │   │ │   │   │ ┌─┼─ GPIO37 (SD_MISO)  │
    │   │   │   │ │   │   │ │   │   │ │ └─ GPIO38 (SD_SCLK)  │
    │   │   │   │ │   │   │ │   │   │ │                       │
    │   │   │   │ │   │   │ │   │   │ │ ┌─────────┼─ 3.3V     │
    │   │   │   │ │   │   │ │   │   │ │ │     ┌───┼─ GND      │
    └───┼───┼───┼─┼───┼───┼─┼───┼───┼─┼─┼─────┼───┼───────────┘
        │   │   │ │   │   │ │   │   │ │ │     │   │
        │   │   │ │   │   │ │   │   │ │ │     │   │
    ┌───▼───▼───▼─▼───▼───▼─▼───┐   │ │ │     │   │
    │                            │   │ │ │     │   │
    │  MSP2806 - 2.8" Display   │   │ │ │     │   │
    │  ┌─────────────────────┐   │   │ │ │     │   │
    │  │                     │   │   │ │ │     │   │
    │  │     240 x 320       │   │   │ │ │     │   │
    │  │                     │   │   │ │ │     │   │
    │  │  🎵 Pure Touch iPod │   │   │ │ │     │   │
    │  │                     │   │   │ │ │     │   │
    │  │  ✋ Tap to Control   │   │   │ │ │     │   │
    │  │  👆 Swipe to Browse │   │   │ │ │     │   │
    │  │  🎶 Long Press Menu │   │   │ │ │     │   │
    │  │                     │   │   │ │ │     │   │
    │  └─────────────────────┘   │   │ │ │     │   │
    │                            │   │ │ │     │   │
    │ ILI9341 Display Pins:      │   │ │ │     │   │
    │ CS DC RST MOSI SCLK MISO   │   │ │ │     │   │
    │ │  │  │   │    │    │      │   │ │ │     │   │
    │                            │   │ │ │     │   │
    │ XPT2046 Touch Pins:        │   │ │ │     │   │
    │ T_CS T_CLK T_DIN T_DO      │   │ │ │     │   │
    │ │    │     │     │         │   │ │ │     │   │
    └─┼────┼─────┼─────┼─────────┘   │ │ │     │   │
      │    │     │     │             │ │ │     │   │
      └────┼─────┼─────┼─────────────┘ │ │     │   │
           └─────┼─────┼───────────────┘ │     │   │
                 └─────┼─────────────────┘     │   │
                       └───────────────────────┘   │
                                                   │
                       ┌───────────────────────────┘
                       │
                   ┌───▼───────┐
                   │ MicroSD   │
                   │ Module    │
                   │           │
                   │ 💾 256GB  │
                   │ Music     │
                   │ Library   │
                   │           │
                   └───────────┘
```

## Component Count: Just 3 Modules!

### 1. 🧠 ESP32-S3-N16R8 DevKit
- **Function**: Main controller, WiFi, Bluetooth, USB
- **Pins Used**: 18 out of 45 available
- **Power**: 3.3V from USB or battery

### 2. 📱 MSP2806 Display (You Own This!)
- **Function**: 240x320 color display + touch controller
- **Controllers**: ILI9341 (display) + XPT2046 (touch)
- **Interface**: Dual SPI (shared MOSI/SCLK)
- **Power**: 3.3V, ~50mA

### 3. 💾 MicroSD Module
- **Function**: Music storage (up to 256GB)
- **Interface**: SPI
- **Power**: 3.3V, ~10mA

## Wiring Tables

### 🔌 Power Distribution
```
Source      →    Destination    →    Current
ESP32 3.3V  →    Display VCC    →    50mA
ESP32 3.3V  →    Display LED    →    20mA  
ESP32 3.3V  →    SD Module      →    10mA
ESP32 GND   →    All GND pins   →    Return path
```

### 📺 Display Connections (11 wires)
```
ESP32-S3    Color      MSP2806    Function
GPIO10   →  Orange  →  CS      →  Display Select
GPIO9    →  Yellow  →  DC      →  Data/Command
GPIO8    →  Green   →  RST     →  Reset
GPIO11   →  Blue    →  SDA     →  Data (MOSI)
GPIO12   →  Purple  →  SCL     →  Clock (SCLK)
GPIO13   →  Gray    →  SDO     →  Data Out (MISO) [optional]
GPIO6    →  White   →  T_CS    →  Touch Select
GPIO7    →  Brown   →  T_CLK   →  Touch Clock
GPIO5    →  Pink    →  T_DIN   →  Touch Data In
GPIO4    →  Cyan    →  T_DO    →  Touch Data Out
3.3V     →  Red     →  VCC     →  Power
3.3V     →  Red     →  LED     →  Backlight
GND      →  Black   →  GND     →  Ground
```

### 💾 SD Card Connections (6 wires)
```
ESP32-S3    Color      SD Module   Function
GPIO35   →  Orange  →  CS       →  Chip Select
GPIO36   →  Blue    →  MOSI     →  Data Out
GPIO37   →  Purple  →  MISO     →  Data In
GPIO38   →  Yellow  →  SCLK     →  Clock
3.3V     →  Red     →  VCC      →  Power
GND      →  Black   →  GND      →  Ground
```

## Touch Interface Design

### 🎵 Music Control Gestures
```
Gesture          Action              Visual Feedback
Tap           →  Play/Pause       →  ⏯️ Button highlight
Swipe Left    →  Next Track       →  ⏭️ Slide animation
Swipe Right   →  Previous Track   →  ⏮️ Slide animation
Swipe Up      →  Volume Up        →  🔊 Volume bar
Swipe Down    →  Volume Down      →  🔉 Volume bar
Long Press    →  Context Menu     →  📋 Menu popup
Double Tap    →  Like/Favorite    →  ❤️ Heart animation
```

### 📱 Navigation Gestures
```
Screen           Gesture          Action
Home          →  Tap Album     →  Open album
Library       →  Swipe Up      →  Scroll up
Now Playing   →  Pinch Out     →  Full screen art
Settings      →  Swipe Right   →  Go back
Any Screen    →  Edge Swipe    →  Quick menu
```

## Benefits of This Design

### ✅ Advantages
- **Minimal Components**: Only 3 modules total
- **Single Display**: Built-in touch eliminates extra controller
- **Zero Buttons**: Pure touch interface
- **Maximum Simplicity**: Easiest possible wiring
- **Cost Effective**: Saves ₹200+ on unnecessary components
- **Modern UX**: Smartphone-like experience
- **Reliable**: Fewer connections = fewer failure points

### 🎯 Perfect For
- **Music Lovers**: Focus on the music, not the controls
- **Minimalists**: Clean, button-free design
- **Beginners**: Simple wiring, fewer mistakes
- **Portability**: Compact, lightweight design
- **Future-Proof**: Touch interface never goes out of style

### 🚀 Expansion Possibilities
With 27 GPIO pins still available, you can add:
- **Accelerometer**: Shake to shuffle
- **Ambient Light**: Auto brightness
- **Wireless Charging**: Qi charging pad
- **RGB LEDs**: Music visualization
- **Haptic Feedback**: Touch vibration

This is the ultimate minimalist iPod - just your ESP32-S3, your existing display, and an SD card. Pure simplicity, maximum functionality!

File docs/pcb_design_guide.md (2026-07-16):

# ESP32-S3 iPod PCB Design Guide

## 🎯 **PCB Overview**

Creating a custom PCB for your haptic iPod will provide:
- **Professional finish** - Clean, compact design
- **Reliable connections** - No loose breadboard wires
- **Easier assembly** - All components in fixed positions
- **Better performance** - Shorter traces, less noise
- **Production ready** - Can make multiple units

## 🔧 **PCB Design Software Options**

### **Free Options (Recommended for Beginners)**

#### **1. KiCad (Best Free Option)**
```
✅ Completely free and open source
✅ Professional-grade features
✅ Large component library
✅ Active community support
✅ Cross-platform (Windows, Mac, Linux)
✅ No size limitations

Download: kicad.org
Learning curve: Medium
Best for: Serious hobbyists and professionals
```

#### **2. EasyEDA (Web-based)**
```
✅ Browser-based (no installation)
✅ Integrated with JLCPCB manufacturing
✅ Large component library
✅ Real-time collaboration
✅ Direct PCB ordering

Website: easyeda.com
Learning curve: Easy
Best for: Quick prototypes and beginners
```

#### **3. Fusion 360 Electronics (Free for Personal)**
```
✅ Integrated with mechanical design
✅ 3D visualization
✅ Professional features
✅ Free for personal use

Website: autodesk.com/products/fusion-360
Learning curve: Medium-Hard
Best for: Integrated mechanical + electrical design
```

### **Paid Options**

#### **4. Altium Designer (Professional)**
```
✅ Industry standard
✅ Advanced features
✅ Excellent libraries
❌ Expensive (~$7,000/year)

Best for: Professional development
```

#### **5. Eagle (Autodesk)**
```
✅ Popular hobbyist choice
✅ Good community
❌ Size limitations in free version
❌ Subscription model

Best for: Small hobby projects
```

## 📐 **PCB Specifications for iPod Project**

### **Board Dimensions**
```
PCB Size: 100mm x 60mm (fits in iPod case)
Thickness: 1.6mm (standard)
Layers: 2-layer (Top + Bottom)
Material: FR4 (standard fiberglass)
Copper Weight: 1oz (35μm)
```

### **Component Layout**
```
Top Side:
- ESP32-S3 module (or socket)
- DRV2605L haptic driver
- 4x tactile buttons
- Display connector
- Power management components

Bottom Side:
- Decoupling capacitors
- Pull-up resistors
- LED indicators
- Test points
```

## 🎨 **Schematic Design**

### **Main Circuit Blocks**

#### **1. ESP32-S3 Core**
```
ESP32-S3-WROOM-1 Module:
- Power: 3.3V rail with decoupling caps
- Reset circuit: Button + RC network
- Boot circuit: Button + pull-up
- USB-C connector for programming/power
- Crystal: Usually integrated in module
```

#### **2. Display Interface**
```
ILI9341 SPI Connection:
ESP32-S3    PCB Net    Display Pin
GPIO10  →   TFT_CS  →  CS
GPIO9   →   TFT_DC  →  DC  
GPIO8   →   TFT_RST →  RST
GPIO11  →   SPI_MOSI→  SDA
GPIO12  →   SPI_CLK →  SCL
GPIO13  →   SPI_MISO→  SDO
3.3V    →   VCC     →  VCC
3.3V    →   LED     →  LED
GND     →   GND     →  GND
```

#### **3. Haptic Feedback System**
```
DRV2605L I2C Connection:
ESP32-S3    PCB Net    DRV2605L Pin
GPIO21  →   I2C_SDA →  SDA
GPIO22  →   I2C_SCL →  SCL
3.3V    →   VCC     →  VIN
GND     →   GND     →  GND

LRA Connection:
DRV2605L    PCB Net    LRA
OUT+    →   LRA_P   →  Positive
OUT-    →   LRA_N   →  Negative
```

#### **4. Button Interface**
```
Tactile Buttons with Pull-ups:
ESP32-S3    PCB Net    Button    Pull-up
GPIO14  →   BTN_MENU→  Pin1  →   3.3V (10kΩ)
GPIO15  →   BTN_PLAY→  Pin1  →   3.3V (10kΩ)
GPIO16  →   BTN_PREV→  Pin1  →   3.3V (10kΩ)
GPIO17  →   BTN_NEXT→  Pin1  →   3.3V (10kΩ)
GND     →   GND     →  Pin2  →   GND
```

#### **5. Power Management**
```
Power Input Options:
- USB-C: 5V input with 3.3V regulator
- Battery: 3.7V LiPo with charging circuit
- External: 5V barrel jack (optional)

3.3V Rail:
- AMS1117-3.3 regulator (or similar)
- Input/output capacitors
- Power LED indicator
- Ferrite bead for noise filtering
```

### **Component Values**
```
Decoupling Capacitors:
- 100nF ceramic (0805) - Near each IC
- 10μF tantalum (1206) - Power rails
- 1μF ceramic (0805) - General purpose

Pull-up Resistors:
- 10kΩ (0805) - Button pull-ups
- 4.7kΩ (0805) - I2C pull-ups

Power Components:
- AMS1117-3.3 (SOT-223) - 3.3V regulator
- 220μF electrolytic - Input capacitor
- 100μF electrolytic - Output capacitor

LEDs:
- Power LED: Green 0805
- Status LED: Blue 0805
- Current limiting: 330Ω (0805)
```

## 🖥️ **PCB Layout Guidelines**

### **Layer Stack-up (2-layer)**
```
Layer 1 (Top):
- Component placement
- Signal traces
- Power traces (wide)
- Ground fills

Layer 2 (Bottom):
- Ground plane (mostly)
- Return paths
- Some signal routing
- Component placement (small parts)
```

### **Trace Width Guidelines**
```
Power Traces:
- 3.3V rail: 0.5mm minimum (20mil)
- 5V rail: 0.4mm minimum (16mil)
- USB data: 0.2mm (8mil) differential pair

Signal Traces:
- Digital I/O: 0.2mm (8mil)
- SPI signals: 0.2mm (8mil)
- I2C signals: 0.2mm (8mil)

Ground:
- Ground plane on bottom layer
- Ground fills on top layer
- Via stitching every 5mm
```

### **Component Placement Rules**
```
Critical Placement:
1. ESP32-S3 module: Center of board
2. DRV2605L: Near ESP32-S3 for short I2C traces
3. Decoupling caps: As close as possible to IC pins
4. Buttons: Arranged for case mounting holes
5. Connectors: At board edges

Keep Away:
- Crystal from switching circuits
- Analog circuits from digital switching
- Power regulators from sensitive circuits
```

### **Design Rules Check (DRC)**
```
Minimum Values:
- Trace width: 0.15mm (6mil)
- Via size: 0.2mm (8mil)
- Drill size: 0.1mm (4mil)
- Clearance: 0.15mm (6mil)
- Annular ring: 0.05mm (2mil)

Recommended:
- Trace width: 0.2mm (8mil)
- Via size: 0.3mm (12mil)
- Clearance: 0.2mm (8mil)
```

## 🔌 **Connector and Mounting**

### **Connectors**
```
Display Connector:
- 2.54mm pitch header (9-pin)
- Or FFC connector for flat cable
- Keyed to prevent reverse insertion

Programming:
- USB-C connector (USB 2.0)
- ESD protection diodes
- Ferrite beads on data lines

External:
- 2-pin JST for battery (optional)
- 3-pin header for serial debug
```

### **Mounting Holes**
```
PCB Mounting:
- 4x M2.5 holes at corners
- 3mm diameter holes
- 2mm keepout around holes
- Grounded via stitching nearby

Component Mounting:
- ESP32-S3: Castellated pads or socket
- DRV2605L: SMD footprint or breakout socket
- Buttons: Through-hole mounting
- Display: Header or FFC connector
```

## 🏭 **PCB Manufacturing in India**

### **Indian PCB Manufacturers**

#### **1. JLCPCB (Chinese, ships to India)**
```
✅ Cheapest option: $2-5 for 5 PCBs
✅ Fast turnaround: 2-3 days production
✅ Good quality: Professional finish
✅ Assembly service: SMT components
✅ Integrated with EasyEDA

Shipping to India: 7-15 days
Total cost: ₹500-1000 for 5 PCBs
Website: jlcpcb.com
```

#### **2. PCBWay (Chinese, ships to India)**
```
✅ Good quality: Reliable manufacturing
✅ Assembly service: Full SMT line
✅ Prototyping: Quick turnaround
✅ Support: Good customer service

Shipping to India: 7-15 days  
Total cost: ₹800-1500 for 5 PCBs
Website: pcbway.com
```

#### **3. Indian Manufacturers**

**Circuits Today (Bangalore)**
```
✅ Local: No customs/shipping delays
✅ Support: Direct communication
✅ Quick delivery: 3-5 days in India
❌ Higher cost: ₹1500-3000 for 5 PCBs

Website: circuitstoday.com
Contact: Bangalore-based
```

**Sunstream Circuits (Mumbai)**
```
✅ Professional: Industrial quality
✅ Local support: Indian company
✅ Fast delivery: Within India
❌ Higher cost: ₹2000-4000 for 5 PCBs

Website: sunstreamcircuits.com
```

**Twisted Traces (Delhi)**
```
✅ Prototyping focus: Good for small runs
✅ Local: Delhi-based
✅ Educational discounts: For students
❌ Limited capacity: Small quantities only

Website: twistedtraces.com
```

### **Cost Comparison (5 PCBs, 100x60mm)**
```
JLCPCB:        ₹500-800   (7-15 days)
PCBWay:        ₹800-1200  (7-15 days)
Circuits Today: ₹1500-2500 (3-5 days)
Sunstream:     ₹2000-3500 (3-5 days)
Twisted Traces: ₹1200-2000 (5-7 days)
```

## 📋 **PCB Design Process**

### **Step 1: Schematic Design (1-2 days)**
```
1. Create new project in KiCad/EasyEDA
2. Add ESP32-S3 symbol and footprint
3. Add all other components (DRV2605L, buttons, etc.)
4. Connect nets according to wiring diagram
5. Add power symbols and decoupling
6. Run Electrical Rules Check (ERC)
7. Generate netlist
```

### **Step 2: PCB Layout (2-3 days)**
```
1. Import netlist to PCB editor
2. Place components logically
3. Route critical signals first (power, clock)
4. Route remaining signals
5. Add ground plane/fills
6. Add silkscreen labels
7. Run Design Rules Check (DRC)
8. Generate 3D view for verification
```

### **Step 3: Manufacturing Files (1 day)**
```
1. Generate Gerber files (RS-274X format)
2. Generate Excellon drill files
3. Generate pick-and-place files (if assembly)
4. Generate Bill of Materials (BOM)
5. Create assembly drawings
6. Zip all files for manufacturer
```

### **Step 4: Order PCBs (1 day)**
```
1. Upload Gerber files to manufacturer
2. Review PCB preview carefully
3. Select options (color, thickness, etc.)
4. Place order and pay
5. Track production and shipping
```

## 🎨 **PCB Design Tips**

### **Beginner-Friendly Approach**
```
Start Simple:
1. Use larger components (0805 vs 0603)
2. Wider traces (0.3mm vs 0.2mm)
3. More spacing between components
4. Single-sided assembly if possible
5. Through-hole components where feasible

Test First:
1. Breadboard the circuit completely
2. Verify all connections work
3. Test with actual components
4. Only then design PCB
```

### **Professional Touches**
```
Silkscreen:
- Component reference designators
- Pin 1 indicators
- Polarity markings
- Version number and date
- Your name/logo

Solder Mask:
- Green is standard and cheapest
- Other colors available (blue, red, black)
- Matte finish for premium look

Surface Finish:
- HASL (Hot Air Solder Leveling) - Standard
- ENIG (Gold) - Premium, better for fine pitch
- OSP - Good for prototypes
```

## 🔧 **Assembly Process**

### **DIY Assembly (Hand Soldering)**
```
Tools Needed:
- Soldering iron (temperature controlled)
- Solder (0.6mm rosin core)
- Flux (liquid or paste)
- Tweezers (fine tip)
- Magnifying glass/microscope
- Desoldering braid
- Isopropyl alcohol (cleaning)

Assembly Order:
1. SMD components (smallest first)
2. Through-hole components
3. Connectors and mechanical parts
4. Final cleaning and inspection
```

### **Professional Assembly**
```
SMT Assembly Services:
- JLCPCB: $10-30 setup + component costs
- PCBWay: $15-40 setup + component costs
- Local: ₹500-1500 setup + components

Benefits:
✅ Perfect solder joints
✅ Faster assembly
✅ No hand-soldering errors
✅ Professional finish

Requirements:
- Pick-and-place files
- Bill of Materials (BOM)
- Component sourcing
```

## 📦 **Complete PCB Package**

### **Files to Create**
```
Design Files:
- Schematic (PDF)
- PCB layout (PDF)
- 3D renderings
- Component placement drawing

Manufacturing:
- Gerber files (all layers)
- Excellon drill files
- Pick-and-place files
- Bill of Materials (Excel/CSV)

Documentation:
- Assembly instructions
- Test procedures
- User manual
```

### **Version Control**
```
File Naming:
- iPod_Haptic_v1.0_Schematic.pdf
- iPod_Haptic_v1.0_PCB.pdf
- iPod_Haptic_v1.0_Gerbers.zip
- iPod_Haptic_v1.0_BOM.xlsx

Revision Tracking:
- v1.0: Initial design
- v1.1: Bug fixes
- v2.0: Major changes
```

## 🎯 **Recommended Workflow for Your Project**

### **Phase 1: Learn PCB Design (1 week)**
```
Day 1-2: Install KiCad, complete tutorials
Day 3-4: Practice with simple LED circuit
Day 5-7: Design your iPod schematic
```

### **Phase 2: PCB Layout (1 week)**
```
Day 1-3: Component placement and routing
Day 4-5: Design rule checks and optimization
Day 6-7: Generate manufacturing files
```

### **Phase 3: Manufacturing (2-3 weeks)**
```
Week 1: Order PCBs from JLCPCB
Week 2-3: Shipping and customs (if international)
Week 3: Receive PCBs and assemble
```

### **Phase 4: Testing and Iteration**
```
Day 1: Assemble first PCB
Day 2-3: Test all functions
Day 4-7: Debug and fix issues
Repeat: Order v1.1 if needed
```

## 💰 **Total PCB Project Cost**

### **Design Phase (DIY)**
```
Software: Free (KiCad)
Learning time: 1-2 weeks
Design time: 1 week
Total cost: ₹0 (just your time)
```

### **Manufacturing Phase**
```
PCB fabrication (5 pcs): ₹500-800
Component costs: ₹1500-2000
Assembly (if outsourced): ₹500-1500
Shipping: ₹200-500

Total: ₹2,700-4,800 for 5 complete PCBs
```

### **Per Unit Cost (after setup)**
```
PCB: ₹100-160 each
Components: ₹300-400 each
Assembly: ₹100-300 each (if outsourced)

Total per unit: ₹500-860 each
```

This makes your iPod project **production-ready** and gives you a professional finish that's much more reliable than breadboard prototypes! 🚀

The PCB approach is definitely worth it for a project like this - you'll get better performance, easier assembly, and a much more professional result. Start with KiCad (free) and JLCPCB (cheap) for the best learning experience.

Would you like me to create the actual schematic and PCB layout files for your haptic iPod project?

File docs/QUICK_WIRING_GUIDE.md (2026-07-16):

# ⚡ QUICK WIRING GUIDE - ESP32-S3 iPod

## 🔌 **Super Simple Connections**

### **You Need:**
- ESP32-S3 DevKit
- TTP229 16-Key Touch Module  
- MSP2806 Display (2.8" ILI9341)
- 13 jumper wires

---

## 📋 **TTP229 Touch Module (4 wires)**

```
TTP229 Pin    →    ESP32-S3 Pin    Wire Color
----------         ------------    ----------
VCC           →    3.3V            Red
GND           →    GND             Black
SCL           →    GPIO2           Yellow
SDO           →    GPIO1           Green
```

**Important:** GPIO1 and GPIO2 are the correct I2C pins for ESP32-S3!

---

## 📋 **MSP2806 Display (9 wires)**

```
Display Pin   →    ESP32-S3 Pin    Wire Color
-----------        ------------    ----------
VCC           →    3.3V            Red
GND           →    GND             Black
CS            →    GPIO10          Orange
RST           →    GPIO8           White
DC            →    GPIO9           Gray
SDA/MOSI      →    GPIO11          Blue
SCL/SCLK      →    GPIO12          Purple
SDO/MISO      →    GPIO13          Brown
LED           →    3.3V            Red
```

---

## 🎨 **Visual Guide**

```
ESP32-S3 DevKit Pinout:

        [USB-C Port]
    ┌──────────────────┐
    │                  │
    │  3.3V ●──────────┼─── TTP229 VCC (Red)
    │                  │    Display VCC (Red)
    │                  │    Display LED (Red)
    │                  │
    │  GND  ●──────────┼─── TTP229 GND (Black)
    │                  │    Display GND (Black)
    │                  │
    │  IO1  ●──────────┼─── TTP229 SDO (Green)
    │  IO2  ●──────────┼─── TTP229 SCL (Yellow)
    │                  │
    │  IO8  ●──────────┼─── Display RST (White)
    │  IO9  ●──────────┼─── Display DC (Gray)
    │  IO10 ●──────────┼─── Display CS (Orange)
    │  IO11 ●──────────┼─── Display SDA (Blue)
    │  IO12 ●──────────┼─── Display SCL (Purple)
    │  IO13 ●──────────┼─── Display SDO (Brown)
    │                  │
    └──────────────────┘
```

---

## ✅ **Quick Checklist**

Before powering on, verify:

**TTP229:**
- [ ] VCC → 3.3V (NOT 5V!)
- [ ] GND → GND
- [ ] SCL → GPIO2
- [ ] SDO → GPIO1

**Display:**
- [ ] VCC → 3.3V
- [ ] GND → GND
- [ ] LED → 3.3V (backlight)
- [ ] CS → GPIO10
- [ ] RST → GPIO8
- [ ] DC → GPIO9
- [ ] SDA → GPIO11
- [ ] SCL → GPIO12
- [ ] SDO → GPIO13

---

## 🧪 **Test It!**

### **Step 1: Upload Test Code**
```
File: src/ttp229_keypad_test.cpp
```

### **Step 2: Open Serial Monitor**
```
Baud Rate: 115200
```

### **Step 3: Check Output**
```
Should see:
✅ TTP229 module found!
✅ I2C SDA: GPIO1
✅ I2C SCL: GPIO2
```

### **Step 4: Touch Keys**
```
Touch any key (1-16) on TTP229
Should see: "👆 Key X pressed"
```

### **Step 5: Upload Full Interface**
```
File: src/ttp229_gesture_ipod.cpp
```

### **Step 6: Try Gestures!**
```
- Tap: Select
- Swipe: Navigate
- Circular: Scroll (iPod wheel!)
- Double tap: Play/pause
```

---

## 🚨 **Common Issues**

### **"TTP229 not found"**
```
Fix:
1. Check GPIO1 and GPIO2 (not 21/22!)
2. Verify 3.3V power
3. Check GND connection
4. Swap SCL and SDO if still not working
```

### **Display blank/white**
```
Fix:
1. Check LED connected to 3.3V
2. Verify all 9 wires connected
3. Check RST pin (GPIO8)
4. Try different USB cable
```

### **Touch not responding**
```
Fix:
1. Clean touch pads
2. Dry fingers
3. Press firmly
4. Check I2C address (0x57)
```

---

## 💡 **Pro Tips**

1. **Use breadboard power rails** for 3.3V and GND
2. **Keep wires short** (< 15cm)
3. **Color code your wires** for easy debugging
4. **Take a photo** of your wiring for reference
5. **Test TTP229 first** before connecting display

---

## 🎯 **Pin Summary**

```
ESP32-S3 Pins Used:
GPIO1  - TTP229 SDA (I2C Data)
GPIO2  - TTP229 SCL (I2C Clock)
GPIO8  - Display Reset
GPIO9  - Display Data/Command
GPIO10 - Display Chip Select
GPIO11 - Display MOSI (SPI Data)
GPIO12 - Display Clock (SPI Clock)
GPIO13 - Display MISO (SPI Data)

Total: 8 GPIO pins + Power/Ground
```

---

## 🚀 **You're Done!**

With just **13 wires**, you have:
- ✅ 16-key capacitive touch keypad
- ✅ 2.8" color display
- ✅ Gesture recognition
- ✅ Full iPod interface

Now enjoy your gesture-controlled iPod! 🎵

---

## 📝 **Notes**

**Why GPIO1 and GPIO2?**
- ESP32-S3 uses GPIO21/22 for USB
- GPIO1/2 are the standard I2C pins for S3
- These work perfectly for TTP229

**Can I use different pins?**
- Yes! Any GPIO can be I2C
- Just update the code:
  ```cpp
  #define I2C_SDA X  // Your pin
  #define I2C_SCL Y  // Your pin
  ```

**Need help?**
- Check Serial Monitor for errors
- Verify connections with multimeter
- Test each component separately
- Read full guide: docs/complete_wiring_ttp229.md

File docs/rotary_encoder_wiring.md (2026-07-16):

# Rotary Encoder iPod Interface - Wiring Guide

## 🎮 **Classic iPod-Style Navigation**

Instead of touch, we're using the authentic iPod approach with rotary encoder + buttons for reliable, tactile navigation.

## 🔌 **Required Components**

### **1. Rotary Encoder (KY-040 or similar)**
- **CLK** - Clock signal
- **DT** - Data signal  
- **SW** - Switch (center button)
- **VCC** - 3.3V power
- **GND** - Ground

### **2. Push Buttons (4x)**
- Menu button (back/up navigation)
- Play/Pause button
- Previous track button
- Next track button

## 📋 **Complete Wiring Diagram**

### **ESP32-S3 Connections:**

```
ESP32-S3    →    Component
--------         ---------

Display (ILI9341):
GPIO10      →    CS
GPIO9       →    DC
GPIO8       →    RST
GPIO11      →    SDA/MOSI
GPIO12      →    SCL/SCLK
GPIO13      →    SDO/MISO
3.3V        →    VCC
3.3V        →    LED
GND         →    GND

Rotary Encoder (KY-040):
GPIO0       →    CLK
GPIO1       →    DT
GPIO2       →    SW (center button)
3.3V        →    VCC
GND         →    GND

Navigation Buttons:
GPIO14      →    Menu Button (one side)
GPIO15      →    Play Button (one side)
GPIO16      →    Previous Button (one side)
GPIO17      →    Next Button (one side)
GND         →    All buttons (other side)
```

## 🔧 **Breadboard Layout**

```
ESP32-S3 DevKit Layout:

     [USB-C]
   ┌─────────────┐
   │ 3V3     GND │ ← Power rails
   │ EN      IO0 │ ← Encoder CLK
   │ IO36    IO1 │ ← Encoder DT
   │ IO37    IO2 │ ← Encoder SW
   │ IO38    IO3 │
   │ IO39    IO4 │
   │ IO40    IO5 │
   │ IO41    IO6 │
   │ IO42    IO7 │
   │ RXD0    IO8 │ ← Display RST
   │ TXD0    IO9 │ ← Display DC
   │ IO44   IO10 │ ← Display CS
   │ IO43   IO11 │ ← Display MOSI
   │ IO44   IO12 │ ← Display SCLK
   │ IO45   IO13 │ ← Display MISO
   │ IO46   IO14 │ ← Menu Button
   │ IO47   IO15 │ ← Play Button
   │ IO48   IO16 │ ← Previous Button
   │        IO17 │ ← Next Button
   │        IO18 │
   │        5V   │
   │        GND  │
   └─────────────┘
```

## 🎯 **Component Details**

### **Rotary Encoder (KY-040)**
```
Encoder Pinout:
┌─────────────┐
│  CLK  DT    │
│             │
│  SW   VCC   │
│             │
│      GND    │
└─────────────┘

Connections:
CLK → ESP32-S3 GPIO0
DT  → ESP32-S3 GPIO1  
SW  → ESP32-S3 GPIO2
VCC → ESP32-S3 3.3V
GND → ESP32-S3 GND
```

### **Push Buttons**
```
Button Wiring (x4):
┌─────────────┐
│    Button   │
│  ┌───────┐  │
│  │       │  │
│  └───────┘  │
└──┬─────┬────┘
   │     │
   │     └─── GND
   └───────── GPIO Pin

Menu Button:    GPIO14 → Button → GND
Play Button:    GPIO15 → Button → GND  
Previous:       GPIO16 → Button → GND
Next Button:    GPIO17 → Button → GND
```

## 🎮 **iPod Navigation Controls**

### **Rotary Encoder:**
- **Rotate Clockwise** → Navigate down/right
- **Rotate Counter-clockwise** → Navigate up/left
- **Press Center** → Select/OK

### **Buttons:**
- **Menu** → Go back/up one level
- **Play** → Play/Pause current track
- **Previous** → Previous track (or navigate up)
- **Next** → Next track (or navigate down)

## 🔄 **How It Works**

### **Navigation Flow:**
```
Home Screen
├── Music Library (rotary scroll through songs)
│   └── Select song → Now Playing
├── Now Playing (show current track)
├── Settings (rotary scroll through options)
└── About

Controls:
- Rotary: Scroll through menu items
- Center: Select highlighted item
- Menu: Go back to previous screen
- Play: Toggle play/pause
- Prev/Next: Change tracks or navigate
```

### **Encoder Behavior:**
- **Smooth scrolling** through menu items
- **Wrap-around** navigation (top/bottom)
- **Interrupt-driven** for responsive feel
- **Debounced** to prevent false triggers

## 🛠️ **Assembly Steps**

### **1. Connect Display (same as before)**
Wire the ILI9341 display as previously configured.

### **2. Connect Rotary Encoder**
```
1. Connect encoder VCC to ESP32-S3 3.3V
2. Connect encoder GND to ESP32-S3 GND
3. Connect encoder CLK to GPIO0
4. Connect encoder DT to GPIO1
5. Connect encoder SW to GPIO2
```

### **3. Connect Buttons**
```
1. Connect one side of each button to GND
2. Connect other sides to respective GPIO pins:
   - Menu: GPIO14
   - Play: GPIO15
   - Previous: GPIO16
   - Next: GPIO17
```

### **4. Test Setup**
Upload `src/ipod_rotary_interface.cpp` and test:
- Rotate encoder → Menu items should scroll
- Press center → Should select items
- Press buttons → Should trigger respective actions

## 📊 **Advantages of Rotary Interface**

### **vs Touch Screen:**
- ✅ **More reliable** - No calibration issues
- ✅ **Tactile feedback** - Feel the clicks
- ✅ **Authentic iPod experience** - Classic navigation
- ✅ **Works in all conditions** - No touch sensitivity issues
- ✅ **Lower power** - No touch controller needed
- ✅ **Easier to use** - Physical buttons are intuitive

### **Classic iPod Feel:**
- ✅ **Scroll wheel navigation** - Familiar interface
- ✅ **Physical buttons** - Menu, Play, Prev, Next
- ✅ **Responsive scrolling** - Smooth menu navigation
- ✅ **Visual feedback** - Highlighted selections

## 🎵 **Usage Examples**

### **Playing Music:**
1. **Rotate encoder** → Scroll to "Music Library"
2. **Press center** → Enter library
3. **Rotate encoder** → Scroll through songs
4. **Press center** → Select song (goes to Now Playing)
5. **Press Play button** → Start/pause music

### **Navigation:**
1. **Menu button** → Always goes back/up
2. **Rotary encoder** → Scroll through current menu
3. **Center button** → Select highlighted item
4. **Prev/Next buttons** → Quick track control

This gives you a **fully functional, authentic iPod experience** with reliable physical controls! 🎉

## 🔧 **Troubleshooting**

### **Encoder Not Working:**
- Check CLK/DT connections
- Verify 3.3V power to encoder
- Test with multimeter for continuity

### **Buttons Not Responding:**
- Check GND connections
- Verify GPIO pin assignments
- Test individual buttons with multimeter

### **Erratic Scrolling:**
- Add 0.1µF capacitors across encoder pins
- Check for loose breadboard connections
- Verify interrupt setup in code

The rotary encoder approach is much more reliable and gives you that authentic iPod feel! 🎮

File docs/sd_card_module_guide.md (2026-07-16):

# 💾 SD Card Module Integration Guide
## Micro SD Card Reader Module for iPod Project

---

## 📦 **Your SD Card Module Specs**

**Module Name**: Micro SD Card Reader Module (Micro SD Adaptor)

### Features:
- **Dual voltage support**: 3.3V / 5V compatible
- **Working voltage**: VCC 4.5~5.5V
- **Current draw**: 0.2~200mA (idle to active read/write)
- **Interface**: SPI standard (MISO, MOSI, SCK, CS)
- **Onboard 3.3V regulator**: LDO regulator for SD card power
- **Level converter**: Built-in for 3.3V/5V compatibility
- **Card support**: 
  - Micro SD up to 2GB
  - Micro SDHC up to 32GB
- **Mounting**: 4x M2 2.2mm screw holes

### Pinout:
```
1. GND  - Ground
2. VCC  - Power (4.5-5.5V, can use 5V or 3.3V)
3. MISO - Master In Slave Out (SPI data to ESP32)
4. MOSI - Master Out Slave In (SPI data from ESP32)
5. SCK  - Serial Clock (SPI clock)
6. CS   - Chip Select (SPI slave select)
```

---

## 🔌 **Wiring to ESP32-S3**

### Connection Diagram:
```
SD Card Module          ESP32-S3 Pin        Function
──────────────          ────────────        ────────
GND                 →   GND                 Ground
VCC                 →   3.3V                Power (module regulates to 3.3V)
MISO                →   GPIO13              SPI Data In (shared with display)
MOSI                →   GPIO11              SPI Data Out (shared with display)
SCK                 →   GPIO12              SPI Clock (shared with display)
CS                  →   GPIO5               Chip Select (dedicated)
```
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

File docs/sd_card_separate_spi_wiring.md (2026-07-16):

# 💾 SD Card - Separate SPI Bus Solution
## No More Conflicts with Display!

---

## 🔧 **The Solution: Use HSPI for SD Card**

ESP32-S3 has **two SPI buses**:
- **SPI (VSPI)** - Used by display (GPIO 10, 11, 12, 13)
- **HSPI** - Use for SD card (different pins!)

This way they don't interfere with each other!

---

## 🔌 **NEW SD Card Wiring**

### Move SD Card to HSPI Pins:

```
SD Card Module → ESP32-S3 (HSPI)
────────────────────────────────
VCC  → 3.3V
GND  → GND
CS   → GPIO15  (was GPIO5)
MOSI → GPIO35  (was GPIO11)
SCK  → GPIO36  (was GPIO12)
MISO → GPIO37  (was GPIO13)
```

### Display Stays the Same (VSPI):

```
Display → ESP32-S3 (VSPI)
─────────────────────────
VCC  → 3.3V
GND  → GND
CS   → GPIO10
RST  → GPIO8
DC   → GPIO9
MOSI → GPIO11
SCK  → GPIO12
MISO → GPIO13
LED  → 3.3V
```

### TTP229 Touch Stays the Same:

```
TTP229 → ESP32-S3
─────────────────
VCC  → 3.3V
GND  → GND
SCL  → GPIO2
SDO  → GPIO1
```

---
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

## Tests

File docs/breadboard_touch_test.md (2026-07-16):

# Breadboard Touch Test Setup

## Components Needed

### **Hardware**
- ESP32-S3 Development Board
- 2.8" ILI9341 TFT Display (your MSP2806 module)
- Large breadboard (830 points)
- Jumper wires (Male-Male, Male-Female)
- USB-C cable for ESP32 power

### **Software**
- PlatformIO or Arduino IDE
- Touch test code (provided)

## Pin Connections

### **Display Connections (SPI)**
```
ESP32-S3 Pin    Display Pin     Wire Color (Suggested)
GPIO10      →   CS              Orange
GPIO9       →   DC              Yellow  
GPIO8       →   RST             White
GPIO11      →   MOSI (SDI)      Blue
GPIO12      →   SCLK (SCK)      Green
GPIO13      →   MISO (SDO)      Purple
3.3V        →   VCC             Red
GND         →   GND             Black
GPIO2       →   LED (optional)  Gray
```

### **Touch Connections (SPI)**
```
ESP32-S3 Pin    Touch Pin       Wire Color (Suggested)
GPIO6       →   T_CS            Brown
GPIO7       →   T_CLK           Pink
GPIO5       →   T_DIN           Cyan
GPIO4       →   T_DO            Magenta
GPIO3       →   T_IRQ           Light Blue
3.3V        →   VCC (shared)    Red
GND         →   GND (shared)    Black
```

## Breadboard Layout Diagram

```
ESP32-S3 Development Board
┌─────────────────────────────────────┐
│ 3V3  EN  36  39  34  35  32  33  25 │
│ GND  23  22  21  19  18  5   17  16 │
│ 15   2   0   4   16  17  5   18  19 │
│ 21   RX  TX  22  23  EN  3V3 GND    │
└─────────────────────────────────────┘
     │   │   │   │   │   │   │   │
     │   │   │   │   │   │   │   └─── GPIO19
     │   │   │   │   │   │   └─────── GPIO18  
     │   │   │   │   │   └─────────── GPIO5
     │   │   │   │   └─────────────── GPIO17
     │   │   │   └─────────────────── GPIO4
     │   │   └─────────────────────── GPIO0
     │   └─────────────────────────── GPIO2
     └─────────────────────────────── GPIO15

Display Module (Back View)
┌─────────────────────────────────────┐
│ VCC GND CS  RST DC  MOSI SCLK MISO │ ← Display pins
│ VCC GND T_CS T_IRQ T_DIN T_DO T_CLK │ ← Touch pins  
└─────────────────────────────────────┘
```

## Step-by-Step Wiring

### **Step 1: Power Connections**
```
1. Connect ESP32 3.3V → Breadboard positive rail (red)
2. Connect ESP32 GND → Breadboard negative rail (black)
3. Connect Display VCC → Breadboard positive rail
4. Connect Display GND → Breadboard negative rail
```

### **Step 2: Display SPI Connections**
```
ESP32-S3        Breadboard      Display
GPIO10     →    Row 10     →    CS
GPIO9      →    Row 9      →    DC
GPIO8      →    Row 8      →    RST
GPIO11     →    Row 11     →    MOSI
GPIO12     →    Row 12     →    SCLK
GPIO13     →    Row 13     →    MISO
```

### **Step 3: Touch SPI Connections**
```
ESP32-S3        Breadboard      Touch
GPIO6      →    Row 6      →    T_CS
GPIO7      →    Row 7      →    T_CLK
GPIO5      →    Row 5      →    T_DIN
GPIO4      →    Row 4      →    T_DO
GPIO3      →    Row 3      →    T_IRQ
```

## Physical Breadboard Layout

### **Breadboard Sections**
```
Power Rails (Top):
[+] ←── 3.3V from ESP32
[-] ←── GND from ESP32

Main Area:
Rows 1-30: ESP32-S3 connections
Rows 31-60: Display module connections  
Rows 61-65: Touch connections

Power Rails (Bottom):
[+] ←── Connected to top positive
[-] ←── Connected to top negative
```

### **Wire Management Tips**
1. **Use different colors** for different signal types:
   - Red: Power (3.3V)
   - Black: Ground
   - Blue/Green: SPI signals
   - Yellow/Orange: Control signals

2. **Keep wires short** to reduce noise
3. **Route power first**, then signals
4. **Double-check connections** before powering on

## Testing Procedure

### **Step 1: Visual Inspection**
```
☐ All power connections secure
☐ No short circuits (red to black)
☐ All signal wires connected
☐ Display module properly seated
☐ ESP32 properly connected
```

### **Step 2: Power Test**
```
1. Connect USB-C to ESP32
2. Check for power LED on ESP32
3. Check for power LED on display (if present)
4. Measure 3.3V on breadboard rails with multimeter
```

### **Step 3: Display Test**
```
1. Upload basic display test code first
2. Should see display initialize
3. Look for colored screen or test pattern
4. If display works, proceed to touch test
```

### **Step 4: Touch Test**
```
1. Upload touch test code (touch_test.cpp)
2. Open Serial Monitor (115200 baud)
3. Touch different areas of screen
4. Watch for coordinate changes in serial output
```

## Expected Serial Output

### **Touch Working (Success)**
```
Touch Test Starting...
Touch pins initialized
Touch the screen to test...
IRQ: RELEASED, X:  200, Y:  300
IRQ: PRESSED, X: 2150, Y: 1800 -> TOUCH DETECTED! Screen coords: X=120, Y=160
IRQ: PRESSED, X: 3200, Y: 2900 -> TOUCH DETECTED! Screen coords: X=200, Y=280
IRQ: RELEASED, X:  180, Y:  250
```

### **Touch Not Working (Failure)**
```
Touch Test Starting...
Touch pins initialized
Touch the screen to test...
IRQ: RELEASED, X:    0, Y:    0
IRQ: RELEASED, X:    0, Y:    0
IRQ: RELEASED, X: 4095, Y: 4095
IRQ: RELEASED, X: 4095, Y: 4095
```

## Troubleshooting

### **Display Not Working**
```
Problem: Black screen
Solutions:
☐ Check power connections (3.3V, GND)
☐ Verify SPI pin connections
☐ Check RST pin connection
☐ Try different jumper wires
☐ Measure voltage at display VCC pin
```

### **Touch Not Responding**
```
Problem: No coordinate changes
Solutions:
☐ Verify touch pin connections (T_CS, T_CLK, T_DIN, T_DO)
☐ Check if T_IRQ pin changes when touching
☐ Try different pressure when touching
☐ Verify 3.3V power to touch controller
☐ Check for loose connections
```

### **Erratic Touch Readings**
```
Problem: Random coordinates
Solutions:
☐ Add 100nF capacitor between 3.3V and GND near display
☐ Keep wires short and away from power cables
☐ Check for loose breadboard connections
☐ Try different touch pins if available
```

## Connection Verification Checklist

### **Before Powering On**
```
☐ ESP32-S3 3.3V → Breadboard positive rail
☐ ESP32-S3 GND → Breadboard negative rail
☐ Display VCC → Breadboard positive rail
☐ Display GND → Breadboard negative rail
☐ All 6 display SPI pins connected correctly
☐ All 5 touch SPI pins connected correctly
☐ No short circuits between power rails
☐ All connections tight and secure
```

### **After Powering On**
```
☐ ESP32 power LED on
☐ Display shows some activity (backlight, pixels)
☐ Serial monitor shows "Touch Test Starting..."
☐ No smoke or burning smell
☐ 3.3V measured on breadboard rails
```

## Quick Test Code

### **Minimal Touch Test (Copy to Arduino IDE)**
```cpp
// Quick touch test - paste into Arduino IDE
#define TOUCH_CS 6
#define TOUCH_CLK 7
#define TOUCH_DIN 5
#define TOUCH_DO 4

void setup() {
  Serial.begin(115200);
  pinMode(TOUCH_CS, OUTPUT);
  pinMode(TOUCH_CLK, OUTPUT);
  pinMode(TOUCH_DIN, OUTPUT);
  pinMode(TOUCH_DO, INPUT);
  digitalWrite(TOUCH_CS, HIGH);
  Serial.println("Touch test ready - touch screen now");
}

void loop() {
  uint16_t x = readTouch(0x90);
  uint16_t y = readTouch(0xD0);
  Serial.printf("X: %4d, Y: %4d\n", x, y);
  delay(100);
}

uint16_t readTouch(uint8_t cmd) {
  digitalWrite(TOUCH_CS, LOW);
  // Send command
  for(int i=7; i>=0; i--) {
    digitalWrite(TOUCH_DIN, (cmd>>i)&1);
    digitalWrite(TOUCH_CLK, HIGH);
    digitalWrite(TOUCH_CLK, LOW);
  }
  // Read result
  uint16_t result = 0;
  for(int i=11; i>=0; i--) {
    digitalWrite(TOUCH_CLK, HIGH);
    if(digitalRead(TOUCH_DO)) result |= (1<<i);
    digitalWrite(TOUCH_CLK, LOW);
  }
  digitalWrite(TOUCH_CS, HIGH);
  return result;
}
```

## Success Criteria

### **Touch is Working If:**
✅ X values change from ~200 to ~3800 when touching left to right
✅ Y values change from ~200 to ~3800 when touching top to bottom  
✅ Values are stable when not touching
✅ IRQ pin goes LOW when screen is pressed (if connected)

### **Touch is NOT Working If:**
❌ X and Y always read 0 or 4095
❌ Values don't change when touching different areas
❌ Random noise values that change constantly
❌ No response to any touch input

Once you confirm touch is working, you can enable it in the main iPod code by setting `TOUCH_ENABLED true` in config.h!

This breadboard setup will definitively tell you if your display's touch functionality is working or not.

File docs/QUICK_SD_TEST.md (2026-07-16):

# 🎴 Quick SD Card Test - ILI9341 Built-in Slot

## 🎯 Goal
Test if your MSP2806 (ILI9341) display has a built-in SD card slot.

---

## ⚡ Quick Steps

### 1️⃣ Check Your Display
Look at the **BACK** of your display for:
- 📍 MicroSD card slot
- 📍 Pin labeled `SD_CS` or `SDCS`

### 2️⃣ Insert SD Card
- Put your 16GB microSD card into the **display module** (not a separate SD module)
- Make sure it's FAT32 formatted

### 3️⃣ Connect SD_CS Wire
```
Display SD_CS pin → ESP32 GPIO4
```

### 4️⃣ Upload Test
- Open: `src/ili9341_builtin_sd_test.cpp`
- Upload to ESP32-S3
- Open Serial Monitor (115200 baud)

---

## ✅ Success Looks Like:
```
✅ SUCCESS! SD card works on GPIO4
📇 Type: SDHC
💾 Size: 15200 MB
```

## ❌ Failure Looks Like:
```
❌ SD card not detected on GPIO4, GPIO5, or GPIO14
```

---

## 🔀 What's Next?

### If SD Works:
1. Note which GPIO worked (4, 5, or 14)
2. Update `complete_ipod_system.cpp`:
   ```cpp
   #define SD_CS 4  // Use the GPIO that worked
   ```
3. Test complete system with music files!

### If SD Doesn't Work:
1. Your display probably doesn't have a built-in SD slot
2. Use `src/ipod_no_sd.cpp` instead (demo mode)
3. Has 9 demo songs, full UI, works perfectly!
4. Plan for PCB design with proper SD support later

---

## 📸 Need Help?
Take a photo of the **back of your display** showing:
- The SD card slot (if present)
- All pin labels
- Any text/model numbers

---

## 🚀 Demo Mode (No SD Needed)
If you want to continue without SD card:
```
Upload: src/ipod_no_sd.cpp
- 9 demo songs built-in
- Full iPod UI
- Touch controls working
- No SD card needed!
```

---

**Ready? Upload `ili9341_builtin_sd_test.cpp` now!** 🎴

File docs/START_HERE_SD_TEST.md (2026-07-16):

# 🎯 START HERE - SD Card Test

## What We're Testing

Your **MSP2806 (ILI9341) display** might have a **built-in SD card slot**. Let's find out!

---

## ⚡ 3-Minute Test

### Step 1: Look at Your Display (30 seconds)

Turn your display over and look at the **BACK**:

```
Do you see:
□ A small slot for microSD card?
□ A pin labeled "SD_CS" or "SDCS"?
```

**If YES:** Continue to Step 2  
**If NO:** Skip to "No SD Slot" section below

---

### Step 2: Connect SD_CS Wire (1 minute)

```
Display SD_CS pin → ESP32 GPIO4
```

Just **ONE wire** from the SD_CS pin on your display to GPIO4 on ESP32.

---

### Step 3: Upload Test (1 minute)

1. Open: `src/ili9341_builtin_sd_test.cpp`
2. Click Upload
3. Open Serial Monitor (115200 baud)

---

### Step 4: Read Results (30 seconds)

**SUCCESS looks like:**
```
✅ SUCCESS! SD card works on GPIO4
💾 Size: 15200 MB
```

**FAILURE looks like:**
```
❌ SD card not detected
```

---

## ✅ If Test SUCCEEDS

**Congratulations!** Your display has a built-in SD slot!

### Next Steps:
1. Note which GPIO worked (4, 5, or 14)
2. Open `src/complete_ipod_system.cpp`
3. Change this line:
   ```cpp
   #define SD_CS 4  // Use the GPIO that worked
   ```
4. Upload and test with music files!

---

## ❌ If Test FAILS

**No problem!** Your display doesn't have a built-in SD slot.

### Use Demo Mode Instead:

1. Open: `src/ipod_no_sd.cpp`
2. Upload
3. Done! ✅

**Demo mode has:**
- ✅ 9 demo songs
- ✅ Full iPod UI
- ✅ All touch controls
- ✅ No SD card needed

---

## 📚 More Information

**Detailed guides:**
- `docs/ili9341_builtin_sd_guide.md` - Complete guide
- `docs/ili9341_sd_slot_identification.md` - How to identify SD slot
- `docs/SD_CARD_SOLUTION_SUMMARY.md` - All options explained

**Quick reference:**
- `docs/QUICK_SD_TEST.md` - Quick test guide

---

## 🎯 Bottom Line

1. **Test takes 3 minutes**
2. **If works:** Use built-in SD (best solution)
3. **If fails:** Use demo mode (works great)
4. **Either way:** You have a working iPod!

---

**Ready? Upload `src/ili9341_builtin_sd_test.cpp` now!** 🚀

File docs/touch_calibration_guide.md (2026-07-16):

# Touch Calibration Improvement Guide

## Methods to Increase Touch Calibration Accuracy

### 🎯 Method 1: Force Recalibration

**In User_Setup.h, change:**
```cpp
#define REPEAT_CAL true   // Forces recalibration every boot
```

**Or in your code:**
```cpp
// Delete calibration file to force recalibration
SPIFFS.remove("/TouchCalData");
```

### 🎯 Method 2: Use Advanced Calibration Script

Upload `src/advanced_touch_calibration.cpp` which provides:

1. **Standard 5-Point Calibration** - Basic TFT_eSPI calibration
2. **Enhanced 9-Point Calibration** - More calibration points for accuracy
3. **Manual Fine-Tuning** - Adjust calibration parameters manually
4. **Calibration Testing** - Test accuracy with visual feedback

### 🎯 Method 3: Improve Hardware Setup

#### **Better Touch Accuracy:**
- ✅ **Use a stylus** instead of finger for calibration
- ✅ **Stable surface** - don't hold device while calibrating
- ✅ **Good lighting** - see calibration targets clearly
- ✅ **Clean screen** - remove fingerprints and dust
- ✅ **Steady hands** - take time with each calibration point

#### **Wiring Improvements:**
- ✅ **Shorter wires** - reduce electrical noise
- ✅ **Twisted pair wires** - for SPI signals
- ✅ **Good connections** - no loose breadboard connections
- ✅ **Separate power** - dedicated 3.3V for touch controller

### 🎯 Method 4: Software Calibration Tweaks

#### **In User_Setup.h:**
```cpp
// Increase touch precision
#define TOUCH_PRECISION 15    // Higher = more precise (1-20)
#define TOUCH_THRESHOLD 500   // Lower = more sensitive
#define TOUCH_Z_THRESHOLD 300 // Pressure sensitivity
```

#### **In your code:**
```cpp
// Custom calibration values (adjust for your display)
uint16_t calData[5] = {
  300,   // Touch X minimum (adjust if touch offset)
  3700,  // Touch X maximum (adjust if touch offset)  
  300,   // Touch Y minimum (adjust if touch offset)
  3700,  // Touch Y maximum (adjust if touch offset)
  1      // Touch orientation (0-7, try different values)
};

// Apply custom calibration
tft.setTouch(calData);
```

### 🎯 Method 5: Multi-Point Calibration

```cpp
void improvedCalibration() {
  // Do standard calibration first
  tft.calibrateTouch(calData, TFT_MAGENTA, TFT_BLACK, 15);
  
  // Then fine-tune with additional points
  calibrateCorners();
  calibrateEdges();
  calibrateCenter();
}

void calibrateCorners() {
  // Test and adjust corner accuracy
  struct Point { int x, y; };
  Point corners[] = {{20,20}, {220,20}, {220,300}, {20,300}};
  
  for (int i = 0; i < 4; i++) {
    // Show target at corner
    drawTarget(corners[i].x, corners[i].y);
    
    // Get touch input
    uint16_t tx, ty;
    while (!tft.getTouch(&tx, &ty)) delay(50);
    
    // Calculate offset and adjust calibration
    adjustCalibration(corners[i].x, corners[i].y, tx, ty);
  }
}
```

### 🎯 Method 6: Calibration Validation

```cpp
void validateCalibration() {
  // Test known points
  struct TestPoint { int x, y; const char* name; };
  TestPoint testPoints[] = {
    {20, 20, "Top-Left"},
    {120, 20, "Top-Center"}, 
    {220, 20, "Top-Right"},
    {120, 160, "Center"},
    {20, 300, "Bottom-Left"},
    {220, 300, "Bottom-Right"}
  };
  
  float totalError = 0;
  int pointCount = sizeof(testPoints) / sizeof(testPoints[0]);
  
  for (int i = 0; i < pointCount; i++) {
    // Show target
    drawTarget(testPoints[i].x, testPoints[i].y);
    
    // Get touch
    uint16_t tx, ty;
    while (!tft.getTouch(&tx, &ty)) delay(50);
    
    // Calculate error
    float error = sqrt(pow(testPoints[i].x - tx, 2) + pow(testPoints[i].y - ty, 2));
    totalError += error;
    
    Serial.print(testPoints[i].name);
    Serial.print(" error: ");
    Serial.print(error);
    Serial.println(" pixels");
  }
  
  float avgError = totalError / pointCount;
  Serial.print("Average error: ");
  Serial.print(avgError);
  Serial.println(" pixels");
  
  if (avgError < 10) {
    Serial.println("Calibration: EXCELLENT");
  } else if (avgError < 20) {
    Serial.println("Calibration: GOOD");
  } else {
    Serial.println("Calibration: NEEDS IMPROVEMENT");
  }
}
```

## 🔧 Quick Calibration Fixes

### **Issue 1: Touch Offset (touches register in wrong location)**
```cpp
// Adjust these values in calData[]
calData[0] += 50;  // Shift touch right
calData[0] -= 50;  // Shift touch left
calData[2] += 50;  // Shift touch down  
calData[2] -= 50;  // Shift touch up
```

### **Issue 2: Touch Scale (touches too sensitive/insensitive)**
```cpp
// Adjust range values
calData[1] = calData[0] + 3400;  // X range (increase for less sensitive)
calData[3] = calData[2] + 3400;  // Y range (increase for less sensitive)
```

### **Issue 3: Inverted Touch (X or Y axis flipped)**
```cpp
// Try different orientation values
calData[4] = 0;  // Normal
calData[4] = 1;  // Rotate 90°
calData[4] = 2;  // Rotate 180°
calData[4] = 3;  // Rotate 270°
calData[4] = 4;  // Mirror X
calData[4] = 5;  // Mirror Y
calData[4] = 6;  // Mirror X + Rotate 90°
calData[4] = 7;  // Mirror Y + Rotate 90°
```

## 📊 Calibration Quality Targets

### **Excellent Calibration:**
- ✅ Average error < 10 pixels
- ✅ Corner accuracy < 5 pixels
- ✅ Center accuracy < 3 pixels
- ✅ Consistent across all areas

### **Good Calibration:**
- ✅ Average error < 20 pixels
- ✅ Corner accuracy < 15 pixels
- ✅ Usable for UI interaction

### **Poor Calibration (needs improvement):**
- ❌ Average error > 20 pixels
- ❌ Inconsistent response
- ❌ Dead zones or overly sensitive areas

## 🎯 Best Practices

1. **Calibrate in final orientation** - same rotation as your app
2. **Use consistent pressure** - same force for all calibration points
3. **Calibrate at operating temperature** - after device has warmed up
4. **Store multiple calibrations** - for different orientations
5. **Validate regularly** - check calibration accuracy periodically
6. **Use stylus for precision** - especially for small targets

The advanced calibration script provides all these methods in an easy-to-use interface!

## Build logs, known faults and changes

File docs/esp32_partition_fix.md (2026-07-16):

# ESP32-S3 Partition Error Fix

## Error Explanation
```
cp: /Users/stavinfernandes/Library/Arduino15/packages/esp32/hardware/esp32/3.3.5/tools/partitions/{build.partitions}.csv: No such file or directory
```

This error occurs when the ESP32-S3 board configuration references a partition scheme that doesn't exist in your ESP32 board package.

## Quick Fix - Change Board Settings

### Step 1: Correct Board Configuration
In Arduino IDE, go to **Tools** menu and set:

1. **Board**: "ESP32S3 Dev Module" (not other variants)
2. **Partition Scheme**: "Default 4MB with spiffs (1.2MB APP/1.5MB SPIFFS)"
3. **Flash Size**: "4MB" (not 16MB for now)
4. **PSRAM**: "Disabled" (for initial testing)

### Step 2: Alternative Board Settings (if above doesn't work)
Try these settings:
1. **Board**: "ESP32S3 Dev Module"
2. **Partition Scheme**: "No OTA (2MB APP/2MB SPIFFS)"
3. **Flash Size**: "4MB"
4. **PSRAM**: "Disabled"

### Step 3: If Still Failing, Use Minimal Settings
1. **Board**: "ESP32S3 Dev Module"
2. **Partition Scheme**: "Minimal SPIFFS (1.9MB APP with OTA/190KB SPIFFS)"
3. **Flash Size**: "4MB"
4. **PSRAM**: "Disabled"

## Complete Arduino IDE Settings for ESP32-S3

```
Tools Menu Settings:
├── Board: "ESP32S3 Dev Module"
├── Upload Speed: "921600"
├── CPU Frequency: "240MHz (WiFi/BT)"
├── Flash Mode: "QIO"
├── Flash Frequency: "80MHz"
├── Flash Size: "4MB"
├── Partition Scheme: "Default 4MB with spiffs"
├── Core Debug Level: "None"
├── PSRAM: "Disabled" (enable later after basic test works)
├── Arduino Runs On: "Core 1"
├── Events Run On: "Core 1"
└── Port: [Your ESP32-S3 port]
```

## Alternative: Update ESP32 Board Package

### Method 1: Update to Latest Version
1. **Tools → Board → Boards Manager**
2. Search "ESP32"
3. Update "esp32" by Espressif Systems to latest version
4. Restart Arduino IDE

### Method 2: Use Specific Version
If latest doesn't work, try version 2.0.11:
1. In Boards Manager, click dropdown next to ESP32
2. Select version "2.0.11"
3. Install that specific version

## Test with Simple Code First

Before using the display code, test with this minimal sketch:

```cpp
void setup() {
  Serial.begin(115200);
  delay(2000);
  Serial.println("ESP32-S3 Basic Test");
  Serial.println("If you see this, board settings are correct!");
  
  // Test built-in LED (if available)
  pinMode(2, OUTPUT);
}

void loop() {
  digitalWrite(2, HIGH);
  Serial.println("LED ON");
  delay(1000);
  
  digitalWrite(2, LOW);
  Serial.println("LED OFF");
  delay(1000);
}
```

## If Problem Persists

### Check ESP32 Board Package Installation
1. Go to: `/Users/stavinfernandes/Library/Arduino15/packages/esp32/hardware/esp32/3.3.5/tools/partitions/`
2. List files: should see `.csv` files like:
   - `default.csv`
   - `minimal.csv`
   - `no_ota.csv`
   - `huge_app.csv`

### Reinstall ESP32 Board Package
1. **Tools → Board → Boards Manager**
2. Find "esp32" by Espressif Systems
3. Click "Remove"
4. Restart Arduino IDE
5. Reinstall "esp32" package
6. Restart Arduino IDE again

### Manual Fix (Advanced)
If partition files are missing:
1. Download ESP32 Arduino Core from GitHub
2. Copy partition files to: `/Users/stavinfernandes/Library/Arduino15/packages/esp32/hardware/esp32/[version]/tools/partitions/`

## Recommended Workflow

### Step 1: Fix Board Settings
Use the minimal settings above

### Step 2: Test Basic Sketch
Upload the simple LED blink code

### Step 3: Test GPIO
Upload `src/simple_gpio_test.cpp`

### Step 4: Test Display
Once basic functionality works, try display code

## Common Board Setting Issues

### Issue 1: Wrong Board Selected
- ❌ "ESP32 Dev Module" (wrong for S3)
- ❌ "ESP32-S3-DevKitC-1" (might not exist)
- ✅ "ESP32S3 Dev Module" (correct)

### Issue 2: Incompatible Partition Scheme
- ❌ Custom partition schemes
- ❌ 16MB partitions on 4MB flash
- ✅ Default 4MB schemes

### Issue 3: PSRAM Issues
- Start with PSRAM disabled
- Enable only after basic functionality works

## Success Indicators

You'll know it's working when:
- ✅ Code compiles without partition errors
- ✅ Upload completes successfully
- ✅ Serial Monitor shows output at 115200 baud
- ✅ No "partition not found" errors

Once basic upload works, you can gradually enable more features like PSRAM and try the display code.

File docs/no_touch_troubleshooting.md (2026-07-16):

# No Touch Response - Complete Troubleshooting Guide

## 🚨 **IMMEDIATE ACTION PLAN**

Since you've checked connections but still have no touch, follow these steps **in order**:

### **Step 1: Check User_Setup.h Configuration (Most Common Issue)**

Upload **`src/user_setup_checker.cpp`** first:

```cpp
// This will tell you exactly what's missing in User_Setup.h
// 90% of "no touch" issues are due to missing SUPPORT_TOUCH
```

**Expected Output:**
```
✅ SUPPORT_TOUCH is defined
✅ TOUCH_CS is defined as GPIO6
✅ ILI9341_DRIVER is defined
```

**If you see:**
```
❌ SUPPORT_TOUCH is NOT defined
```

**SOLUTION:** Copy `src/User_Setup_Complete.h` to your TFT_eSPI library folder as `User_Setup.h`

### **Step 2: Verify Hardware Connections**

Upload **`src/wiring_verification_test.cpp`**:

```cpp
// This tests each pin individually
// Shows exactly which connections are working/failing
```

**Check this wiring carefully:**
```
ESP32-S3    MSP2806 Touch
--------    -------------
GPIO6   →   T_CS    (Touch Chip Select)
GPIO7   →   T_CLK   (Touch Clock)
GPIO5   →   T_DIN   (Touch Data In)
GPIO4   →   T_DO    (Touch Data Out)
GPIO3   →   T_IRQ   (Touch Interrupt)
3.3V    →   VCC     (Power - shared with display)
GND     →   GND     (Ground - shared with display)
```

### **Step 3: Deep Hardware Analysis**

Upload **`src/touch_hardware_diagnostic.cpp`**:

```cpp
// Comprehensive hardware test
// Tests SPI communication, touch controller response, etc.
```

## 🔍 **COMMON CAUSES & SOLUTIONS**

### **1. Software Configuration Issues (80% of cases)**

#### **Missing SUPPORT_TOUCH:**
```cpp
// Add this to User_Setup.h:
#define SUPPORT_TOUCH
```

#### **Wrong TOUCH_CS pin:**
```cpp
// Make sure User_Setup.h has:
#define TOUCH_CS 6
```

#### **Missing touch controller type:**
```cpp
// Add to User_Setup.h:
#define TFT_TOUCH_DEVICE_XPT2046
```

### **2. Hardware Connection Issues (15% of cases)**

#### **Loose Breadboard Connections:**
- Push all jumper wires firmly into breadboard
- Try different breadboard holes
- Use shorter jumper wires (< 10cm)

#### **Wrong Pin Connections:**
```
DOUBLE-CHECK THESE CONNECTIONS:
ESP32-S3 GPIO6 → MSP2806 T_CS   (NOT CS!)
ESP32-S3 GPIO7 → MSP2806 T_CLK  (NOT SCL!)
ESP32-S3 GPIO5 → MSP2806 T_DIN  (NOT SDA!)
ESP32-S3 GPIO4 → MSP2806 T_DO   (NOT SDO!)
```

#### **Power Issues:**
- Verify 3.3V reaches touch controller
- Check GND connections
- Measure voltage with multimeter if possible

### **3. Display Module Issues (5% of cases)**

#### **Touch Controller Not Working:**
Some MSP2806 modules have faulty touch controllers even though they show "Touch: N"

**Test:** Upload `wiring_verification_test.cpp` and check if you get:
```
❌ All readings are 0 - touch controller not responding
```

**Solution:** Try a different display module or use external touch controller

## 🛠️ **SYSTEMATIC TROUBLESHOOTING**

### **Phase 1: Software Check**
```bash
1. Upload user_setup_checker.cpp
2. Fix any missing #define statements
3. Restart Arduino IDE
4. Re-upload test
```

### **Phase 2: Hardware Check**
```bash
1. Upload wiring_verification_test.cpp
2. Check each pin connection reported
3. Fix any loose/wrong connections
4. Re-test
```

### **Phase 3: Deep Diagnosis**
```bash
1. Upload touch_hardware_diagnostic.cpp
2. Follow the detailed analysis
3. Apply recommended fixes
4. Re-test
```

## 📊 **DIAGNOSTIC RESULTS INTERPRETATION**

### **User Setup Checker Results:**

#### **✅ All Good:**
```
✅ SUPPORT_TOUCH is defined
✅ TOUCH_CS is defined as GPIO6
✅ ILI9341_DRIVER is defined
```
→ **Software config is correct, check hardware**

#### **❌ Missing SUPPORT_TOUCH:**
```
❌ CRITICAL: SUPPORT_TOUCH not defined
```
→ **This is the problem! Fix User_Setup.h**

### **Wiring Verification Results:**

#### **✅ Hardware Working:**
```
Touch controller power test: ✅ Touch controller has power and responds
Raw values: X=1234 Y=2345 Z1=567 Z2=890
✅ Touch controller responding with valid data!
```
→ **Hardware is fine, check software config**

#### **❌ Hardware Problem:**
```
❌ All readings are 0 - touch controller not responding
```
→ **Check power and pin connections**

#### **❌ Wiring Problem:**
```
❌ All readings are maximum - pins stuck HIGH
```
→ **Check T_DO pin connection**

### **Hardware Diagnostic Results:**

#### **✅ Everything Working:**
```
✅ Display initialized successfully
✅ Touch pins configured manually
✅ Touch controller responding with valid data
✅ TFT_eSPI touch integration working
```
→ **System should work! Try calibration**

#### **❌ Critical Issues:**
```
❌ PRIMARY ISSUE: SUPPORT_TOUCH not enabled
❌ HARDWARE ISSUE: No SPI communication with touch controller
```
→ **Follow specific recommendations provided**

## 🔧 **QUICK FIXES TO TRY**

### **1. User_Setup.h Quick Fix:**
```bash
# Navigate to your Arduino libraries folder
cd ~/Documents/Arduino/libraries/TFT_eSPI/

# Backup current setup
cp User_Setup.h User_Setup_backup.h

# Copy our complete setup
cp /path/to/your/project/src/User_Setup_Complete.h User_Setup.h

# Restart Arduino IDE
```

### **2. Hardware Quick Fixes:**
```bash
1. Push all breadboard wires firmly
2. Try different jumper wires
3. Check 3.3V with multimeter (should be 3.2-3.4V)
4. Swap breadboard if available
5. Try touching screen firmly during tests
```

### **3. Alternative Pin Test:**
If GPIO6 doesn't work, try GPIO15:
```cpp
// In User_Setup.h, change:
#define TOUCH_CS 15  // Instead of 6
```

## 📱 **MSP2806 Display Variants**

Your MSP2806 might be one of these variants:

### **Type 1: Touch Working (Most Common)**
- Has functional XPT2046 touch controller
- Touch pins are connected internally
- Should work with proper software config

### **Type 2: Touch Disabled**
- Touch controller present but not connected
- "Touch: N" label is accurate
- Need external touch overlay

### **Type 3: Faulty Touch**
- Touch controller present but defective
- Hardware responds but gives invalid data
- Need replacement module

**To Identify:** Upload `wiring_verification_test.cpp` and check the raw values.

## 🆘 **LAST RESORT SOLUTIONS**

### **If Software Config is Correct but Still No Touch:**

1. **Try Different Touch Library:**
```cpp
// Instead of TFT_eSPI touch, use XPT2046_Touchscreen library
#include <XPT2046_Touchscreen.h>
XPT2046_Touchscreen touch(TOUCH_CS, TOUCH_IRQ);
```

2. **Try Different GPIO Pins:**
```cpp
// Some GPIO pins may have issues, try:
#define TOUCH_CS 15  // Instead of 6
#define TOUCH_CLK 16 // Instead of 7
#define TOUCH_DIN 17 // Instead of 5
#define TOUCH_DO 18  // Instead of 4
```

3. **Use External Touch Module:**
- Get a separate XPT2046 touch controller
- Wire it independently from display
- More reliable than integrated touch

4. **Check Display Module:**
- Try a different MSP2806 module
- Some modules have defective touch controllers
- Look for modules explicitly labeled with working touch

## 📞 **Getting Help**

If none of these solutions work:

1. **Upload all three diagnostic scripts**
2. **Copy the complete Serial Monitor output**
3. **Take photos of your wiring**
4. **Note your exact ESP32-S3 and MSP2806 model numbers**

The diagnostic tools will provide specific error messages that pinpoint the exact issue!

## 🎯 **Success Criteria**

You'll know touch is working when:
```
✅ user_setup_checker.cpp shows all green checkmarks
✅ wiring_verification_test.cpp shows "Hardware OK!"
✅ touch_hardware_diagnostic.cpp shows "Touch controller responding"
✅ You can see touch coordinates in Serial Monitor
✅ Touch points appear on screen when you touch
```

**Most likely issue:** Missing `#define SUPPORT_TOUCH` in User_Setup.h - fix this first!

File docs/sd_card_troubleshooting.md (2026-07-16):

# 🔧 SD Card Module Troubleshooting Guide

## Card Works in Phone But Not in Module

This is a common issue! Here are the most likely causes and solutions:

---

## 🔍 **Quick Checks (Do These First)**

### 1. Card Insertion
```
❌ Common mistake: Card not fully inserted
✅ Solution: Push card in until you hear/feel a click
✅ Card should be flush with module
```

### 2. Wiring Check
```
Double-check every connection:

SD Module Pin → ESP32-S3 Pin
─────────────────────────────
VCC  → 3.3V  (NOT 5V!)
GND  → GND
CS   → GPIO5
MOSI → GPIO11
SCK  → GPIO12
MISO → GPIO13

Common mistakes:
❌ VCC connected to 5V (use 3.3V)
❌ MOSI/MISO swapped
❌ Loose jumper wires
❌ Wrong GPIO numbers
```

### 3. Power Supply
```
SD cards need stable power:
- Minimum: 3.3V @ 200mA
- Check: USB cable quality
- Try: Different USB port/power supply
- Avoid: Long/thin USB cables
```

---

## 🧪 **Diagnostic Steps**

### Step 1: Run Diagnostic Tool
Upload `sd_card_diagnostic.cpp` and check serial output:

```bash
pio run -t upload -t monitor
```

Look for these results:

**✅ Good:**
```
TEST 1: Pin Connections
✅ Pins configured
✅ MISO is HIGH (card present)

TEST 3: SD Card Init
✅ SUCCESS at 400kHz!
Card Type: SDHC
Total Size: 15360 MB
```

**❌ Problem:**
```
TEST 3: SD Card Init
❌ FAILED at 400kHz
```

### Step 2: Check MISO Pin
The MISO pin tells us if the card is responding:

```
MISO HIGH = Card is present and powered
MISO LOW  = Card not detected or wiring issue
```

If MISO is always LOW:
1. Card not inserted properly
2. VCC not connected
3. Card slot damaged
4. Wrong MISO pin

---

## 🔧 **Common Issues & Solutions**

### Issue 1: "SD Card initialization failed"

**Cause A: Wrong SPI Speed**
```cpp
// Try slower speed
SD.begin(SD_CS, SPI, 400000);  // 400kHz (very slow, very safe)

// Instead of:
SD.begin(SD_CS);  // Default 4MHz (might be too fast)
```

**Cause B: Card Format**
```
Your phone might format as exFAT (not supported)
Solution: Reformat as FAT32

Windows:
1. Right-click drive → Format
2. File system: FAT32
3. Allocation size: Default
4. Quick Format: Yes

Mac:
1. Disk Utility
2. Erase
3. Format: MS-DOS (FAT)
4. Scheme: Master Boot Record

Linux:
sudo mkfs.vfat -F 32 /dev/sdX1
```

**Cause C: Shared SPI Bus Conflict**
```cpp
// If display is also on SPI, initialize SD AFTER display
tft.init();        // Display first
delay(100);
SD.begin(SD_CS);   // SD card second
```

**Cause D: Power Issues**
```
SD cards draw 50-200mA during init
- Use good quality USB cable
- Try external power supply
- Add 10µF capacitor across VCC/GND on SD module
```

### Issue 2: "No SD card attached" (CARD_NONE)

**This means SD.begin() succeeded but can't detect card type**

Solutions:
1. **Reseat the card** - Remove and reinsert
2. **Clean contacts** - Use isopropyl alcohol on card contacts
3. **Try different card** - Test with another card
4. **Check card lock** - Some cards have physical lock switch

### Issue 3: Card detected but can't read files

**Cause: File system corruption**
```
Solution:
1. Backup card contents on computer
2. Format as FAT32
3. Copy files back
4. Test again
```

### Issue 4: Works sometimes, fails other times

**Cause: Loose connections or power fluctuations**

Solutions:
1. **Solder connections** instead of jumper wires
2. **Add capacitor** - 10µF across VCC/GND near SD module
3. **Shorter wires** - Keep wires under 10cm
4. **Better power supply** - Use 2A+ USB adapter

---

## 🔬 **Advanced Troubleshooting**

### Test 1: Manual SPI Communication
```cpp
SPI.begin(SD_SCK, SD_MISO, SD_MOSI, SD_CS);
digitalWrite(SD_CS, LOW);
uint8_t response = SPI.transfer(0xFF);
digitalWrite(SD_CS, HIGH);

Serial.printf("Response: 0x%02X\n", response);
// Should get 0xFF or 0x01, not 0x00
```

### Test 2: Check Card Voltage
```
Use multimeter:
- Measure VCC pin on SD module
- Should be 3.3V ±0.1V
- If lower: power supply issue
- If higher: wrong voltage!
```

### Test 3: Swap Modules
```
If you have another SD module:
1. Try different module with same card
2. Try same module with different card
3. This isolates hardware vs card issue
```

---

## 📊 **Error Code Reference**

| Error | Meaning | Solution |
|---|---|---|
| `SD.begin() returns false` | Init failed | Check wiring, try slow speed |
| `cardType == CARD_NONE` | No card detected | Reseat card, check insertion |
| `cardSize == 0` | Can't read card | Reformat as FAT32 |
| `SD.open() fails` | File system error | Check format, try different card |

---

## 🎯 **Working Configuration**

Once working, you should see:
```
💾 SD Card... ✅
   Type: SDHC
   Size: 15360 MB
   Used: 245 MB / 15360 MB

📂 Scanning for music files...
   🎵 Song1.mp3
   🎵 Song2.mp3
✅ Found 2 music files
```

---

## 🛠️ **Hardware Fixes**

### Fix 1: Add Pull-up Resistor
Some cards need pull-up on MISO:
```
Add 10kΩ resistor between MISO and 3.3V
```

### Fix 2: Add Decoupling Capacitor
Stabilize power:
```
Add 10µF capacitor between VCC and GND
Place as close to SD module as possible
```

### Fix 3: Level Shifter (if using 5V)
If you must use 5V:
```
Add level shifter between ESP32 (3.3V) and SD module
But better to use 3.3V directly!
```

---

## 📝 **Checklist**

Before asking for help, verify:

**Hardware:**
- [ ] Card fully inserted (clicks in)
- [ ] VCC connected to 3.3V (not 5V)
- [ ] All 6 pins connected correctly
- [ ] No loose wires
- [ ] Good power supply (2A+ USB)

**Software:**
- [ ] Correct pin numbers in code
- [ ] SD.begin() called after SPI.begin()
- [ ] Tried slow speed (400kHz)
- [ ] Serial monitor shows error messages

**Card:**
- [ ] Works in phone/computer
- [ ] Formatted as FAT32
- [ ] 32GB or smaller
- [ ] Not write-protected
- [ ] Contacts are clean

---

## 💡 **Pro Tips**

1. **Start slow** - Use 400kHz speed first, increase later
2. **Test simple** - Try empty card first, add files later
3. **Check basics** - 90% of issues are wiring or power
4. **Use diagnostic** - Run `sd_card_diagnostic.cpp` first
5. **Be patient** - SD cards can be finicky, keep trying!

---

## 🆘 **Still Not Working?**

If you've tried everything:

1. **Post diagnostic output** - Share serial monitor output
2. **Photo of wiring** - Show your connections
3. **Card details** - Brand, size, type
4. **Module details** - Photo of SD module
5. **Power supply** - What are you using?

Most SD card issues are solved by:
- ✅ Fixing wiring (80% of cases)
- ✅ Using slower SPI speed (10% of cases)
- ✅ Reformatting card (5% of cases)
- ✅ Replacing defective module (5% of cases)

Good luck! 🍀

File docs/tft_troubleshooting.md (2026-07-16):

# TFT Display Troubleshooting Guide

## Current Issue: White Screen Only

You're getting a white screen because the backlight is working but the display controller isn't receiving proper signals.

## Step-by-Step Solution

### Step 1: Fix Library Issues

**Problem**: TFT_eSPI has compilation errors with ESP32-S3
**Solution**: Switch to Adafruit libraries (more stable)

1. **Update platformio.ini** (already done):
   ```ini
   lib_deps = 
       adafruit/Adafruit GFX Library@^1.11.9
       adafruit/Adafruit ILI9341@^1.6.0
       adafruit/Adafruit BusIO@^1.14.5
   ```

2. **Use the new test file**: `src/adafruit_tft_test.cpp`

### Step 2: Verify Your Wiring

**Double-check these connections**:
```
ESP32-S3    →    ILI9341 Display
GPIO10      →    CS
GPIO9       →    DC  
GPIO8       →    RST
GPIO11      →    MOSI (SDA)
GPIO12      →    SCLK (SCL)
GPIO13      →    MISO (optional)
3.3V        →    VCC
3.3V        →    LED (backlight)
GND         →    GND
```

### Step 3: Test GPIO Pins First

Before testing display, verify ESP32-S3 pins work:

1. **Upload**: `src/simple_gpio_test.cpp`
2. **Watch Serial Monitor**: Should see pin toggle messages
3. **Optional**: Use multimeter to verify 3.3V on pins

### Step 4: Test Display with Adafruit Library

1. **Upload**: `src/adafruit_tft_test.cpp`
2. **Expected Results**:
   - Serial: "Display initialized!"
   - Screen: Red → Green → Blue → Text and shapes
   - Blinking white dot

### Step 5: If Still White Screen

**Check these common issues**:

1. **Power Supply**:
   - ESP32-S3 needs stable 3.3V
   - Display draws ~50mA
   - USB power should be sufficient

2. **Wiring Issues**:
   - Loose breadboard connections
   - Wrong GPIO pins
   - Crossed wires

3. **Display Issues**:
   - Some ILI9341 displays need different initialization
   - Try different SPI speeds

### Step 6: Alternative Test Code

If Adafruit library doesn't work, try this minimal test:

```cpp
#include <SPI.h>

#define TFT_CS    10
#define TFT_DC    9  
#define TFT_RST   8

void setup() {
  Serial.begin(115200);
  
  // Initialize pins
  pinMode(TFT_CS, OUTPUT);
  pinMode(TFT_DC, OUTPUT);
  pinMode(TFT_RST, OUTPUT);
  
  // Reset display
  digitalWrite(TFT_RST, LOW);
  delay(100);
  digitalWrite(TFT_RST, HIGH);
  delay(100);
  
  // Initialize SPI
  SPI.begin(12, 13, 11, 10);  // SCLK, MISO, MOSI, CS
  SPI.setFrequency(1000000);  // 1MHz (slow and safe)
  
  Serial.println("Basic SPI test - check for any response");
}
```

## Next Steps

1. **Try GPIO test first** - verify ESP32-S3 pins work
2. **Upload Adafruit test** - should show colors
3. **If still white**: Check wiring with multimeter
4. **Report results**: Tell me what you see in Serial Monitor

## Common ESP32-S3 Issues

- **USB Connection**: Use data cable, not charge-only
- **Boot Mode**: Hold BOOT button while uploading if needed
- **Power**: Some displays need external 5V (yours should work on 3.3V)
- **SPI Speed**: Try slower speeds if display glitches

## Success Indicators

✅ **GPIO Test**: Pin toggle messages in Serial Monitor
✅ **Display Test**: Colors, text, and shapes on screen  
✅ **Serial Output**: "Display initialized!" message
✅ **Animation**: Blinking white dot in center

Let me know what happens with each test!

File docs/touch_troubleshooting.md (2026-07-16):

# Touch Troubleshooting Guide - Fix Intermittent Touch

## 🔍 Common Causes of Intermittent Touch

### **1. Hardware Issues (Most Common)**
- ❌ **Loose breadboard connections** - Touch pins not making good contact
- ❌ **Poor power supply** - Insufficient or noisy 3.3V power
- ❌ **Electrical interference** - Long wires picking up noise
- ❌ **Dirty screen** - Fingerprints affecting capacitive touch

### **2. Software Issues**
- ❌ **Poor debouncing** - Touch events firing multiple times
- ❌ **Incorrect calibration** - Touch coordinates mapping incorrectly
- ❌ **Timing issues** - Reading touch too fast or too slow

### **3. Environmental Issues**
- ❌ **Temperature changes** - Affects touch sensitivity
- ❌ **Humidity** - Can affect capacitive touch
- ❌ **Electromagnetic interference** - From other devices

## 🔧 Step-by-Step Fixes

### **Step 1: Hardware Diagnosis**

#### **Check Wiring:**
```
ESP32-S3    →    MSP2806 Touch
GPIO6       →    T_CS (Touch Chip Select)
GPIO7       →    T_CLK (Touch Clock)
GPIO5       →    T_DIN (Touch Data In)
GPIO4       →    T_DO (Touch Data Out)
GPIO3       →    T_IRQ (Touch Interrupt - optional)
3.3V        →    VCC (shared with display)
GND         →    GND (shared with display)
```

#### **Improve Connections:**
1. **Use shorter wires** (< 10cm if possible)
2. **Twist SPI wire pairs** (CLK+DIN, CS+DO)
3. **Solid breadboard connections** - push wires firmly
4. **Add bypass capacitors** - 100nF near touch controller

### **Step 2: Test Touch Quality**

Upload **`src/touch_diagnostic.cpp`** to analyze touch behavior:

```cpp
// Expected results:
// ✅ Success rate > 90%
// ✅ Max consecutive misses < 5
// ✅ Consistent touch coordinates
```

### **Step 3: Use Improved Touch Handler**

Upload **`src/improved_touch_handler.cpp`** which includes:
- ✅ **Better debouncing** - Requires multiple consecutive reads
- ✅ **Missed read tolerance** - Handles intermittent signals
- ✅ **Touch confirmation** - Validates touch before processing
- ✅ **Visual feedback** - Shows touch quality

### **Step 4: Adjust Touch Settings**

In your code, try these improvements:

#### **Increase Debounce Time:**
```cpp
#define TOUCH_DEBOUNCE_MS 50        // Increase from 30ms
#define MIN_CONSECUTIVE_READS 3     // Increase from 2
#define MAX_MISSED_READS 5          // Increase from 3
```

#### **Add Touch Filtering:**
```cpp
bool isValidTouch(uint16_t x, uint16_t y) {
  // Filter out edge touches (often unreliable)
  if (x < 10 || x > 230 || y < 10 || y > 310) return false;
  
  // Filter out rapid position changes (noise)
  static uint16_t lastX = 0, lastY = 0;
  int deltaX = abs((int)x - (int)lastX);
  int deltaY = abs((int)y - (int)lastY);
  
  if (deltaX > 50 || deltaY > 50) return false;
  
  lastX = x; lastY = y;
  return true;
}
```

#### **Implement Touch Averaging:**
```cpp
struct TouchAverage {
  uint16_t x[5], y[5];
  int index = 0;
  int count = 0;
};

TouchAverage touchAvg;

void addTouchSample(uint16_t x, uint16_t y) {
  touchAvg.x[touchAvg.index] = x;
  touchAvg.y[touchAvg.index] = y;
  touchAvg.index = (touchAvg.index + 1) % 5;
  if (touchAvg.count < 5) touchAvg.count++;
}

bool getAveragedTouch(uint16_t &x, uint16_t &y) {
  if (touchAvg.count < 3) return false;
  
  uint32_t sumX = 0, sumY = 0;
  for (int i = 0; i < touchAvg.count; i++) {
    sumX += touchAvg.x[i];
    sumY += touchAvg.y[i];
  }
  
  x = sumX / touchAvg.count;
  y = sumY / touchAvg.count;
  return true;
}
```

### **Step 5: Hardware Improvements**

#### **Power Supply Fixes:**
```cpp
// Add power filtering
// Hardware: 100µF capacitor near ESP32-S3
// Hardware: 10µF + 100nF capacitors near display

// Software: Check power stability
void checkPowerStability() {
  float voltage = analogRead(A0) * 3.3 / 4095.0;
  if (voltage < 3.2) {
    Serial.println("WARNING: Low voltage detected");
  }
}
```

#### **Reduce Electrical Noise:**
1. **Separate power and signal wires**
2. **Use twisted pair for SPI signals**
3. **Keep wires away from switching circuits**
4. **Add ferrite beads on long wires**

### **Step 6: Software Optimizations**

#### **Optimized Touch Reading:**
```cpp
class ReliableTouch {
private:
  static const int SAMPLE_COUNT = 5;
  uint16_t xSamples[SAMPLE_COUNT];
  uint16_t ySamples[SAMPLE_COUNT];
  int sampleIndex = 0;
  bool hasValidSamples = false;
  
public:
  bool getStableTouch(uint16_t &x, uint16_t &y) {
    uint16_t rawX, rawY;
    
    if (!tft.getTouch(&rawX, &rawY)) {
      hasValidSamples = false;
      return false;
    }
    
    // Add sample
    xSamples[sampleIndex] = rawX;
    ySamples[sampleIndex] = rawY;
    sampleIndex = (sampleIndex + 1) % SAMPLE_COUNT;
    
    if (!hasValidSamples) {
      hasValidSamples = true;
      return false; // Need more samples
    }
    
    // Calculate median (more stable than average)
    x = getMedian(xSamples, SAMPLE_COUNT);
    y = getMedian(ySamples, SAMPLE_COUNT);
    
    return true;
  }
  
private:
  uint16_t getMedian(uint16_t arr[], int n) {
    // Simple bubble sort for small arrays
    for (int i = 0; i < n-1; i++) {
      for (int j = 0; j < n-i-1; j++) {
        if (arr[j] > arr[j+1]) {
          uint16_t temp = arr[j];
          arr[j] = arr[j+1];
          arr[j+1] = temp;
        }
      }
    }
    return arr[n/2];
  }
};
```

## 🎯 Quick Fixes to Try First

### **1. Immediate Hardware Fixes:**
```bash
# Check these connections first:
1. Push all breadboard wires firmly
2. Check 3.3V voltage with multimeter
3. Clean the display screen
4. Try shorter jumper wires
```

### **2. Software Quick Fix:**
```cpp
// Add this to your touch handling:
void handleTouch() {
  static unsigned long lastTouch = 0;
  uint16_t x, y;
  
  if (millis() - lastTouch < 100) return; // 100ms debounce
  
  if (tft.getTouch(&x, &y)) {
    // Confirm touch with second reading
    delay(10);
    uint16_t x2, y2;
    if (tft.getTouch(&x2, &y2)) {
      // Average the two readings
      x = (x + x2) / 2;
      y = (y + y2) / 2;
      
      processTouch(x, y);
      lastTouch = millis();
    }
  }
}
```

### **3. Calibration Fix:**
```cpp
// Force recalibration
void forceRecalibration() {
  uint16_t calData[5];
  tft.calibrateTouch(calData, TFT_MAGENTA, TFT_BLACK, 15);
  
  // Save calibration
  // (implement SPIFFS save here)
}
```

## 📊 Success Metrics

### **Good Touch Performance:**
- ✅ **Success rate > 95%**
- ✅ **Response time < 100ms**
- ✅ **Coordinate accuracy ± 5 pixels**
- ✅ **No false touches**
- ✅ **Consistent behavior**

### **Poor Touch Performance:**
- ❌ **Success rate < 80%**
- ❌ **Delayed or missed touches**
- ❌ **Coordinate jumping**
- ❌ **False touches**
- ❌ **Dead zones**

## 🔄 Testing Procedure

1. **Upload touch diagnostic** - Measure current performance
2. **Check hardware** - Verify all connections
3. **Upload improved handler** - Test with better software
4. **Adjust settings** - Fine-tune parameters
5. **Validate performance** - Confirm improvements

The improved touch handler should solve most intermittent touch issues. If problems persist, it's likely a hardware connection problem that needs physical inspection and rewiring.

## 🆘 Last Resort Fixes

If touch is still unreliable:

1. **Try different GPIO pins** - Some pins may have better signal integrity
2. **Use external pull-up resistors** - 10kΩ on SPI lines
3. **Add bypass capacitors** - 100nF on power lines
4. **Check for damaged display** - Touch controller may be faulty
5. **Use alternative touch library** - Try XPT2046_Touchscreen library directly

The key is systematic troubleshooting - start with the diagnostic tool to understand the problem, then apply the appropriate fixes!

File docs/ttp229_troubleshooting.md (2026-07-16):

# TTP229 Gesture Troubleshooting Guide

## 🔍 **Step-by-Step Debugging**

### **Step 1: Check Basic Touch Detection**

Upload `src/ttp229_simple_test.cpp` and open Serial Monitor (115200 baud).

**Expected Output:**
```
✅ TTP229 found at address 0x57
Touch any key (1-16)...
```

**When you touch a key:**
```
Touch detected! Raw value: 0x0001 (0000000000000001) - Keys: 1
Touch detected! Raw value: 0x0002 (0000000000000010) - Keys: 2
```

---

## 🚨 **Common Issues & Fixes**

### **Issue 1: "TTP229 NOT found!"**

**Symptoms:**
```
❌ TTP229 NOT found! Error: 2
```

**Causes & Solutions:**

#### **A. Wrong I2C Pins**
```
Check your wiring:
TTP229 SCL → ESP32-S3 GPIO2 (not GPIO22!)
TTP229 SDO → ESP32-S3 GPIO1 (not GPIO21!)

ESP32-S3 uses GPIO1/2 for I2C, not 21/22!
```

#### **B. Swapped SDA/SCL**
```
Try swapping:
If SCL is on GPIO1 and SDO on GPIO2, swap them:
TTP229 SCL → GPIO2
TTP229 SDO → GPIO1
```

#### **C. Power Issue**
```
Check:
1. VCC connected to 3.3V (NOT 5V!)
2. GND connected properly
3. Power LED on TTP229 lit (if present)
4. Try different 3.3V pin on ESP32-S3
```

#### **D. Bad Connections**
```
1. Push wires firmly into breadboard
2. Check for loose connections
3. Try different jumper wires
4. Check breadboard power rails
```

---

### **Issue 2: Touch Detected But No Gestures**

**Symptoms:**
```
✅ TTP229 found
✅ Keys detected when touched
❌ Gestures not recognized
```

**Solutions:**

#### **A. Gesture Too Fast**
```
Problem: Moving too quickly
Solution: Slow down your swipe/scroll motion
Try: 1-2 seconds for full swipe
```

#### **B. Gesture Too Slow**
```
Problem: Moving too slowly
Solution: Speed up slightly
Try: Complete gesture in 0.5-1 second
```

#### **C. Not Enough Keys**
```
Problem: Only touching 1-2 keys
Solution: Touch more keys in sequence
For swipe: Touch at least 3 keys
For scroll: Touch at least 4 keys in circular pattern
```

#### **D. Erratic Path**
```
Problem: Touching random keys
Solution: Follow straight or circular path
For swipe up: 13→9→5→1 (straight line)
For scroll CW: 1→2→3→4→8→12→16 (circular)
```

---

### **Issue 3: Inconsistent Detection**

**Symptoms:**
```
Sometimes works, sometimes doesn't
```

**Solutions:**

#### **A. Adjust Timing Thresholds**

In `src/ttp229_gesture_ipod.cpp`, modify:

```cpp
// Make gestures easier to detect
#define TAP_THRESHOLD 300        // Was 200ms
#define LONG_PRESS_THRESHOLD 400 // Was 500ms
#define SWIPE_MIN_KEYS 2         // Was 2 (keep same)
#define SCROLL_THRESHOLD 2       // Was 3 (easier)
```

#### **B. Increase Touch History**

```cpp
// Remember more touches
#define TOUCH_HISTORY_SIZE 15    // Was 10
```

#### **C. Clean Touch Pads**
```
1. Wipe pads with dry cloth
2. Ensure fingers are dry
3. Press firmly but not too hard
4. Touch center of each pad
```

---

### **Issue 4: Only Tap Works, No Swipes**

**Symptoms:**
```
✅ Tap detected
❌ Swipe not detected
❌ Scroll not detected
```

**Debug Steps:**

#### **1. Check Serial Monitor**
```
Look for:
"🎯 Gesture detected: TAP" ← Working
"🎯 Gesture detected: SWIPE UP" ← Not working?
```

#### **2. Print Touch History**

Add this to `handleTouch()` in gesture code:

```cpp
// After touch end, print history
if (touchStatus == 0 && lastTouchStatus != 0) {
  Serial.print("Touch history: ");
  for (int i = 0; i < TOUCH_HISTORY_SIZE; i++) {
    if (touchHistory[i] > 0) {
      Serial.print(touchHistory[i]);
      Serial.print(" ");
    }
  }
  Serial.println();
}
```

**Expected for swipe up:**
```
Touch history: 13 9 5 1
```

**If you see:**
```
Touch history: 13 13 13 13  ← Only one key, not moving
Touch history: 13 7 2 16    ← Random keys, not straight line
```

#### **3. Simplify Gesture Detection**

Try this simpler swipe detection:

```cpp
GestureType detectSwipeDirection() {
  int firstKey = -1, lastKey = -1;
  
  // Get first and last keys
  for (int i = 0; i < TOUCH_HISTORY_SIZE; i++) {
    if (touchHistory[i] > 0) {
      if (firstKey == -1) firstKey = touchHistory[i];
      lastKey = touchHistory[i];
    }
  }
  
  if (firstKey == -1 || lastKey == -1) return GESTURE_NONE;
  
  // Simple direction check
  if (lastKey < firstKey - 4) return GESTURE_SWIPE_UP;
  if (lastKey > firstKey + 4) return GESTURE_SWIPE_DOWN;
  if ((lastKey % 4) > (firstKey % 4)) return GESTURE_SWIPE_RIGHT;
  if ((lastKey % 4) < (firstKey % 4)) return GESTURE_SWIPE_LEFT;
  
  return GESTURE_NONE;
}
```

---

### **Issue 5: False Gesture Detection**

**Symptoms:**
```
Gestures detected when not intended
Random swipes/scrolls
```

**Solutions:**

#### **A. Increase Thresholds**
```cpp
#define TAP_THRESHOLD 150        // Stricter (was 200)
#define SWIPE_MIN_KEYS 3         // Need more keys (was 2)
#define SCROLL_THRESHOLD 4       // Need more keys (was 3)
```

#### **B. Add Minimum Distance**
```cpp
// In detectSwipeDirection()
int distance = abs(lastKey - firstKey);
if (distance < 4) return GESTURE_NONE; // Too short
```

#### **C. Debounce Touches**
```cpp
// In handleTouch()
static unsigned long lastGestureTime = 0;
if (millis() - lastGestureTime < 500) return; // Ignore rapid gestures
lastGestureTime = millis();
```

---

## 🧪 **Testing Gestures**

### **Test Each Gesture Individually:**

#### **1. Test Tap**
```
Action: Quick touch key 6 (center)
Expected: "🎯 Gesture detected: TAP"
Duration: < 200ms
```

#### **2. Test Swipe Up**
```
Action: Touch 13 → 9 → 5 → 1 (bottom to top)
Expected: "🎯 Gesture detected: SWIPE UP"
Speed: 1 second for full swipe
```

#### **3. Test Swipe Down**
```
Action: Touch 1 → 5 → 9 → 13 (top to bottom)
Expected: "🎯 Gesture detected: SWIPE DOWN"
```

#### **4. Test Swipe Left**
```
Action: Touch 4 → 3 → 2 → 1 (right to left)
Expected: "🎯 Gesture detected: SWIPE LEFT"
```

#### **5. Test Swipe Right**
```
Action: Touch 1 → 2 → 3 → 4 (left to right)
Expected: "🎯 Gesture detected: SWIPE RIGHT"
```

#### **6. Test Circular Scroll**
```
Action: Touch 1 → 2 → 3 → 4 → 8 → 12 (clockwise arc)
Expected: "🎯 Gesture detected: SCROLL CLOCKWISE"
Speed: 1-2 seconds for arc
```

---

## 💡 **Pro Tips**

### **For Better Gesture Recognition:**

1. **Touch firmly** - Don't just graze the pads
2. **Move smoothly** - Consistent speed
3. **Follow paths** - Straight lines or circular arcs
4. **Practice** - Gestures improve with practice
5. **Check Serial** - Monitor shows what's detected

### **Optimal Gesture Speed:**
```
Tap:         < 200ms
Swipe:       500-1000ms
Scroll:      1000-2000ms
Long Press:  > 500ms
```

### **Optimal Touch Pattern:**
```
Swipe:  Touch 3-4 keys in line
Scroll: Touch 4-6 keys in arc
Tap:    Single key, quick release
```

---

## 🔧 **Quick Fixes**

### **If Nothing Works:**

1. **Upload simple test first:**
   ```
   src/ttp229_simple_test.cpp
   ```

2. **Verify each key works:**
   ```
   Touch keys 1-16 individually
   All should register
   ```

3. **Check wiring again:**
   ```
   VCC → 3.3V
   GND → GND
   SCL → GPIO2
   SDO → GPIO1
   ```

4. **Try different I2C pins:**
   ```cpp
   #define I2C_SDA 3  // Try GPIO3
   #define I2C_SCL 4  // Try GPIO4
   ```

5. **Reduce gesture complexity:**
   ```
   Start with just tap and swipe
   Add scroll later when working
   ```

---

## 📊 **Expected Behavior**

### **Working System:**
```
✅ TTP229 detected on I2C
✅ All 16 keys respond to touch
✅ Tap gesture works reliably
✅ Swipe gestures work (may need practice)
✅ Scroll gestures work (requires smooth motion)
✅ Serial Monitor shows gesture names
✅ Display updates with gestures
```

### **Partially Working:**
```
✅ TTP229 detected
✅ Keys respond
⚠️ Only tap works
❌ Swipes not detected
```
**Solution:** Adjust timing thresholds, slow down gestures

### **Not Working:**
```
❌ TTP229 not detected
```
**Solution:** Check wiring, especially GPIO1/2

---

## 🎯 **Final Checklist**

Before asking for help, verify:

- [ ] TTP229 detected in simple test
- [ ] All 16 keys respond individually
- [ ] Wiring correct (GPIO1/2, not 21/22)
- [ ] Power is 3.3V (not 5V)
- [ ] Serial Monitor shows touch events
- [ ] Tried adjusting timing thresholds
- [ ] Practiced gesture motions
- [ ] Checked for loose connections

If all checked and still not working, provide:
1. Serial Monitor output
2. Photo of wiring
3. Which gestures work/don't work
4. Touch history output

This will help diagnose the specific issue! 🚀

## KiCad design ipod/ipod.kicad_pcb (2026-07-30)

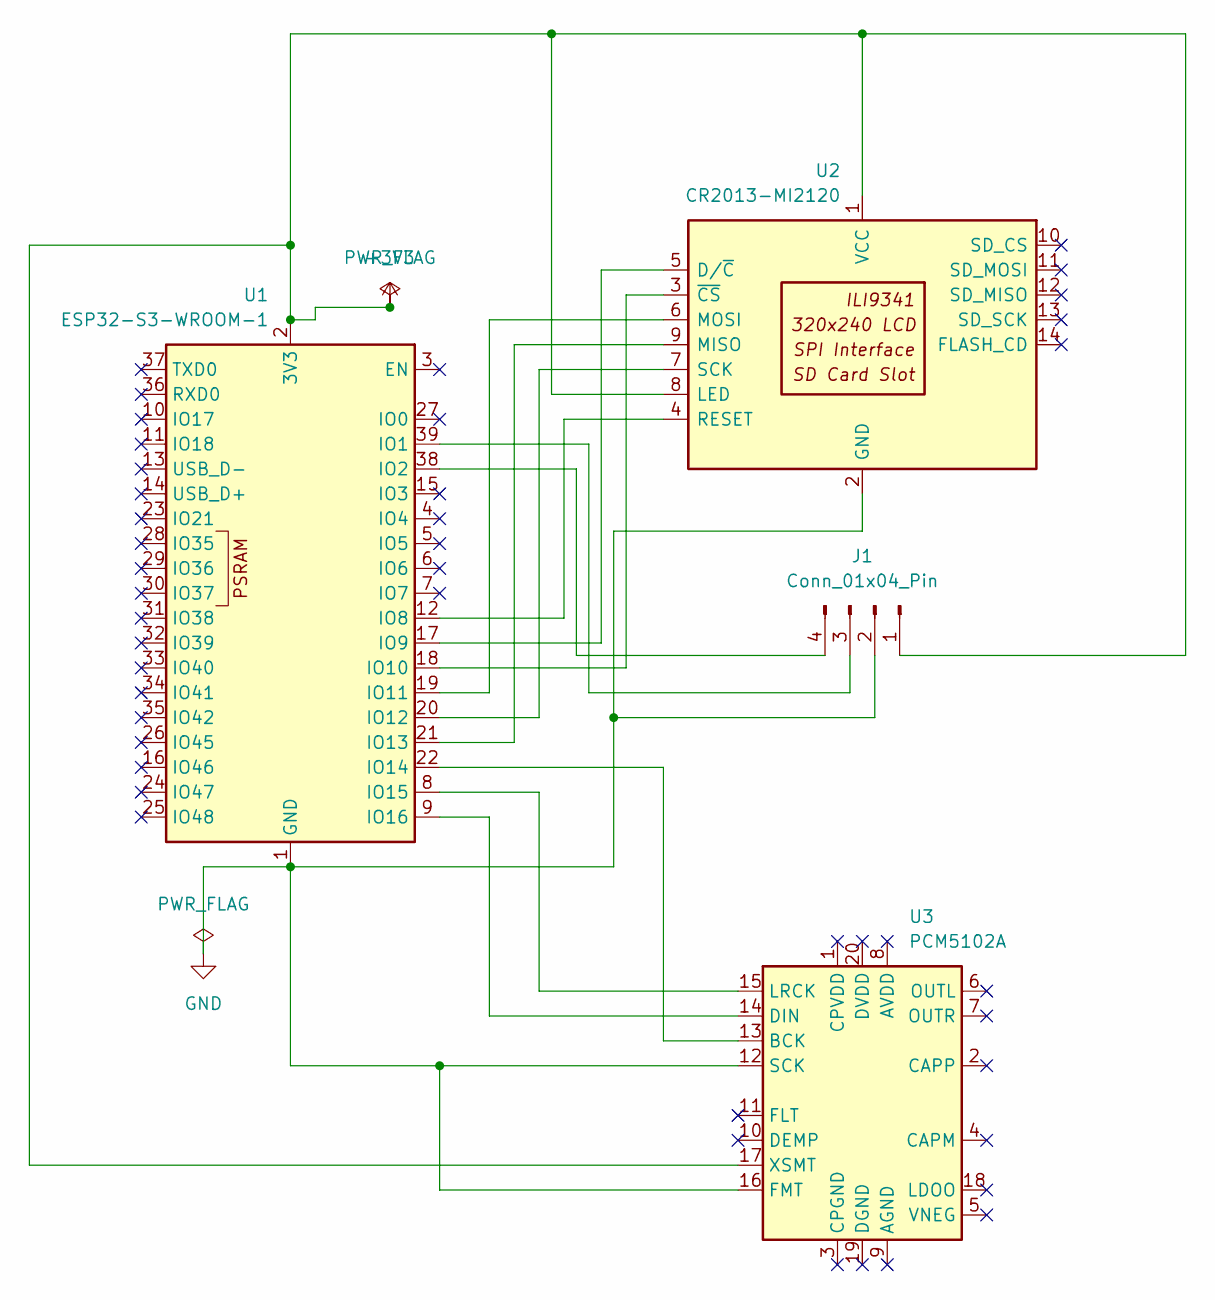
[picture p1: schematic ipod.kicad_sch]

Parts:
J1: Conn_01x04_Pin; FanPinHeader_1x04_P2.54mm_Vertical
U1: ESP32-S3-WROOM-1
U2: CR2013-MI2120
U3: PCM5102A; TSSOP-20_4.4x6.5mm_P0.65mm

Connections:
+3V3: J1.1, U1.2 (3V3), U2.1 (VCC), U2.8 (LED), U3.17 (XSMT)
GND: J1.2, U1.1 (GND), U1.40 (GND), U1.41 (GND), U2.2 (GND), U3.12 (SCK), U3.16 (FMT)
unnamed: J1.3, U1.39 (IO1)
unnamed: J1.4, U1.38 (IO2)
unnamed: U1.12 (IO8), U2.4 (RESET)
unnamed: U1.17 (IO9), U2.5 (D/~C)
unnamed: U1.18 (IO10), U2.3 (~CS)
unnamed: U1.19 (IO11), U2.6 (MOSI)
unnamed: U1.20 (IO12), U2.7 (SCK)
unnamed: U1.21 (IO13), U2.9 (MISO)
unnamed: U1.22 (IO14), U3.13 (BCK)
unnamed: U1.8 (IO15), U3.15 (LRCK)
unnamed: U1.9 (IO16), U3.14 (DIN)

Board: 2 copper layers, 4 parts (0 on the bottom side), 13 nets, no tracks yet.

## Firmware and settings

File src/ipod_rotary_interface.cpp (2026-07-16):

/*
ESP32-S3 iPod with Rotary Encoder Interface
Classic iPod-style navigation with scroll wheel and buttons
*/

#include <TFT_eSPI.h>

TFT_eSPI tft = TFT_eSPI();

// Rotary Encoder Pins (using available GPIOs)
#define ENCODER_CLK  0    // Rotary encoder clock
#define ENCODER_DT   1    // Rotary encoder data  
#define ENCODER_SW   2    // Rotary encoder switch (center button)

// Navigation Buttons (iPod-style)
#define BTN_MENU     14   // Menu button (back/up)
#define BTN_PLAY     15   // Play/Pause button
#define BTN_PREV     16   // Previous track
#define BTN_NEXT     17   // Next track

// Colors
#define BLACK 0x0000
#define WHITE 0xFFFF
#define BLUE 0x001F
#define GRAY 0x8410
#define LIGHT_GRAY 0xC618
#define DARK_GRAY 0x4208
#define GREEN 0x07E0
#define RED 0xF800
#define CYAN 0x07FF

// UI State
enum Screen { HOME, LIBRARY, NOW_PLAYING, SETTINGS };
Screen currentScreen = HOME;
int selectedItem = 0;
int maxItems = 4;
bool isPlaying = false;
int volume = 50;
int currentSong = 0;

// Encoder state
volatile int encoderPos = 0;
volatile bool encoderChanged = false;
int lastEncoderPos = 0;

// Button state
bool lastMenuState = HIGH;
bool lastPlayState = HIGH;
bool lastPrevState = HIGH;
bool lastNextState = HIGH;
unsigned long lastButtonTime = 0;

// Sample data
const char* menuItems[] = {"Music Library", "Now Playing", "Settings", "About"};
const char* songs[] = {
  "Bohemian Rhapsody", "Stairway to Heaven", "Hotel California", 
  "Imagine", "Sweet Child O' Mine", "Billie Jean"
};
const char* artists[] = {
  "Queen", "Led Zeppelin", "Eagles", 
  "John Lennon", "Guns N' Roses", "Michael Jackson"
};

void setup() {
  Serial.begin(115200);
  delay(2000);
  
  Serial.println("╔════════════════════════════════════════╗");
  Serial.println("║    ESP32-S3 iPod Rotary Interface     ║");
  Serial.println("║      Classic iPod Navigation          ║");
  Serial.println("╚════════════════════════════════════════╝");
  Serial.println();
  
  // Initialize display
  tft.init();
  tft.setRotation(0);
  tft.fillScreen(BLACK);
  
  // Setup rotary encoder
  setupEncoder();
  
  // Setup buttons
  setupButtons();
  
  // Show splash
  showSplash();
  
  // Start with home screen
  currentScreen = HOME;
  updateMaxItems();
  drawScreen();
  
  Serial.println("🎮 iPod Interface Ready!");
  Serial.println("   Rotary Encoder: Scroll through items");
  Serial.println("   Center Button: Select item");
  Serial.println("   Menu Button: Go back");
  Serial.println("   Play Button: Play/Pause");
  Serial.println("   Prev/Next: Change tracks");
  Serial.println();
}

void loop() {
  handleEncoder();
  handleButtons();
  updateUI();
  delay(10);
}

void setupEncoder() {
  pinMode(ENCODER_CLK, INPUT_PULLUP);
  pinMode(ENCODER_DT, INPUT_PULLUP);
  pinMode(ENCODER_SW, INPUT_PULLUP);
  
  // Attach interrupts for smooth encoder reading
  attachInterrupt(digitalPinToInterrupt(ENCODER_CLK), encoderISR, CHANGE);
  attachInterrupt(digitalPinToInterrupt(ENCODER_DT), encoderISR, CHANGE);
  
  Serial.println("🔄 Rotary encoder configured:");
  Serial.print("   CLK: GPIO");
  Serial.println(ENCODER_CLK);
  Serial.print("   DT:  GPIO");
  Serial.println(ENCODER_DT);
  Serial.print("   SW:  GPIO");
  Serial.println(ENCODER_SW);
}

void setupButtons() {
  pinMode(BTN_MENU, INPUT_PULLUP);
  pinMode(BTN_PLAY, INPUT_PULLUP);
  pinMode(BTN_PREV, INPUT_PULLUP);
  pinMode(BTN_NEXT, INPUT_PULLUP);
  
  Serial.println("🔘 Navigation buttons configured:");
  Serial.print("   Menu: GPIO");
  Serial.println(BTN_MENU);
  Serial.print("   Play: GPIO");
  Serial.println(BTN_PLAY);
  Serial.print("   Prev: GPIO");
  Serial.println(BTN_PREV);
  Serial.print("   Next: GPIO");
  Serial.println(BTN_NEXT);
}

void IRAM_ATTR encoderISR() {
  static unsigned long lastInterruptTime = 0;
  unsigned long interruptTime = millis();
  
  // Debounce
  if (interruptTime - lastInterruptTime > 5) {
    bool clkState = digitalRead(ENCODER_CLK);
    bool dtState = digitalRead(ENCODER_DT);
    
    if (clkState != dtState) {
      encoderPos++;
    } else {
      encoderPos--;
    }
    
    encoderChanged = true;
    lastInterruptTime = interruptTime;
  }
}

void handleEncoder() {
  if (encoderChanged) {
    encoderChanged = false;
    
    int change = encoderPos - lastEncoderPos;
    lastEncoderPos = encoderPos;
    
    if (change != 0) {
      Serial.print("🔄 Encoder: ");
      Serial.print(change > 0 ? "CW" : "CCW");
      Serial.print(" (");
      Serial.print(change);
      Serial.println(")");
      
      // Handle encoder movement based on current screen
      if (change > 0) {
        navigateDown();
      } else {
        navigateUp();
      }
    }
  }
  
  // Handle encoder button (center select)
  static bool lastSwState = HIGH;
  bool swState = digitalRead(ENCODER_SW);
  
  if (swState == LOW && lastSwState == HIGH) {
    delay(50); // Debounce
    if (digitalRead(ENCODER_SW) == LOW) {
      Serial.println("🔘 Encoder button pressed (SELECT)");
      handleSelect();
    }
  }
  lastSwState = swState;
}

void handleButtons() {
  unsigned long currentTime = millis();
  if (currentTime - lastButtonTime < 50) return; // Debounce
  
  // Menu button
  bool menuState = digitalRead(BTN_MENU);
  if (menuState == LOW && lastMenuState == HIGH) {
    Serial.println("🔘 Menu button pressed");
    handleMenu();
    lastButtonTime = currentTime;
  }
  lastMenuState = menuState;
  
  // Play button
  bool playState = digitalRead(BTN_PLAY);
  if (playState == LOW && lastPlayState == HIGH) {
    Serial.println("🔘 Play button pressed");
    handlePlay();
    lastButtonTime = currentTime;
  }
  lastPlayState = playState;
  
  // Previous button
  bool prevState = digitalRead(BTN_PREV);
  if (prevState == LOW && lastPrevState == HIGH) {
    Serial.println("🔘 Previous button pressed");
    handlePrevious();
    lastButtonTime = currentTime;
  }
  lastPrevState = prevState;
  
  // Next button
  bool nextState = digitalRead(BTN_NEXT);
  if (nextState == LOW && lastNextState == HIGH) {
    Serial.println("🔘 Next button pressed");
    handleNext();
    lastButtonTime = currentTime;
  }
  lastNextState = nextState;
}

void navigateUp() {
  selectedItem--;
  if (selectedItem < 0) {
    selectedItem = maxItems - 1; // Wrap around
  }
  drawScreen();
}

void navigateDown() {
  selectedItem++;
  if (selectedItem >= maxItems) {
    selectedItem = 0; // Wrap around
  }
  drawScreen();
}

void handleSelect() {
  switch (currentScreen) {
    case HOME:
      switch (selectedItem) {
        case 0: currentScreen = LIBRARY; break;
        case 1: currentScreen = NOW_PLAYING; break;
        case 2: currentScreen = SETTINGS; break;
        case 3: showAbout(); return;
      }
      selectedItem = 0;
      updateMaxItems();
      drawScreen();
      break;
      
    case LIBRARY:
      currentSong = selectedItem;
      currentScreen = NOW_PLAYING;
      selectedItem = 0;
      updateMaxItems();
      drawScreen();
      break;
      
    case NOW_PLAYING:
      // Handle now playing selections (play/pause, etc.)
      if (selectedItem == 0) {
        togglePlayPause();
      }
      break;
      
    case SETTINGS:
      // Handle settings selections
      break;
  }
}

void handleMenu() {
  if (currentScreen != HOME) {
    currentScreen = HOME;
    selectedItem = 0;
    updateMaxItems();
    drawScreen();
  }
}

void handlePlay() {
  togglePlayPause();
}

void handlePrevious() {
  if (currentScreen == NOW_PLAYING) {
    currentSong = (currentSong - 1 + 6) % 6;
    drawScreen();
  } else {
    navigateUp();
  }
}

void handleNext() {
  if (currentScreen == NOW_PLAYING) {
    currentSong = (currentSong + 1) % 6;
    drawScreen();
  } else {
    navigateDown();
  }
}

void togglePlayPause() {
  isPlaying = !isPlaying;
  Serial.print("🎵 ");
  Serial.println(isPlaying ? "Playing" : "Paused");
  if (currentScreen == NOW_PLAYING) {
    drawScreen();
  }
}

void updateMaxItems() {
  switch (currentScreen) {
    case HOME: maxItems = 4; break;
    case LIBRARY: maxItems = 6; break;
    case NOW_PLAYING: maxItems = 1; break;
    case SETTINGS: maxItems = 3; break;
  }
}

void showSplash() {
  tft.fillScreen(BLACK);
  
  // iPod logo
  tft.setTextSize(4);
  tft.setTextColor(WHITE);
  tft.setCursor(60, 120);
  tft.print("iPod");
  
  tft.setTextSize(1);
  tft.setTextColor(CYAN);
  tft.setCursor(70, 160);
  tft.print("Rotary Interface");
  
  delay(2000);
  tft.fillScreen(BLACK);
}

void drawScreen() {
  tft.fillScreen(BLACK);
  
  switch (currentScreen) {
    case HOME:
      drawHome();
      break;
    case LIBRARY:
      drawLibrary();
      break;
    case NOW_PLAYING:
      drawNowPlaying();
      break;
    case SETTINGS:
      drawSettings();
      break;
  }
  
  drawScrollIndicator();
}

void drawHome() {
  // Title
  tft.setTextSize(3);
  tft.setTextColor(WHITE);
  tft.setCursor(20, 20);
  tft.print("iPod");
  
  // Menu items
  for (int i = 0; i < 4; i++) {
    int y = 70 + (i * 35);
    
    // Highlight selected item
    if (i == selectedItem) {
      tft.fillRoundRect(10, y - 5, 220, 30, 5, BLUE);
    }
    
    tft.setTextSize(2);
    tft.setTextColor(WHITE);
    tft.setCursor(20, y);
    tft.print(menuItems[i]);
    
    // Arrow for selected item
    if (i == selectedItem) {
      tft.setCursor(200, y);
      tft.print(">");
    }
  }
  
  drawStatusBar();
}

void drawLibrary() {
  // Header
  drawHeader("Music Library");
  
  // Song list
  for (int i = 0; i < 6; i++) {
    int y = 80 + (i * 30);
    
    // Highlight selected item
    if (i == selectedItem) {
      tft.fillRoundRect(5, y - 3, 230, 25, 3, BLUE);
    }
    
    // Playing indicator
    if (i == currentSong && isPlaying) {
      tft.fillRoundRect(5, y - 3, 230, 25, 3, DARK_GRAY);
    }
    
    tft.setTextSize(1);
    tft.setTextColor(WHITE);
    tft.setCursor(10, y);
    tft.print(songs[i]);
    
    tft.setTextColor(GRAY);
    tft.setCursor(10, y + 12);
    tft.print(artists[i]);
    
    // Playing indicator
    if (i == currentSong && isPlaying) {
      tft.setTextColor(GREEN);
      tft.setCursor(210, y + 6);
      tft.print("♪");
    }
    
    // Selection arrow
    if (i == selectedItem) {
      tft.setTextColor(WHITE);
      tft.setCursor(220, y + 6);
      tft.print(">");
    }
  }
  
  drawStatusBar();
}

void drawNowPlaying() {
  // Header
  drawHeader("Now Playing");
  
  // Album art placeholder
  tft.drawRoundRect(60, 80, 120, 120, 10, WHITE);
  tft.fillRoundRect(62, 82, 116, 116, 8, DARK_GRAY);
  
  // Music note
  tft.setTextSize(6);
  tft.setTextColor(GRAY);
  tft.setCursor(105, 125);
  tft.print("♪");
  
  // Song info
  tft.setTextSize(1);
  tft.setTextColor(WHITE);
  tft.setCursor(20, 210);
  tft.print(songs[currentSong]);
  
  tft.setTextColor(GRAY);
  tft.setCursor(20, 225);
  tft.print(artists[currentSong]);
  
  // Play/Pause indicator
  tft.setTextSize(2);
  tft.setTextColor(isPlaying ? GREEN : RED);
  tft.setCursor(20, 250);
  tft.print(isPlaying ? "Playing" : "Paused");
  
  drawStatusBar();
}

void drawSettings() {
  drawHeader("Settings");
  
  const char* settings[] = {"Display", "Audio", "About"};
  
  for (int i = 0; i < 3; i++) {
    int y = 80 + (i * 30);
    
    if (i == selectedItem) {
      tft.fillRoundRect(10, y - 5, 220, 25, 5, BLUE);
    }
    
    tft.setTextSize(1);
    tft.setTextColor(WHITE);
    tft.setCursor(20, y);
    tft.print(settings[i]);
    
    if (i == selectedItem) {
      tft.setCursor(200, y);
      tft.print(">");
    }
  }
  
  drawStatusBar();
}

void drawHeader(const char* title) {
  tft.setTextSize(2);
  tft.setTextColor(WHITE);
  tft.setCursor(20, 20);
  tft.print(title);
  
  // Back indicator
  tft.setTextSize(1);
  tft.setTextColor(BLUE);
  tft.setCursor(10, 50);
  tft.print("Menu: Back");
  
  // Separator line
  tft.drawLine(0, 65, 240, 65, GRAY);
}

void drawScrollIndicator() {
  // Show scroll position
  if (maxItems > 1) {
    int barHeight = 50;
    int barY = 150;
    int indicatorHeight = barHeight / maxItems;
    int indicatorY = barY + (selectedItem * indicatorHeight);
    
    // Scroll bar background
    tft.drawRect(230, barY, 8, barHeight, GRAY);
    
    // Scroll indicator
    tft.fillRect(231, indicatorY, 6, indicatorHeight, WHITE);
  }
}

void drawStatusBar() {
  // Bottom status
  tft.drawLine(0, 300, 240, 300, GRAY);
  
  tft.setTextSize(1);
  tft.setTextColor(GRAY);
  tft.setCursor(10, 308);
  tft.print("Rotary: Navigate");
  
  tft.setCursor(150, 308);
  tft.print("Select: OK");
}

void updateUI() {
  // Any dynamic updates can go here
  static unsigned long lastUpdate = 0;
  if (millis() - lastUpdate < 1000) return;
  
  // Update any time-based elements
  lastUpdate = millis();
}

void showAbout() {
  tft.fillScreen(BLACK);
  
  tft.setTextSize(2);
  tft.setTextColor(WHITE);
  tft.setCursor(20, 60);
  tft.print("About iPod");
  
  tft.setTextSize(1);
  tft.setTextColor(GRAY);
  tft.setCursor(20, 100);
  tft.print("ESP32-S3 Music Player");
  tft.setCursor(20, 120);
  tft.print("Rotary Interface v1.0");
  tft.setCursor(20, 140);
  tft.print("Classic iPod Navigation");
  
  tft.setTextColor(BLUE);
  tft.setCursor(20, 180);
  tft.print("Press Menu to return");
  
  // Wait for menu button
  while (digitalRead(BTN_MENU) == HIGH) {
    delay(50);
  }
  
  delay(200); // Debounce
  currentScreen = HOME;
  drawScreen();
}

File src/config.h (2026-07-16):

#ifndef CONFIG_H
#define CONFIG_H

// Hardware Configuration
#define BOARD_ESP32_S3

// =====================================================
//  ESP32-S3 iPod Configuration
//  Pure Touch Interface - No Buttons, No Encoder
//  Components: ESP32-S3 + MSP2806 Display + SD Module
// =====================================================

#ifndef CONFIG_H
#define CONFIG_H

// Hardware Configuration
#define BOARD_ESP32_S3

// Display Configuration - SPI1 Bus (ILI9341 controller)
#define TFT_WIDTH 240
#define TFT_HEIGHT 320
#define TFT_CS 10      // Chip Select
#define TFT_DC 9       // Data/Command
#define TFT_RST 8      // Reset
#define TFT_MOSI 11    // Master Out Slave In
#define TFT_SCLK 12    // Serial Clock
#define TFT_MISO 13    // Master In Slave Out (optional)

// Touch Configuration - SPI2 Bus (XPT2046 controller, same module as display)
#define TOUCH_CS 6     // Touch Chip Select
#define TOUCH_CLK 7    // Touch Clock
#define TOUCH_DIN 5    // Touch Data In
#define TOUCH_DO 4     // Touch Data Out
#define TOUCH_IRQ 3    // Touch Interrupt (optional)
#define TOUCH_ENABLED true

// SD Card Configuration - SPI3 Bus
#define SD_CS 35       // SD Chip Select
#define SD_MOSI 36     // SD Data Out
#define SD_MISO 37     // SD Data In
#define SD_SCLK 38     // SD Clock

// No Physical Input Devices - Pure Touch Interface
// GPIO0, GPIO1, GPIO2 available for future expansion

// USB-C Audio Configuration
#define USB_AUDIO_DP 18        // USB Data Plus
#define USB_AUDIO_DN 19        // USB Data Minus (built-in)
#define USB_VBUS_DETECT 20     // USB Power Detection
#define USB_AUDIO_ENABLE 17    // Audio Enable Control

// Power Management
#define CHARGE_STATUS 21       // Battery Charge Status
#define POWER_ENABLE 39        // Main Power Control
#define BATTERY_ADC 22         // Battery Voltage Monitor

// Bluetooth Configuration
#define BT_DEVICE_NAME "ESP32-iPod"

// Audio Settings
#define SAMPLE_RATE 44100
#define BITS_PER_SAMPLE 16
#define CHANNELS 2

// UI Configuration
#define STATUS_BAR_HEIGHT 20
#define NAV_BAR_HEIGHT 20
#define MAIN_CONTENT_HEIGHT (TFT_HEIGHT - STATUS_BAR_HEIGHT - NAV_BAR_HEIGHT)

// Colors (RGB565)
#define COLOR_BLACK 0x0000
#define COLOR_WHITE 0xFFFF
#define COLOR_BLUE 0x001F
#define COLOR_GRAY 0x8410
#define COLOR_LIGHT_GRAY 0xC618
#define COLOR_DARK_GRAY 0x4208

// File System
#define MAX_FILENAME_LENGTH 256
#define MAX_PATH_LENGTH 512
#define MUSIC_EXTENSIONS ".mp3,.wav,.flac,.m4a,.aac"

#endif // CONFIG_H

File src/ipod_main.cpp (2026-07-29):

/*
 * Complete ESP32-S3 iPod – Final Robust Version
 * 
 * Hardware:
 * - ILI9341 TFT Display (240x320)
 * - XPT2046 Touch Controller
 * - TTP229 16-key Capacitive Keypad
 * - DRV2605L Haptic Motor Driver
 * - PCM5102A I2S DAC
 * - SD Card Module
 * 
 * Features:
 * - Touch screen UI
 * - 16-key keypad navigation with gestures
 * - Haptic feedback
 * - MP3 playback from SD card
 * - Volume control
 * - Now Playing screen with progress
 * - Music library browser
 */

#include <Arduino.h>
#include <TFT_eSPI.h>
#include <SPI.h>
#include <SD.h>
#include <Wire.h>
#include <math.h>
#include "AudioFileSourceSD.h"
#include "AudioGeneratorMP3.h"
#include "AudioOutputI2S.h"
#include "AudioLogger.h"

// ═══════════════════════════════════════════════════════════════
// PIN DEFINITIONS
// ═══════════════════════════════════════════════════════════════

// Display (ILI9341)
#define TFT_CS    10
#define TFT_DC    9
#define TFT_RST   8
#define TFT_MOSI  11
#define TFT_SCLK  12
#define TFT_MISO  13

// Touch (XPT2046)
#define TOUCH_CS  6
#define TOUCH_CLK 7
#define TOUCH_DIN 5
#define TOUCH_DO  4
#define TOUCH_IRQ 3

// SD Card – separate SPI bus (FSPI)
#define SD_CS    35
#define SD_MOSI  36
#define SD_MISO  37
#define SD_SCK   38

// PCM5102A DAC (I2S)
#define I2S_BCK  14
#define I2S_LRC  15
#define I2S_DOUT 16

// DRV2605L Haptic (I2C)
#define HAPTIC_SDA 21
#define HAPTIC_SCL 22

// TTP229 Keypad (serial mode)
#define TTP_SDO 1
#define TTP_SCL 2

// ═══════════════════════════════════════════════════════════════
// COLORS
// ═══════════════════════════════════════════════════════════════
#define C_BLACK      0x0000
#define C_WHITE      0xFFFF
#define C_GRAY       0x8410
#define C_DARKGRAY   0x4208
#define C_LIGHTGRAY  0xC618
#define C_BLUE       0x001F
#define C_DARKBLUE   0x000D
#define C_CYAN       0x07FF
#define C_GREEN      0x07E0
#define C_RED        0xF800
#define C_ORANGE     0xFD20
#define C_YELLOW     0xFFE0

#define C_BG         0x1082   // Very dark grey
#define C_HIGHLIGHT  0x3A9F   // iPod blue selection
#define C_TEXT       0xFFFF
#define C_SUBTEXT    0xAD55
#define C_ACCENT     0x5D1C   // Warm silver

// ═══════════════════════════════════════════════════════════════
// DRV2605L REGISTERS
// ═══════════════════════════════════════════════════════════════
#define DRV_ADDR    0x5A
#define DRV_MODE    0x01
#define DRV_LIB     0x03
#define DRV_SEQ1    0x04
#define DRV_GO      0x0C
#define DRV_FEEDBACK 0x1A

// ═══════════════════════════════════════════════════════════════
// GLOBALS
// ═══════════════════════════════════════════════════════════════
TFT_eSPI tft = TFT_eSPI();
SPIClass sdSPI(FSPI);

// State
enum Screen { SCR_MENU, SCR_LIBRARY, SCR_NOWPLAYING, SCR_VOLUME, SCR_SETTINGS };
Screen currentScreen = SCR_MENU;
int selectedItem  = 0;
bool isPlaying    = false;
int  volume       = 75;
int  currentTrack = 0;
bool hapticOK     = false;
bool sdOK         = false;
bool needsRedraw  = true;

// Touch
bool     touchActive    = false;
uint16_t touchX, touchY;
uint32_t lastTouchTime  = 0;

// Keypad gestures
enum KeyGesture {
    GESTURE_NONE, GESTURE_TAP, GESTURE_DOUBLE_TAP, GESTURE_LONG_PRESS,
    GESTURE_SWIPE_UP, GESTURE_SWIPE_DOWN, GESTURE_SWIPE_LEFT,
    GESTURE_SWIPE_RIGHT, GESTURE_CIRCULAR_CW, GESTURE_CIRCULAR_CCW,
    GESTURE_PINCH_IN, GESTURE_PINCH_OUT
};

#define MAX_TOUCH_HISTORY 20
#define TAP_THRESHOLD 200
#define LONG_PRESS_THRESHOLD 500
#define SWIPE_MIN_KEYS 3
#define CIRCULAR_THRESHOLD 5

uint16_t lastKeys = 0;
uint32_t touchStartTime = 0;
uint32_t lastTapTime = 0;
int keyHistory[MAX_TOUCH_HISTORY] = {};
int keyHistoryIndex = 0;
int keyCount = 0;
bool longPressTriggered = false;

// Progress
uint32_t progressStart = 0;
uint32_t trackDuration = 180000;

// Music library
#define MAX_TRACKS 64
#define PATH_LEN  128
char trackList[MAX_TRACKS][PATH_LEN];
int  trackCount = 0;
int  listOffset = 0;

// Audio error handling
int  lastErrorTrack = -1;
int  retryCount = 0;
#define MAX_RETRIES 2

// Forward declarations
void nextTrack();
void prevTrack();
void togglePlay();
void goBack();
void selectItem();
void handleKeyGesture(KeyGesture gesture);
void updatePlaybackProgress();
void audioStop();
void audioPlay();
void sdReinit();

// ═══════════════════════════════════════════════════════════════
// HAPTIC
// ═══════════════════════════════════════════════════════════════
void hapticWrite(uint8_t reg, uint8_t val) {
    Wire.beginTransmission(DRV_ADDR);
    Wire.write(reg); Wire.write(val);
    Wire.endTransmission();
}

void hapticInit() {
    Wire.begin(HAPTIC_SDA, HAPTIC_SCL);
    Wire.beginTransmission(DRV_ADDR);
    hapticOK = (Wire.endTransmission() == 0);
    if (!hapticOK) { Serial.println("Haptic: not found"); return; }
    hapticWrite(DRV_MODE,     0x00);
    hapticWrite(DRV_FEEDBACK, 0x36);
    hapticWrite(DRV_LIB,      1);
    Serial.println("Haptic: OK");
}

void hapticBuzz(uint8_t effect) {
    if (!hapticOK) return;
    hapticWrite(DRV_SEQ1, effect);
    hapticWrite(0x05, 0);
    hapticWrite(DRV_GO, 0x01);
}

// ═══════════════════════════════════════════════════════════════
// SD CARD – safe init & reinit
// ═══════════════════════════════════════════════════════════════
void sdReinit() {
    sdSPI.end();
    sdSPI.begin(SD_SCK, SD_MISO, SD_MOSI, SD_CS);
    uint32_t speeds[] = {4000000, 8000000, 10000000};
    for (int i = 0; i < 3; i++) {
        sdOK = SD.begin(SD_CS, sdSPI, speeds[i]);
        if (sdOK) {
            Serial.printf("SD reinit OK at %d Hz\n", speeds[i]);
            return;
        }
        sdSPI.end();
        sdSPI.begin(SD_SCK, SD_MISO, SD_MOSI, SD_CS);
    }
    Serial.println("SD reinit failed");
}

void sdInit() {
    sdReinit(); // use the same logic
}

bool isMusicFile(const char* name) {
    const char* base = strrchr(name, '/');
    base = base ? base + 1 : name;
    if (base[0] == '.') return false;
    const char* ext = strrchr(name, '.');
    if (!ext) return false;
    return strcasecmp(ext, ".mp3") == 0;
}

void scanMusic(File dir, const String& prefix = "/", int depth = 0) {
    while (trackCount < MAX_TRACKS) {
        File f = dir.openNextFile();
        if (!f) break;
        String name = f.name();
        String fullPath;
        if (name.startsWith("/")) {
            fullPath = name;
        } else {
            fullPath = prefix;
            if (!fullPath.endsWith("/")) fullPath += "/";
            fullPath += name;
        }
        if (f.isDirectory() && depth < 2) {
            scanMusic(f, fullPath, depth + 1);
        } else if (isMusicFile(f.name())) {
            strlcpy(trackList[trackCount], fullPath.c_str(), PATH_LEN);
            trackCount++;
        }
        f.close();
    }
}

void loadMusicLibrary() {
    trackCount = 0;
    if (!sdOK) return;
    File root = SD.open("/");
    scanMusic(root);
    root.close();
    Serial.printf("Music: %d tracks found\n", trackCount);
    for (int i = 0; i < min(5, trackCount); i++) {
        Serial.printf("  [%d] %s\n", i, trackList[i]);
    }
}
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

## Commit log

2026-07-16 chore: add project initialization with documentation and firmware
    - Add comprehensive documentation suite covering hardware setup, wiring guides, and troubleshooting
    - Add PlatformIO configuration with ESP32-S3 and Arduino framework setup
    - Add complete firmware codebase with display, touch, audio, input, power, and storage managers
    - Add 3D model for iPod case design in OpenSCAD format
    - Add PCB design specifications and KiCad schematic files
    - Add gitignore for PlatformIO build artifacts and development tools
    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
    [ipod_case.scad, ipod_haptic_schematic.kicad_sch]
2026-07-29 feat(ipod): add PCB design and firmware components
    - Add KiCad schematic and PCB layout files for iPod hardware redesign
    - Add firmware source files for audio DAC (PCM5102A), haptic driver (DRV2605), and SD card diagnostics
    - Add main iPod firmware implementation with 16-key TTP229 touchpad support
    - Update platformio.ini configuration for project dependencies
    - Include backup of PCB design and temporary lock files for version control
    [ipod.kicad_pcb, ipod.kicad_sch]
2026-07-30 feat: add fan header footprint and update PCB project configuration files
    [ipod.kicad_pcb, ipod.kicad_sch]
